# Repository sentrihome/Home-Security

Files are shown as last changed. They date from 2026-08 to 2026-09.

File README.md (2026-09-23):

# Home Security System — Full Architecture

Status: design draft — SoftAP shipping; Pi hub (`pi_hub`) barebones in repo; live/clips/Drive stubs pending full impl
Scope: end-to-end system — ESP32 hardware, provisioning, sensor pairing, security model, protocol specs, Pi/app/cloud product layer (alerts, live, clips), and known open items.
Merges: original ESP32 hardware architecture + `Local-First Architecture Storyboard` (mobile/, Pi, Tailscale, FCM/ntfy, Drive).
Pi software: Python SoftAP gate + one `pi_hub` process (not the retired Node `rasberry_pi_app` / cloud stack) — see **D20** and §13.

---
## Branch Naming Convention
Three types of tasks:
1. Rasberry Pi pie
2. ESP esp
3. Mobile app mob
Name of person working: firstname
Bitesized task: task

So the branch name will be: type-firstname-task

## Quick nav

| Section | Contents |
|---|---|
| [1](#1-system-overview) | System overview & diagram |
| [2](#2-hardware--component-roles) | Every component's role |
| [2.1](#21-esp32-architecture-diagram) | ESP32 hardware diagram — networks, UART, credential flow |
| [3](#3-decision-log) | Locked product choices |
| [4](#4-console-provisioning-flow) | Phone → console WROOM → S3 → home WiFi |
| [5](#5-sensor-pairing-flow) | Phone → sensor → console WROOM |
| [6](#6-default-ap-credentials-setup-time) | Anti-eavesdropping setup credentials |
| [7](#7-credential--key-model) | The three secrets, who holds what |
| [8](#8-failure-handling-provisioning) | WiFi connect failure/retry |
| [9](#9-uart-protocol-wroom--s3) | Frame format, command set |
| [10](#10-setup-ap-encryption) | WPA2 requirement on all setup APs |
| [11](#11-psk-recovery--backup) | Pi as PSK backup, tied to §16 |
| [12](#12-reboot--reconnect-behavior) | Console/S3/sensor reboot handling |
| [13](#13-pi-setup--product-hub) | SoftAP gate → `pi_hub` (live/clips); how it works & deploy |
| [14](#14-intruder-alerts-android-fcm--ios-ntfysh) | FCM (Android), ntfy.sh (iOS) |
| [15](#15-on-demand-livestream-tailscale) | Live only while app is open |
| [16](#16-pi--s3-link-confirmed-endpoints-transport-tbd) | Confirmed Pi↔S3 endpoints; transport still TBD |
| [17](#17-clips-pi-cache--google-drive) | Clip capture, cache, upload, playback |
| [18](#18-google-token-handoff) | OAuth refresh token to Pi |
| [18.1](#181-what-the-pi-needs-phone--pi-contract) | Locked JSON contract for the phone handoff |
| [19](#19-motion-event-pipeline-partially-resolved) | Camera confirmed Pi-only; alert-pipeline scope still open |
| [20](#20-arm--disarm-state-machine) | State ownership, authorization, entry/exit, sensor behavior |
| [21](#21-out-of-scope) | Explicit non-goals |
| [22](#22-open-items) | Full consolidated list |
| [23](#23-physical--manufacturing-notes) | Enclosure & label handling |

---

## 1. System Overview

Three physical subsystems, tied together by two links that are fully specified and one that is not yet:

```mermaid
flowchart TB
  subgraph sensors [Sensor Network]
    Sen1[Sensor WROOM]
    Sen2[Sensor WROOM]
  end

  subgraph console [Central Console]
    CW[Console WROOM<br/>AP + hub]
    S3[ESP32-S3<br/>station, display]
    Sen1 -->|WiFi, sensor_key auth| CW
    Sen2 -->|WiFi, sensor_key auth| CW
    CW <-->|UART, framed| S3
  end

  subgraph home [Home LAN / Cloud Layer]
    Pi[Raspberry Pi<br/>static IP, health, alerts, live, clips]
    FCM[FCM - Android]
    Ntfy[ntfy.sh - iOS]
    Drive[Google Drive]
    TS[Tailscale]
    S3 -.->|§16, endpoints confirmed<br/>transport TBD| Pi
    Pi -->|motion| FCM
    Pi -->|motion| Ntfy
    Pi --> Drive
    Pi <--> TS
  end

  subgraph phone [Mobile App]
    App[React Native app]
    FCM -->|tap| App
    Ntfy -->|tap/open| App
    App <-->|setup, live, clips| Pi
    App -.->|setup| CW
  end
```

**Fully specified today:** sensor ↔ console WROOM (WiFi + `sensor_key`), console WROOM ↔ S3 (UART, framed), phone ↔ Pi (SoftAP setup, health check, Tailscale, OAuth handoff, FCM/ntfy targets, Drive playback).

**Confirmed but not yet fully specified:** S3 ↔ Pi. The endpoints are settled — this is a direct Pi↔S3 link, not routed through the WROOM (§16, §20) — but the transport mechanism (static IP / mDNS / hybrid), framing, and auth are still open. Everything downstream of it (motion-triggered alerts reaching the Pi, PSK backup reaching the Pi, the PIN-set flow) depends on this transport being finalized.

---

## 2. Hardware & Component Roles

| Component | Role | WiFi / Network Mode | Responsibilities |
|---|---|---|---|
| ESP32-S3 | Central console | Station (home WiFi) | Display, keypad (PIN entry for disarm — see §20), stores home WiFi creds, stores sensor keys, **stores the disarm PIN in NVS**, relays credentials/status to console WROOM over UART. Motion/event relay toward Pi confirmed required — see §16, §20. |
| ESP32-WROOM (console-side) | Sensor hub / pairing surface | Access Point (persistent, currently `"espwifi"` — SSID string is not a hard spec requirement, any static value works) | Hosts sensor network, relays sensor data to S3 via UART, validates sensor auth (`sensor_key`), generates pairing credentials and the sensor-network PSK |
| ESP32-WROOM (sensor units) | Sensors | Station → connects to console WROOM's AP | Motion/door/etc. detection, sends events authenticated with `sensor_key`. One of two motion-alert triggers, alongside the Pi's camera detector — see §19. |
| Raspberry Pi | Setup relay, PSK backup, product hub | AP (setup only) → Station (post-setup, static IP `192.168.0.236`) | **Initializes first, before console provisioning — see §4, §13.** SoftAP then **`pi_hub`** on `:4000`. Owns the camera; OpenCV person detection (§19); FCM/ntfy alerts; WebRTC live; Drive clip upload; PSK backup pending §16 |
| Mobile App (React Native, `mobile/`) | Orchestrator / client | N/A | Walks the user through both the Pi setup flow and the console/sensor provisioning flow, holds home WiFi creds in memory only during setup, stores the sensor-network PSK for future pairing, saves the Pi host, registers for push (FCM/ntfy), handles Google OAuth and hands the refresh token to the Pi, plays live (via Tailscale) and clips (via Drive) |

**Confirmed: no camera on any ESP32.** The camera is Pi-attached only. It is no longer monitoring-only: the Pi runs OpenCV person detection on the camera feed as a second, independent motion-alert trigger alongside the ESP32 sensor network. See §19.

**Confirmed: the console has a physical keypad**, used for PIN entry on disarm (§20). **The PIN itself is stored in S3 NVS**, not on the Pi — this creates a flagged tension with the Pi-as-state-authority decision, see §20. **No local audio/siren hardware is planned for initial release** — the console is display + keypad only; Bluetooth speaker support (as a post-launch siren option) is roadmap, not v1.

**Key architectural point:** the console WROOM's AP is *not* home WiFi — it's a separate, persistent local network (currently named `"espwifi"`, but the name itself isn't a spec requirement — see §22 item 6 for the planned move to per-unit SSIDs) that only the S3 (via UART) and paired sensors ever touch. The S3 never joins this network over WiFi. Separately, the Pi runs on the actual home LAN with its own static IP, reachable by the phone directly and, once §16 is resolved, by the S3.

### 2.1 ESP32 Architecture Diagram

```mermaid
flowchart TB
  Phone([Mobile App])
  Router{{Home WiFi Router}}

  subgraph HomeNet [" Home WiFi — station side "]
    S3[ESP32-S3<br/>Central Console<br/>Station + Display + Keypad]
    NVSs[(S3 NVS<br/>home WiFi creds<br/>sensor_keys, disarm PIN)]
  end

  subgraph HSNet [" Console WROOM's Persistent AP — WPA2, SSID not spec-fixed "]
    CW[ESP32-WROOM<br/>Console Hub]
    NVSc[(WROOM NVS<br/>sensor PSK<br/>paired sensor_keys)]
    CW --- NVSc

    Sensor1[Sensor WROOM 1]
    Sensor2[Sensor WROOM 2]
    SensorN[Sensor WROOM ... up to 10]
  end

  Phone -. "1. setup: home WiFi creds<br/>over unique-per-unit setup AP" .-> CW
  CW == "2. UART, framed<br/>home WiFi creds" ==> S3
  S3 -- "2. store" --> NVSs
  S3 -- "3. join as station" --> Router
  S3 == "4. UART: connection result" ==> CW
  CW -. "5. sensor-network PSK<br/>generated, sent to phone" .-> Phone

  Phone -. "6. pairing: PSK + sensor_key<br/>over sensor's own setup AP" .-> Sensor1
  Sensor1 -- "WiFi + sensor_key auth" --> CW
  Sensor2 -- "WiFi + sensor_key auth" --> CW
  SensorN -- "WiFi + sensor_key auth" --> CW

  CW == "ongoing: sensor event relay" ==> S3

  classDef dashed stroke-dasharray: 5 5;
  class Phone dashed;
```

**Reading the diagram:**
- **Dashed arrows** — one-time setup/pairing traffic over a temporary WPA2 setup AP (§4, §5, §6).
- **Double solid arrows (`==`)** — the framed UART link between WROOM and S3 (§9), carrying both provisioning handoff and ongoing sensor-event relay.
- **Single solid arrows** — persistent WiFi connections: sensors to the console WROOM's AP (network-level PSK + application-level `sensor_key`, §7), and the S3 to the home router.
- **Two distinct WiFi networks, never bridged over the air:** home WiFi (S3 only) and the console WROOM's persistent AP network (WROOM + sensors — SSID currently `"espwifi"`, not a fixed spec value). The only link between them is the physical UART trace inside the enclosure (§23).

---

## 3. Decision Log

| ID | Decision | Choice | Notes |
|---|---|---|---|
| D1 | Mobile client | React Native Expo app in `mobile/` | Dev/prod build for push; not Expo Go |
| D2 | Android alerts | `expo-notifications` + FCM | Pi sends FCM on motion |
| D3 | iOS alerts | Public ntfy.sh | Secret topic; no Tailscale required for the buzz |
| D4 | Livestream path | Tailscale to Pi | On-demand, only while app is open |
| D5 | Alert transport | No persistent WebSocket | FCM / ntfy wake the user instead |
| D6 | Clip storage | Pi cache → Google Drive | App reads Drive; no Tailscale needed for clips |
| D7 | Drive auth | Phone Google OAuth → refresh token handed to Pi | Not password-based; `drive.file` scope only |
| D8 | Remote product tunnel | Tailscale (not ngrok/Cloudflare as product) | ngrok OK for ad-hoc dev only |
| D9 | Pi ↔ S3 discovery/transport | Endpoints confirmed (Pi ↔ S3 direct); mechanism **TBD** | mDNS or static IP — see §16 |
| D10 | Cloud S3 / cloud-backend clips | Retired as a product path | Local-first + Drive instead |
| D11 | Sensor-network auth | WiFi PSK (network-level) + `sensor_key` (application-level) | See §7 |
| D12 | Sensor AP fallback on disconnect | None — physical reset only | Prevents jamming-based sensor knockout, see §12 |
| D13 | Setup AP credentials | Unique per unit (batch-derived minimum, MAC-HMAC preferred) | Prevents shared-default eavesdropping, see §6 |
| D14 | Home WiFi credential storage | S3 NVS only | WROOM relays over UART but never persists home WiFi creds — see §7, §2.1 |
| D15 | Camera hardware | Pi-attached only, no ESP32 has a camera | See §2, §19 |
| D16 | UART frame format | `SYNC(2B) \| CMD(1B) \| LEN(2B) \| PAYLOAD \| CRC(1-2B)`, bidirectional | Locked before coding — see §9 |
| D17 | Sensor-network PSK lifecycle | Never regenerated on WROOM reboot — persists across reboots | Regenerating would force re-pairing every paired sensor, see §12 |
| D18 | UART link security | Plaintext, trusted via physical enclosure only | Accepted risk given enclosed PCB, not link-layer encrypted — see §9, §23 |
| D19 | "Encrypted SSID" terminology | Means a high-entropy random **PSK**, not literal SSID encryption | SSIDs broadcast in cleartext regardless — see §7 |
| D20 | Pi product software | **Python SoftAP + one `pi_hub` process** (Flask); do **not** revive Node `rasberry_pi_app` or cloud `:3001` as product | SoftAP is the boot gate; live + clips share one process so they don't fight over `/dev/video0`. Old Node pushed HLS/clips to cloud — local-first serves HLS from Pi and uploads clips to Drive. Code: `rasberry-pi-setup/`. See §13 |

---

## 4. Console Provisioning Flow

Goal: get the S3 onto home WiFi and generate the sensor-network PSK, using the phone as a one-time relay. **Confirmed: this runs after Pi initialization (§13) — Pi setup happens first in the unified onboarding flow.**

1. User enters home WiFi SSID + password once in the app. Held in memory only — never persisted to disk.
2. Phone connects to the console WROOM's setup AP (unique per-unit credentials, WPA2-secured — §6, §10).
3. Phone sends the home WiFi SSID/pass to the WROOM.
4. WROOM relays the credentials to the S3 over UART (framed — §9).
5. S3 attempts to join home WiFi as a station, bounded timeout (~9s), signaled on `IP_EVENT_STA_GOT_IP` (not `WIFI_EVENT_STA_CONNECTED` — association without a leased IP must not report success).
6. S3 reports the connection result (success or specific failure reason) back to WROOM over UART.
7. On success: WROOM generates a random, high-entropy sensor-network PSK (§7), if not already generated on first boot. SSID is a static, fixed string (`"espwifi"`) — not MAC-derived (see §22 item 6 for the planned move to per-unit SSIDs). Brings up its persistent AP under these credentials and sends the PSK back to the phone over the still-open setup link.
8. Phone stores the PSK for future sensor pairing. WROOM's setup AP closes / transitions to sensor-hub-only mode. **Currently commented out in firmware** for debugging — the setup AP is left running past this point so pairing traffic can be inspected/retried without a fresh flash cycle. Must be re-enabled before this leaves dev.
9. WROOM sends the PSK to the S3 over UART; the S3 pushes a copy to the Pi for backup (§16, Pi↔S3 link) — this step depends on §16's transport being finalized; it is not yet a working link.
10. On failure: see §8.

This is a one-time flow, not repeated per sensor.

---

## 5. Sensor Pairing Flow

Done once per sensor, any time after console provisioning, using the PSK the phone already has stored.

1. New sensor boots in AP mode, broadcasting its own unique per-unit setup AP (§6).
2. Phone connects to the sensor's setup AP.
3. Phone sends the console WROOM's sensor-network SSID + PSK to the sensor.
4. Sensor switches to station mode and connects to the console WROOM's persistent AP.
5. Sensor authenticates at the application layer using `sensor_key` (§7) — WiFi-level connection alone does not grant trust.
6. WROOM validates the `sensor_key`, marks the sensor as paired, stores the key in NVS, and begins relaying its events to the S3.

**Constraint — pairing requires the WROOM AP not be at capacity:** the same persistent AP serves both ongoing sensor traffic and new-sensor pairing. Confirmed system limit: sensor count will not exceed 10 (ESP32 SoftAP station cap). App should check station count before initiating pairing and prompt the user if the AP is at or near capacity (exact UX not yet finalized — §22).

---

## 6. Default AP Credentials (Setup-Time)

**Current state: hardcoded shared default.** All units currently ship with the same fixed setup AP credentials, baked into firmware — not per-unit, not batch-derived. This reopens the eavesdropping window the design intends to close: anyone who knows the shared default (e.g. from a leaked unit, teardown, or public firmware) could intercept home WiFi or PSK credentials on any other unit's setup AP during provisioning.

**Planned: unique-per-unit credentials**, not a shared default — this is the fix for the above. Target approach: batch-unique credentials at minimum (shipped per manufacturing batch), with an upgrade path to fully per-device derived credentials:

```
ap_password = HMAC(batch_secret, MAC_address) → encode → print on label/QR
```

No provisioning database required — each unit would derive its own password locally and deterministically at boot from its own MAC address and a batch secret baked into firmware at flash time. Not yet implemented — see §22.

Requirements regardless of tier (apply today, independent of hardcoded-vs-derived):

- Setup AP is WPA2-secured using the current password — never open (§10).
- Setup AP auto-closes after a timeout (2–5 minutes) if no provisioning occurs.
- Re-entering setup/pairing mode after timeout requires a physical button press, not an always-available AP.
- The printed label/QR (once per-unit derivation lands) must not be visible on the outside of retail packaging (§23). Not applicable yet under the current shared-default state — there's nothing unit-specific to print.

---

## 7. Credential & Key Model

Four distinct secrets exist on the ESP32 side. They must not be conflated:

| Secret | Generated by | Purpose | Stored where |
|---|---|---|---|
| Home WiFi SSID/pass | User (typed once) | Lets S3 join home WiFi | S3 NVS only — WROOM does not persist it, only relays via UART |
| Sensor-network PSK | Console WROOM (random, high-entropy, 32-char alphanumeric via `esp_random()`) | WPA2 password for the WROOM's persistent AP | Phone app (primary), Pi (backup — pending §16), WROOM NVS |
| `sensor_key` | Console WROOM, generated uniquely per sensor during pairing | Application-layer authentication of each sensor after WiFi connection | WROOM NVS (per paired sensor), sensor's own NVS |
| Disarm PIN | User, set via the mobile app | Authorizes disarm from the console keypad or the app — see §20 | **S3 NVS.** This is the odd one out: unlike the other three, it's not device-provisioning material, and its storage location creates a flagged tension with the Pi being the arm/disarm state authority — see §20. |

**Why `sensor_key` matters:** the sensor-network PSK is shared across all paired sensors — anyone who obtains it could join the WiFi network. `sensor_key` prevents an arbitrary WiFi-connected device from impersonating a sensor; the WROOM only accepts data from sensors presenting a valid, previously-issued key.

A parallel pattern exists on the product side: the Drive OAuth **refresh token** (§18) is a fifth secret, phone-mediated to the Pi the same way the PSK is phone-mediated to sensors — see §22 for the open question of unifying these into one "phone → device secret handoff" primitive.

Terminology note: nothing here is literal SSID encryption — SSIDs broadcast in cleartext regardless. What's unique/high-entropy is the **PSK** and the **`sensor_key`**, not the SSID (which can simply be MAC-derived and unique).

---

## 8. Failure Handling (Provisioning)

**Confirmed: binary outcome only.** The S3 reports `wifiConnection: true` or `wifiConnection: false` over UART — no reason code is surfaced to the WROOM, the phone, or the app. Wrong password, SSID not found, weak signal, and any other `WIFI_EVENT_STA_DISCONNECTED` cause all collapse to the same `false`. The app's only recourse on failure is to let the user retry.

`wifi_event_sta_disconnected_t->reason` is captured firmware-side (S3) at the point of disconnect but intentionally not forwarded over UART or wired into any command — available for future use if reason-level UX is ever built, but out of scope now.

Rules:

- Setup AP (WROOM or Pi) stays alive across a failed attempt — not torn down until success is confirmed.
- No retry cap on the S3's underlying `esp_wifi_connect()` reconnect loop — it retries indefinitely on disconnect. This is by design: a `false` result has already reached the phone, so the user can re-enter credentials and trigger a fresh attempt at any time; capping retries and requiring a physical button adds friction without a corresponding safety need here (contrast §12's sensor reconnect, where the no-fallback cap is a deliberate anti-jamming measure, not a UX one).

---

## 9. UART Protocol (WROOM ↔ S3)

Bidirectional framing required — both directions carry meaningful payloads.

```
[SYNC: 0xAA 0x55] [CMD: 1B] [LEN: 2B] [PAYLOAD: N bytes] [CRC: 1-2B]
```

Minimum command set to define before coding:

- `WROOM → S3`: home WiFi SSID/pass payload
- `S3 → WROOM`: connection result (success / specific failure reason)
- `WROOM → S3`: sensor event relay (post-pairing, ongoing telemetry)
- `S3 → WROOM`: commands (arm/disarm, etc.) to be relayed onward to sensors
- `S3 → WROOM`: status/heartbeat
- **`WROOM → S3`: motion/event notification tagged for Pi relay** — new command needed once §16's transport lands; distinct from routine telemetry if it needs different urgency/handling given the alert latency budget (§16)

**Flagged ambiguity:** the "commands relayed onward to sensors" line above implies each sensor is told the current arm state directly. But §20 states sensors "relay to the Pi only while armed," and the "sensor event relay" line above describes WROOM→S3 telemetry as unconditional/ongoing — these two aren't obviously the same design. Not yet decided: does arm/disarm state propagate all the way to each sensor (so a disarmed sensor stops transmitting entirely — relevant for battery life, §22 item 10), or do sensors always transmit and the WROOM/S3/Pi layer decides whether to act on it? Added to Open Items (§22).

The disarm PIN does **not** need a UART command — it's confirmed to travel `Pi → S3` directly (§16, §20) and never touches the WROOM.

Without framing, a byte-stream split across two reads on either side will silently corrupt credential or event payloads — this must be a checksummed, framed protocol.

Trust assumption: this UART link is internal to an enclosed PCB inside the house; physical access implies the system is already compromised, so plaintext credentials on this link are an accepted risk given the enclosure.

---

## 10. Setup AP Encryption

All temporary setup APs (Pi, console WROOM, sensor WROOMs) must run WPA2 using their unique per-unit password (§6) — never open. An open setup AP would let anyone in range passively sniff home WiFi credentials and the sensor-network PSK regardless of how unguessable the SSID is. Unique SSID ≠ encryption.

---

## 11. PSK Recovery / Backup

The phone app is not the sole holder of the sensor-network PSK. A backup copy should be pushed to the Raspberry Pi once both are on home WiFi.

**This depends on §16 (Pi↔S3 link), whose endpoints are now confirmed but transport/auth is still undesigned.** Do not build a one-off transport just for this — once §16's transport and auth are chosen, reuse them for the PSK backup push rather than inventing a second channel.

Open items:

- Push vs. pull, and behavior if the Pi is offline or unprovisioned when the PSK is generated — console/sensor setup should not block on Pi availability.
- Whether the Pi is required for day-to-day operation or purely a setup/recovery aid. Current intent: console and sensors keep operating autonomously if the Pi is off or removed — but §16 makes the *alerting* path (not sensor operation) look Pi-dependent. See §16.

---

## 12. Reboot / Reconnect Behavior

- **Console WROOM reboot:** AP credentials restored from NVS immediately on boot — same SSID/PSK, never regenerated (sensors already hold the old ones and would need re-pairing otherwise). Sensor data buffered by WROOM if the S3 link is briefly down, capped queue (e.g., 50 messages), dropping oldest on overflow.
- **S3 reboot:** WROOM's AP and sensor connections unaffected. WROOM buffers sensor events until UART with the S3 resumes.
- **Sensor loses connection to console:** sensor retries using the console's MAC address (not IP) with exponential backoff. **No automatic fallback to AP mode** — deliberate, to prevent a jamming attack from forcing sensors into a re-pairable, disconnected state (e.g., disabling motion detection). Re-entering pairing/setup mode requires a physical action (button hold).

---

## 13. Pi Setup & Product Hub

The Pi runs its own independent SoftAP-based setup flow (implemented under `rasberry-pi-setup/`), separate from the console's provisioning in §4. **Confirmed: this runs first in the unified onboarding flow** — the console's setup (§4) happens after Pi initialization completes, not in parallel and not the other way around.

**D20 (locked):** keep SoftAP in Python; run live + clips + Drive as modules of **one** hub process (`pi_hub`). Do not bring back the old Node `rasberry_pi_app` / cloud-backend split as the product path. SoftAP is the **network gate**; the hub starts only after home Wi‑Fi is up. SoftAP and hub never both bind `:4000`.

### How it works

```
Boot → pi-setup.service → pi-setup-boot.sh
         │
         ├─ no / bad Wi‑Fi  → SoftAP HomeSecurity-Setup + pi-setup-api.py :4000
         │                     (GET /status, /scan, POST /wifi)
         │                     hub stopped; .hub-ready removed
         │
         └─ Wi‑Fi OK at 192.168.0.236
                              → touch ~/homesecurity/.hub-ready
                              → systemctl start pi-hub
                              → one Flask process :4000 (live + clips + Drive)
```

| Piece | Kind | When |
|---|---|---|
| `pi-setup-boot.sh` + SoftAP API | bash + small Flask | Always / unconfigured |
| `pi_hub` (`app.py` + `live` / `clips` / `drive`) | one Python app | Configured + on LAN |
| ffmpeg | subprocess from `live` / `clips` | On demand — not a separate daemon |

**Onboarding steps (product):**

1. Unconfigured Pi boots SoftAP (`HomeSecurity-Setup`).
2. User joins SoftAP; app sends home WiFi credentials (`POST /wifi`).
3. Pi joins home LAN at static IP `192.168.0.236`.
4. App verifies hub (`GET /health` → `mode: "hub"`), saves Pi host.
5. User installs Tailscale on Pi and phone (same tailnet); MagicDNS or `100.x` for live (§15).
6. *(Future)* App pairs a long-lived device token with the Pi for API auth — recommended to also auth §16 PSK backup.

**Hub API (after Wi‑Fi; stubs in repo, full ffmpeg/Drive TBD):**

| Method | Path | Module |
|---|---|---|
| GET | `/health` | hub (`mode: hub`) |
| POST | `/start` `/stop` | `pi_hub.live` — on-demand HLS |
| POST | `/motion` | `pi_hub.clips` → `pi_hub.drive` |
| POST | `/auth/drive` | `pi_hub.drive` — refresh token from app |
| GET | `/hls/<file>` | HLS playlist/segments |

Repo layout: `rasberry-pi-setup/pi_hub/`, units in `rasberry-pi-setup/systemd/`. Detail + troubleshooting: [`rasberry-pi-setup/PI-SOFTAP-README.md`](rasberry-pi-setup/PI-SOFTAP-README.md).

### Deploying changes to the Pi

**CI (every push under `rasberry-pi-setup/`):** GitHub Actions workflow [`.github/workflows/pi-deploy.yml`](.github/workflows/pi-deploy.yml) SSHs to the Pi (via Tailscale when `TS_AUTHKEY` is set), `git fetch` + checkout of that commit, runs `rasberry-pi-setup/scripts/ci-pull-deploy.sh` (install + restart `pi-hub`). Secrets and one-time Pi bootstrap: [`PI-SOFTAP-README.md`](rasberry-pi-setup/PI-SOFTAP-README.md) → **CI deploy**.

**Manual from a LAN machine** (Pi at `192.168.0.236`, user `koushik`):

```bash
cd rasberry-pi-setup
./deploy-to-pi.sh
# optional: PI_IP=192.168.0.236 PI_USER=koushik ./deploy-to-pi.sh
```

What that does:

1. Copies SoftAP scripts, `pi_hub/`, `systemd/*.service`, and `requirements.txt` to `/tmp/rasberry-pi-setup` on the Pi.
2. Runs `sudo ./install-pi-setup.sh` on the Pi — installs deps (Flask, ffmpeg, jq), copies files to `/home/koushik/`, installs systemd units, enables `pi-setup.service`.
3. Hub is **not** auto-enabled for multi-user boot by itself; `pi-setup-boot.sh` starts `pi-hub` only after home Wi‑Fi succeeds.

**After manual deploy:**

```bash
ssh koushik@192.168.0.236 'sudo reboot'   # clean SoftAP → hub handoff
# once on home Wi‑Fi:
curl http://192.168.0.236:4000/health     # expect "mode":"hub"
```

**Iterate without full reinstall** (hub code only, Pi already provisioned):

```bash
scp -r rasberry-pi-setup/pi_hub koushik@192.168.0.236:/home/koushik/
ssh koushik@192.168.0.236 'sudo touch /home/koushik/homesecurity/.hub-ready && sudo systemctl restart pi-hub'
```

**Logs:** SoftAP → `tail -f /var/log/pi-setup.log` · Hub → `journalctl -u pi-hub -f`

### Test protocol

| # | Step | Expected |
|---|---|---|
| 13.1 | Pi in SoftAP or already on LAN | Setup screen usable |
| 13.2 | Complete SoftAP creds; phone on home WiFi | `GET http://192.168.0.236:4000/health` succeeds with `mode: hub` |
| 13.3 | Kill and reopen app | Saved Pi host still present |
| 13.4 | Tailscale connected on Pi and phone | Both show in `tailscale status`; ping works |
| 13.5 | **Fail:** phone on cellular, Tailscale off, hit LAN IP | Health fails; clear "unreachable" UI, not a hang |

**Failure modes:** SoftAP scan fails → not on `HomeSecurity-Setup`. Health 404/timeout → hub not started or still in SoftAP-only mode. Wrong subnet → static IP mismatch. Port conflict → SoftAP API and hub both tried to bind `:4000` (boot script should prevent this).

---

## 14. Intruder Alerts: Android (FCM) & iOS (ntfy.sh)

No persistent WebSocket for alerts (D5) — push services wake the user instead.

### Android — FCM

1. Dev/prod build registers for push (`expo-notifications` + FCM).
2. App sends its FCM device token to the Pi (LAN or Tailscale) once paired.
3. On motion, Pi POSTs to FCM with title/body (and optional deep-link data).
4. OS shows a lock-screen notification.
5. Tap → app opens (Live or Alerts screen).

**Failure modes:** Expo Go used → push unreliable/wrong app id. Token never uploaded → Pi has nothing to target. Pi's outbound network to Google blocked → send fails silently unless logged.

### iOS — ntfy.sh

1. Generate a high-entropy secret topic (treat like a password); store on Pi, show once in app Settings.
2. User subscribes to `https://ntfy.sh/<topic>` (ntfy iOS app for v1).
3. On motion, Pi POSTs to `https://ntfy.sh/<topic>`.
4. User sees the notification; opens the app when ready.
5. Live still requires Tailscale (§15) — ntfy carries no video.

**Failure modes:** topic leaked → strangers can spam or snoop titles. ntfy.sh outage → no iOS buzz (LAN live still works independently). User never subscribed → silent miss.

### Combined test targets

Motion → notification within **≤ 15 seconds** on both platforms. This budget matters directly for §16 — see the latency note there.

---

## 15. On-Demand Livestream (Tailscale)

Live only while the app is open — no background streaming.

1. User opens the app (often from an FCM/ntfy tap).
2. App resolves the Pi's base URL: prefers Tailscale host when off-LAN, else saved LAN IP.
3. Optional `POST /start`, then play HLS from the Pi.
4. User leaves the Live screen → stop requesting segments; no persistent socket.
5. If Tailscale is disconnected → clear error: enable Tailscale or join home WiFi.

**Failure modes:** playing the LAN IP while away → timeout. Firewall/CGNAT rare with Tailscale but DERP relay may add latency. Heavy cellular data usage — warn in UI if needed.

---

## 16. Pi ↔ S3 Link (Confirmed Endpoints, Transport TBD)

**Status: endpoints confirmed, transport/framing/auth still undesigned.** This is the single biggest remaining gap connecting the ESP32 hardware architecture to the product layer.

**Confirmed: this link connects the Pi directly to the S3** — not the WROOM. Consistent with the rest of this document's topology (§1, §2.1), the S3 is the only ESP32 with home-LAN reachability; the WROOM has no home-WiFi connectivity and is not involved in Pi-facing traffic. The WROOM's role remains limited to the isolated sensor-network AP and UART with the S3.

Everything downstream depends on this link:

- §11's PSK backup push (S3 → Pi, sourced from the WROOM via UART, then relayed by S3)
- Motion-triggered alerts (§14) actually firing, confirmed required per §19's resolved motion-alert pipeline
- The PIN-set flow and arm/disarm coordination (§20), confirmed to route `Pi → S3` directly

### Candidates (not yet chosen)

| Option | Idea | Pros | Cons |
|---|---|---|---|
| Static IP | Pi stays at `192.168.0.236`; S3 configured with that IP | Simple; already assumed elsewhere in the Pi setup docs | Breaks if the subnet changes |
| mDNS | Pi advertises e.g. `homesecurity-pi.local` | No hard-coded IP | mDNS can be flaky on some routers / ESP network stacks |
| Hybrid | Static default + mDNS fallback | Resilient | More firmware and app work |

### What needs to be specified once a candidate is chosen

- **Transport & framing** for S3 → Pi messages (motion events, PSK backup), analogous to §9's UART framing.
- **Authentication** — should not be an unauthenticated push; anything on the LAN claiming to be "the Pi" (or "the console") must not be trusted by default. Recommended: reuse the "paired device token" mechanism already planned for phone↔Pi auth (§13, step 6) rather than inventing a third auth scheme.
- **Latency budget** — the alert path's ≤15s target (§14) has to cover sensor → WROOM (radio) → UART (WROOM→S3) → this link (S3→Pi) → Pi → FCM/ntfy → phone OS, end to end. Each hop needs its own bounded latency; there isn't much slack in 15 seconds once every hop is accounted for.
- **Availability behavior** — if this link is down (Pi off, rebooting, off the LAN), does the console have any fallback alerting path, or is a live Pi a hard dependency for every motion alert? This is currently undefined and should be decided explicitly rather than defaulting to "no alert."

---

## 17. Clips: Pi Cache → Google Drive

1. User signs into Google in the phone app (`access_type=offline`, `drive.file` scope).
2. App sends the refresh token (or auth code) + OAuth client id/secret + email to the Pi over LAN or Tailscale (§18).
3. On an event: Pi writes the clip to local cache (`homesecurity/clips/clip-*.mp4`), then uploads to Drive with a refreshed access token into an app-created **SentriHome** folder.
4. App lists/plays clips via Drive (the user's own session) — not via the Tailscale video tunnel.
5. Pi may prune the local cache after successful upload (retention policy TBD, §22 #9).

Pi implementation (`rasberry-pi-setup/pi_hub/drive.py`) is live: motion/detection already call `drive.upload_clip()`. Uploads stay private (`drive.file` only; no "anyone with the link"). They no-op with a loud error until the phone completes §18.

### Test targets

- Clip appears in Pi cache within budget after a triggering event.
- Clip appears in the user's Drive folder (`SentriHome`) after upload.
- Clips remain listable/playable from Drive with Tailscale fully off (cellular only) — this path must not depend on Tailscale.
- Revoked Google access → next upload fails loudly (`invalid_grant` on `GET /auth/drive`), app prompts re-auth (not a silent drop).

**Failure modes:** missing `prompt=consent` → no refresh token issued. Upload quota / Drive API errors. App signed into a different Google account than the one whose token lives on the Pi.

---

## 18. Google Token Handoff

```mermaid
sequenceDiagram
  participant App
  participant Google
  participant Pi
  participant Drive
  App->>Google: OAuth offline consent, drive.file scope
  Google-->>App: refresh_token + email
  App->>Pi: POST /auth/drive (LAN or Tailscale)
  Pi->>Pi: Store refresh_token encrypted at rest
  Pi->>Drive: Upload clip with refreshed access_token
  App->>Drive: List/play clips as the signed-in user
```

Rules:

- Hand off only over home LAN or Tailscale — never over a raw, unauthenticated public URL.
- Store on the Pi **encrypted at rest**; never write tokens to app logs or setup logs.
- Scope limited to `drive.file` — only files the app itself creates/manages, not full Drive access.
- Provide a revoke/re-auth path in Settings if uploads start failing.
- The OAuth **client_id and client_secret travel with the refresh token**. A refresh token cannot be used by a different Google Cloud client than the one that issued it, so the phone and the Pi must share one Web-application OAuth client.

This is the same "phone-mediated secret handoff to a persistent device" pattern as the sensor-network PSK (§7, §11) and, once designed, the §16 auth token — worth eventually converging on one shared primitive instead of three independently-built ones (§22).

Phone implementation guide (Expo template, Cloud Console steps, Settings UX): **[DOCUMENTATION.md — Phone: Google Drive OAuth](DOCUMENTATION.md#phone-google-drive-oauth-and-token-handoff)**.

### 18.1 What the Pi needs (phone → Pi contract)

`POST /auth/drive` on port 4000. JSON, one of:

| Field | Required | Notes |
|---|---|---|
| `refresh_token` | Shape A | Phone already exchanged the auth code |
| `auth_code` (alias `server_auth_code`) | Shape B | Pi exchanges it; send `code_verifier` if PKCE was used |
| `code_verifier` | Shape B + PKCE | Expo AuthSession default |
| `redirect_uri` | Shape B | Must match the Google Cloud authorized URI (default `homesecurity://oauth`) |
| `client_id` | **always** | Same Web client the phone used |
| `client_secret` | **always** | Same Web client the phone used |
| `email` | recommended | Pi fetches from userinfo if omitted |

`GET /auth/drive` returns `{ linked, email, folder_name, folder_id, last_upload, error }` and never the token. `DELETE /auth/drive` forgets it. `/health` includes the same object under `drive`.

---

## 19. Motion Event Pipeline (Resolved)

**Confirmed: no ESP32 (S3 or WROOM) has a camera.** The camera is Pi-attached only, matching the product-layer diagram's `Camera → Pi` line directly.

**Superseded: camera-based detection has shipped, ahead of the roadmap.** This section
previously stated the camera was monitoring/live-view only and that the ESP32 sensor network
was the system's **only** motion-alert trigger. That is no longer accurate. The Pi now runs
person detection on the camera feed (`rasberry-pi-setup/pi_hub/detect.py`: MobileNet-SSD via
OpenCV's DNN module, reading the shared MediaMTX RTSP path).

There are therefore **two independent triggers** into one clip/alert pipeline:

```
A) Sensor (WROOM) → Console WROOM (WiFi, sensor_key auth) → Console S3 (UART) → Pi (§16 link) ┐
                                                                                              ├→ clip + Drive upload → Notification (FCM/ntfy)
B) Camera → MediaMTX (RTSP) → Pi OpenCV detector (person-gated) ───────────────────────────────┘
```

Both converge on `pi_hub.events.handle_motion()`, so a camera detection and a manual/sensor
trigger produce byte-identical downstream behaviour. Trigger A still depends on §16 and its
≤15s latency budget (§14); trigger B is entirely local to the Pi and works even with §16
unresolved — which is why it shipped first.

**Detection is class-gated, not motion-gated.** Only labels in
`config.DETECT_TARGET_LABELS` (default: `person`) raise an event, and a cooldown window
suppresses repeat events. This is a deliberate false-positive strategy: a pet or a moving
curtain produces frames but not alerts, which is the failure mode naive frame-differencing
motion detection suffers from.

**Still open:** whether the camera detector should *corroborate or suppress* sensor-triggered
alerts rather than firing independently (e.g. sensor trip + no person seen → lower-confidence
alert). Today the two triggers do not consult each other. See §22.

---

## 20. Arm / Disarm State Machine

**Previously entirely missing from this document — this is the core logic that makes the system a security system rather than just a sensor/notification pipeline.** State ownership is now resolved; one new topology question has surfaced from that resolution and needs a call before implementation (see below).

### State ownership — resolved, with a flagged topology question

- **The Pi remains the source of truth for armed/disarmed *state*.**
- **Confirmed resolution: the S3 validates the PIN locally.** Round-tripping every disarm attempt through the Pi for validation was rejected as too slow — and the Pi doesn't hold the PIN anyway, so it couldn't validate even if asked to. The S3 checks the PIN against its own NVS and acts on it immediately; the Pi is informed/acknowledged afterward so its own arm/disarm state and alert-suppression logic stay in sync. This is resolution **(a)** from the previous draft of this section.

### Confirmed PIN-set flow

**Resolved: the Pi talks directly to the S3, not the WROOM** — consistent with the rest of this document's topology (§1, §2.1), where the S3 is the only ESP32 with home-LAN reachability.

When a user sets a disarm PIN via the mobile app:

```
Phone App → Pi → Console S3 (via §16 link, stored in S3 NVS)
```

Console S3 acknowledges receipt back through the same path once the PIN is stored, so the app can confirm the set succeeded. The WROOM is not involved in this flow at all — it doesn't hold the PIN and doesn't need to relay it.

This resolves the topology question raised in the previous revision of this document: §16 is confirmed as a **Pi ↔ S3** link, not Pi ↔ WROOM. No dual AP+STA capability is needed on the WROOM.

### Authorization

- **Arm**: mobile app or central console. **No PIN required.**
- **Disarm**: mobile app or central console. **PIN required**, checked against the PIN stored in S3 NVS. The user may set the same PIN for both paths, or different ones, via the mobile app.
- This is an intentionally asymmetric model — arming is low-friction, disarming has a deliberate check.

**Confirmed: the console has a physical keypad**, used to enter the PIN for a console-initiated disarm (also noted in §2).

### Entry/exit delay

- **None.** No grace period on entry or exit.
- **While armed:** a sensor trigger while armed relays the event through the pipeline below.
- **While disarmed:** sensors produce no relay and no alert (and no logging — see below).

### Confirmed motion-alert data flow

On a sensor trigger while armed, the event flows:

```
Sensor (WROOM) → Console WROOM → Console S3 (UART) → Pi (§16 link) → Notification System (FCM/ntfy)
```

This is the same pipeline established in §19, terminating in a **phone push notification via the Pi**.

**Confirmed: no local audible/beep hardware is planned for initial release.** There is no buzzer, speaker, or siren on the console at launch — the phone push notification is the entire alert output for v1. **Planned post-release:** Bluetooth speaker pairing, allowing a user-supplied Bluetooth speaker to act as a local siren. This is a roadmap item, not part of the initial build — see §21 (Out of Scope) for the launch/post-launch boundary.

### Sensor behavior by arm state

- Sensors relay to the Pi (triggering a push notification) only while armed.
- **Confirmed: no logging while disarmed.** Disarmed-state sensor activity is not recorded anywhere. If a general event history/log is ever built (§22, item 13), it will only ever reflect armed-state activity, by design — this is worth keeping in mind if that feature gets built later, since it means the system has no record of activity that happened while disarmed.

### What this section does *not* yet cover

- Partial/zone arming (e.g., "arm perimeter only," "stay" vs. "away" modes common in commercial systems) — not requested, assumed out of scope unless specified otherwise.
- Auto-arm/auto-disarm based on schedule or geofencing — not mentioned, treated as a future feature if ever wanted.
- What happens to an **in-progress notification** if the system is disarmed mid-trigger — not yet specified, and now also depends on resolving the state-ownership tension above.

---

## 21. Out of Scope

| Item | Why |
|---|---|
| Persistent WebSocket / SSE for alerts | Replaced by FCM + ntfy (D5) |
| S3 / cloud-backend as clip or live CDN | Retired — local-first + Drive instead (D10) |
| Cloudflare Tunnel / ngrok as **product** remote access | Tailscale chosen (D8); ngrok OK for brief dev only |
| Sensor AP-mode fallback on disconnect | Explicitly rejected — jamming risk (D12) |
| Replacing the existing Pi SoftAP wizard | Keep SoftAP; extend with `pi_hub` after Wi‑Fi (D20) |
| Reviving Node `rasberry_pi_app` + cloud `:3001` as product | Retired — Python hub serves HLS locally and uploads clips to Drive (D10, D20); mine old Node only for ffmpeg ideas if found elsewhere |
| Relying on Expo Go for FCM | Push unreliable under Expo Go; use dev/prod builds |
| Local buzzer/siren hardware on the console (v1) | Confirmed: no beep/audio hardware planned for initial release — see §20 |
| Bluetooth speaker pairing as a local siren | Confirmed roadmap item, post-launch — not part of this design pass |

---

## 22. Open Items

Consolidated list, roughly in priority order for what blocks further design vs. implementation:

1. **§16 — link design (highest priority):** endpoints confirmed (Pi ↔ S3 directly), transport still needs choosing: static IP / mDNS / hybrid, plus framing and auth. Required for the confirmed alert pipeline (§19), the PIN-set flow (§20), and PSK backup (§11).
2. **§9/§20 — does arm/disarm state reach individual sensors?** Unclear whether sensors are told the arm state directly (stopping transmission entirely while disarmed) or always transmit while the WROOM/S3/Pi layer decides whether to act on it. Affects sensor battery life (item 10 below) and the exact UART command set.
3. **PSK backup auth**: confirm the §13 "paired device token" is meant to also authenticate the §11 PSK backup push (recommended, not yet stated).
4. **Re-provisioning vs. factory reset**: whether changing home WiFi (router replaced, password changed) and "forget all sensors" are the same physical action or distinct ones. **Explicitly deferred (TBD)** — not a near-term blocker.
5. **Sensor message integrity beyond `sensor_key`**: replay protection, if any sensor reading is ever used to drive an action rather than just display/log data.
6. **Multi-console households / MAC-derived SSID (planned, not yet implemented)**: SSID is currently a static string (`"espwifi"`) for every unit — fine for a single console, but indistinguishable between two consoles in one home. Planned fix: move to a MAC-derived SSID per unit (D19 already establishes this doesn't need to be high-entropy/secret, just unique — SSIDs broadcast in cleartext regardless).
7. **OTA update mechanism and signing**, once devices are in the field with unique per-device secrets.
8. **Pairing UX at the 10-sensor cap**: exact behavior when pairing is attempted while the WROOM AP is at or near capacity.
9. **Clip retention policy** on the Pi's local cache after a successful Drive upload.
10. **Unify the phone-mediated secret handoffs** (home WiFi creds → S3, sensor PSK → Pi, disarm PIN → S3, Drive refresh token → Pi) into one documented primitive rather than four separately-designed ones (§7, §18).
11. **System-wide gaps not yet designed at all**: sensor power/battery management, internet-outage alert fallback (what happens to alerting if home internet is down, since the whole pipeline routes through the Pi to FCM/ntfy), tamper detection, multi-user/multi-phone pairing, general event history/log (which, per §20, will only ever cover armed-state activity by design), and full Pi API authentication coverage. None of these have a home in this document yet.
12. **§6 — per-unit setup AP credential derivation (planned, not yet implemented)**: setup AP credentials are currently a hardcoded shared default across all units, not batch- or MAC-derived. Reopens the eavesdropping concern §6 was written to close. HMAC(batch_secret, MAC_address) approach is specified but not built — needs to land before manufacturing/label pipeline (§23) can proceed.

---

## 23. Physical / Manufacturing Notes

- Printed labels/QR codes carrying setup AP credentials must be inside the packaging (or under a peel-back sticker), not visible on the outer box — the label is a bearer secret once printed.
- UART lines between WROOM and S3 are treated as trusted only because the PCB is enclosed inside the house; this assumption breaks if the UART is ever exposed via an accessible debug header.

---

## Revision history

| Date | Change |
|---|---|
| 2026-08-18 | **Pi Drive upload shipped.** `pi_hub/drive.py` stores the phone-handed refresh token encrypted at rest (Fernet), refreshes access tokens, creates a `SentriHome` folder, and uploads event clips. `/auth/drive` is now GET/POST/DELETE; `/health` exposes `drive` status without secrets. Locked the phone→Pi JSON contract in §18.1 (`client_id`/`client_secret` required — refresh tokens are bound to the issuing OAuth client). Phone implementation guide: `DOCUMENTATION.md`. |
| 2026-08-13 | **Camera-based motion detection shipped, superseding the §19 "monitoring-only" decision.** `pi_hub/detect.py` runs MobileNet-SSD via OpenCV DNN against the shared MediaMTX RTSP feed (not `/dev/video0` — the single-publisher rule in §19/`camera.py` still holds) and raises person-gated events through the new `pi_hub/events.py`, the same pipeline `POST /motion` uses. Rewrote §19 around two independent triggers instead of one; updated §2 and the component table, which both still claimed the camera did no detection. Notable: this trigger is entirely local to the Pi, so it works with §16 still unresolved — the reason it shipped ahead of the sensor path. New open item in §19: the two triggers do not corroborate each other. Weights are sha256-verified at fetch time, not vendored. |
| 2026-08-02 | Consolidated ESP32 hardware architecture and Local-First Storyboard into a single full architecture document. Flagged §16 (ESP↔Pi link) and §19 (camera/motion ownership) as the two unresolved cross-cutting gaps. |
| 2026-08-02 | Confirmed: no camera on any ESP32 (S3 or WROOM) — camera is Pi-attached only. Updated §2 and §19 accordingly; narrowed §19 to the remaining open question of whether ESP32 sensor events also feed the alert pipeline. |
| 2026-08-02 | Added §20 (Arm/Disarm State Machine) — previously entirely undocumented. Captured: Pi as state authority, app/console arm with no PIN, app/console disarm requiring PIN, no entry/exit delay, armed-trigger beep. Flagged open questions: console PIN input hardware, beep vs. push semantics, disarmed-state logging. Renumbered §20-22 to §21-23 accordingly. |
| 2026-08-02 | Resolved several §20/§19/§13 open questions: confirmed console keypad (§2, §20); confirmed motion-alert pipeline terminates in a Pi-driven phone push, with the console beep as parallel local feedback (§19, §20); confirmed camera is monitoring-only for now, ESP32 sensor network is the sole motion-alert trigger, camera-based detection is post-launch (§19); confirmed Pi initializes before console provisioning (§4, §13). Updated Open Items (§22) to remove resolved items and add newly surfaced smaller gaps (PIN offline-fallback, console beep hardware). |
| 2026-08-02 | Confirmed: disarm PIN stored in S3 NVS (§7, §20) — creates a flagged tension with the Pi-as-arm/disarm-authority decision, needs explicit resolution before implementation. Confirmed: no local beep/siren hardware at launch; Bluetooth speaker siren support is a post-launch roadmap item (§20, §21). Confirmed: no event logging while disarmed (§20). Updated §2, §7, §21, §22 accordingly. |
| 2026-08-02 | Resolved PIN-validation ownership: S3 validates the PIN locally, Pi is informed afterward (§20). Confirmed PIN-set flow: Phone App → Pi → console WROOM → console S3, with acknowledgment back. Flagged a new topology inconsistency: this flow has the Pi talking to the WROOM directly, which conflicts with the WROOM's documented lack of home-LAN connectivity — needs resolution before §16 can be designed (§16, §20, §22 item 1, now top priority). Added conditional UART command for PIN relay/ack (§9). |
| 2026-08-02 | Resolved the topology question from the previous entry: **confirmed the Pi talks directly to the S3, not the WROOM.** Renamed §16 to "Pi ↔ S3 Link (Confirmed Endpoints, Transport TBD)." Removed the WROOM hop from the PIN-set flow (§20) and the conditional UART command it required (§9) — the disarm PIN never touches the WROOM. Updated D9, quick-nav, and all cross-references accordingly. Removed the now-resolved topology item from Open Items (§22). |
| 2026-08-02 | **Full-document audit for repeated/systemic issues.** Fixed: duplicated "Terminology note" paragraph in §7 (verbatim copy-paste artifact); stale §4 step 9 still saying the WROOM pushes the PSK to the Pi (contradicted the confirmed Pi↔S3-only topology, now corrected to WROOM→S3→Pi); stale §1 diagram/prose still framing the S3-Pi link as fully unspecified and labeled "Act 6" (updated to reflect confirmed endpoints, transport TBD); §2.1 diagram not reflecting the confirmed keypad/PIN-in-NVS hardware (added). Flagged a new open item: whether arm/disarm state propagates to individual sensors or is enforced centrally (§9, §22 item 2) — §9's "commands relayed onward to sensors" line and §20's "sensors relay only while armed" line don't obviously describe the same mechanism. Noted as a general pattern: diagrams in this document have repeatedly lagged behind text-level decisions and need a deliberate check on each revision, not just prose cross-references. |
| 2026-08-03 | **D20 — Pi software stack.** SoftAP stays Python; product features run as one `pi_hub` Flask process after home Wi‑Fi (live HLS + clips + Drive stubs). Explicitly rejected reviving Node `rasberry_pi_app` / cloud `:3001` as product. Expanded §13 with boot handoff, hub API table, and deploy instructions (`deploy-to-pi.sh`). Updated §2 Pi row, §21 out-of-scope, and `rasberry-pi-setup` docs. |
| 2026-08-15 | **§4/§8 — provisioning result firmware fix.** Confirmed the S3 must signal WiFi join result on `IP_EVENT_STA_GOT_IP`, not `WIFI_EVENT_STA_CONNECTED` — association without a leased IP was reporting false success, silently killing the §16 alert path with no error surfaced anywhere. Updated §4 step 5 timeout from ~15–20s to ~9s accordingly. Collapsed §8's reason-code failure table to a confirmed binary `true`/`false` outcome — disconnect reason is captured firmware-side but not forwarded over UART or into app UX. Retry cap dropped from §8's rules: S3's reconnect loop retries indefinitely by design, since the phone already receives `false` and can re-trigger the flow without a physical-button requirement. §9/D16 reviewed and confirmed unchanged — both already specified `SYNC: 0xAA 0x55`; the `'c'`/`'8'` sync bytes seen in review were a firmware bug, not a spec deviation. |
| 2026-08-15 | **§7 — PSK length.** Sensor-network PSK confirmed as 32-char alphanumeric (was ~20-char) — within the 63-char WPA2 PSK limit, higher entropy for the shared network secret. |
| 2026-08-15 | **§4 — SSID confirmed static, not MAC-derived.** WROOM's persistent AP SSID is a fixed string (`"espwifi"`) for now; MAC-derivation moved from §4 step 7 to a planned item under §22 item 6, scoped to solving multi-console SSID collisions later. No security impact per D19 — SSID uniqueness was never load-bearing, only the PSK is. |
| 2026-08-15 | **§4 step 8 — flagged as dev-only state.** Setup-AP-close/transition-to-hub-only is currently commented out in firmware for debugging (setup AP stays up past pairing so traffic can be inspected without reflashing). Documented as a known pre-ship gap, not a spec change — must be re-enabled before release. |
| 2026-08-15 | **§6 — confirmed setup AP credentials are currently a hardcoded shared default**, not batch- or MAC-derived. Per-unit derivation (`HMAC(batch_secret, MAC_address)`) moved to a planned item under §22 item 12 — reopens the eavesdropping window §6 exists to close until implemented; flagged as a manufacturing-pipeline (§23) dependency. |
| 2026-08-15 | **§2 — confirmed the console WROOM's persistent AP SSID name is not a hard spec requirement.** Doc previously named it `"HomeSecurity"` as if fixed; updated §2, §2.1 diagram, and diagram-reading notes to describe it generically (currently `"espwifi"`, any static value is acceptable). Does not affect §22 item 6 (per-unit/MAC-derived SSID), which remains the tracked planned change; this only removes the specific fixed-name requirement, not the uniqueness question. Pi's `"HomeSecurity-Setup"` SoftAP name (§13) is unaffected — separate device, separate flow. |

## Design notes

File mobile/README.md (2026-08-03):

# Home Security — React Native (Expo)

Mobile client framework for the Home Security stack. Mirrors the main flows from `ESP32PairingApp` against `cloud-backend` (port 3001) and the Pi backend (port 4000).

## Stack

- Expo SDK 57 + Expo Router (file-based navigation)
- TypeScript
- Secure session storage (`expo-secure-store` / AsyncStorage on web)

## App map

| Area | Route | Notes |
|---|---|---|
| Live stream | `(tabs)/index` | Pi start/stop/motion + cloud status stubs |
| Clips | `(tabs)/clips` | `GET /api/events` + thumbnail URLs |
| Setup | `(tabs)/setup` | Pi SoftAP provisioning + device linking |
| Settings | `(tabs)/settings` | Cloud URL + account |
| Sign in | `/login` | Token paste until OAuth deep links are wired |

## Framework layout

```
mobile/
  app/                 # Expo Router screens
  components/ui/       # Shared UI primitives
  context/             # AuthProvider
  lib/api.ts           # cloudApi + piApi clients
  lib/config.ts        # Default backend URLs
  lib/storage.ts       # Session + URL persistence
  types/               # Shared TypeScript types
```

## Run

```bash
cd mobile
npm start
# then press i / a / w, or:
npm run ios
npm run android
```

Optional env overrides (create `mobile/.env`):

```
EXPO_PUBLIC_CLOUD_URL=https://your-ngrok.ngrok-free.app
EXPO_PUBLIC_PI_URL=http://192.168.x.x:4000
```

### Device URL tips

- **Android emulator → host:** `http://10.0.2.2:3001`
- **iOS simulator → host:** `http://localhost:3001`
- **Physical device:** LAN IP or ngrok (same URL as Google OAuth redirect / `credentials.json`)

## Features

### Pi SoftAP Provisioning ✓

First-time WiFi setup for Raspberry Pi:

1. User joins Pi hotspot (`HomeSecurity-Setup` / `setup1234`)
2. App scans available WiFi networks via `http://10.42.0.1:4000/scan`
3. User selects home network and enters password
4. App sends credentials via `POST http://10.42.0.1:4000/wifi`
5. Pi switches to home WiFi automatically
6. User reconnects phone to home WiFi and links device

See `../PI-SOFTAP-README.md` for Pi setup instructions.

## Next wiring targets

1. ✓ Pi SoftAP provisioning (setup screen)
2. Complete Google OAuth via `homesecurity://` deep link after `/auth/google/callback`
3. HLS player for `cloudApi.playlistUrl(deviceId, token)`
4. Clip video playback using `cloudApi.clipUrl(eventId, token)`

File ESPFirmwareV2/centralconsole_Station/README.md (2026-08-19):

# Central Console (ESP32-S3) — Home Security System

An ESP32-S3 firmware serving as the central control console for a home security system. It manages a TFT display with touch input, communicates with external sensor devices over UART, connects to WiFi (station mode), and exposes a lightweight HTTP API.

## Overview

| Component | Details |
|---|---|
| **MCU** | ESP32-S3 |
| **Framework** | ESP-IDF + Arduino-ESP32 v3.3.6 |
| **Display** | 480×320 TFT LCD (SPI) with touch controller, using `TFT_eSPI` |
| **UART** | UART1 at 230,120 baud — receives data from external sensor devices |
| **WiFi** | Station mode (connects to SSID `espwifi`) |
| **HTTP API** | `/health` (GET) and `/pass` (POST) endpoints |

## Wiring

### TFT Display (SPI)

| TFT Pin | Function | GPIO  |
|---|---|---|
| SCK | SPI Clock | GPIO12|
| SDI | SPI Data In (MOSI)  | GPIO11|
| SDO | SPI Data Out (MISO) | GPIO13|
| CS | Chip Select | GPIO10|
| DC | Data/Command | GPIO9 |
| RST | Reset | GPIO14|
| BL | Backlight | GPIO15|

### Touch Controller (SPI)

| Touch Pin | Function | GPIO  |
|---|---|---|
| TCK | SPI Clock | GPIO12|
| TDI | SPI Data In (MOSI)  | GPIO11|
| TDO | SPI Data Out (MISO) | GPIO13|
| TCS | Touch Chip Select | GPIO8 |
| PEN | Touch Interrupt (IRQ)| GPIO7|

### UART1 (Sensor Communication)

| Function | GPIO  |
|---|---|
| TX | GPIO17|
| RX | GPIO18|
| RTS | GPIO4 |
| CTS | GPIO5 |

**Notes:**
- TFT display and touch controller share the same SPI bus; each has its own CS line (GPIO10 / GPIO8).
- DC (GPIO9) selects between command and data mode for the TFT.
- RST (GPIO14) resets the TFT display.
- BL (GPIO15) controls the display backlight (can often be tied to 3.3V or PWM-controlled for brightness).
- PEN (GPIO7) is the touch controller's interrupt/pen-down signal, used to detect touch events without polling.

### 4x4 Keypad

| Keypad Pin | Function | GPIO  |
|---|---|---|
| R1 | Row 1 | GPIO42|
| R2 | Row 2 | GPIO41|
| R3 | Row 3 | GPIO40|
| R4 | Row 4 | GPIO39|
| C1 | Column 1 | GPIO38|
| C2 | Column 2 | GPIO37|
| C3 | Column 3 | GPIO36|
| C4 | Column 4 | GPIO35|

### Pin Summary (by GPIO)

| GPIO | Connected To |
|---|---|
| GPIO4  | UART RTS |
| GPIO5  | UART CTS |
| GPIO7  | Touch PEN (IRQ) |
| GPIO8  | Touch TCS (CS) |
| GPIO9  | TFT DC |
| GPIO10 | TFT CS |
| GPIO11 | Shared SDI/TDI (MOSI) |
| GPIO12 | Shared SCK/TCK (Clock)  |
| GPIO13 | Shared SDO/TDO (MISO)  |
| GPIO14 | TFT RST |
| GPIO15 | TFT BL |
| GPIO17 | UART TX |
| GPIO18 | UART RX |
| GPIO35 | Keypad C4 (Column 4) |
| GPIO36 | Keypad C3 (Column 3) |
| GPIO37 | Keypad C2 (Column 2) |
| GPIO38 | Keypad C1 (Column 1) |
| GPIO39 | Keypad R4 (Row 4) |
| GPIO40 | Keypad R3 (Row 3) |
| GPIO41 | Keypad R2 (Row 2) |
| GPIO42 | Keypad R1 (Row 1) |

## Firmware Structure

```
main/
├── main.cpp              ← entry point (app_main), init & main loop
├── core.h / .cpp         ← shared log() helper
├── display.h / .cpp      ← TFT initialization, armed/unarmed UI rendering, touch processing
├── connectivity.h / .cpp ← WiFi station setup & auto-reconnect handler
├── app_uart.h / .cpp     ← UART1 driver config & receive polling
├── httpendpoints.h / .cpp← HTTP server with /health and /pass endpoints
└── uielements.h / .c     ← UI sprite assets (idle, armed, unarmed bitmaps)
```

## Runtime Flow

```
app_main()
  ├── initArduino()         — Arduino ESP32 compatibility layer
  ├── Serial.begin(115200)
  ├── wifi_init()           — connect to SSID espwifi via ESP-IDF WiFi driver
  ├── uart_init()           — install UART1 driver at 230,120 baud
  └── while(true):
      ├── display.init()    — one-shot: boot splash → idle screen
      ├── display.process() — read touch → toggle armed/unarmed state
      └── uart_receive()    — poll UART1 for incoming sensor data
```

## Build & Flash

```bash
# Set target and build
idf.py set-target esp32s3
idf.py build

# Flash (adjust COM port)
idf.py -p /dev/ttyUSB0 flash
```

### Build Configuration

This project requires specific sdkconfig and partition settings that differ from defaults:

| Setting | Value | Why |
|---|---|---|
| **Flash size** | 8MB (`CONFIG_ESPTOOLPY_FLASHSIZE_8MB`) | Board has 8MB flash (detected via `esptool.py flash_id`) |
| **TFT pins** | MOSI=11, SCLK=12, MISO=13, CS=10, DC=9, RST=14, BL=15 | Match physical wiring to the TFT_eSPI driver |
| **Touch** | TOUCH_CS=8, `CONFIG_ENABLE_TOUCH=y` | SPI touch controller on GPIO8 |
| **Partition table** | Custom `partitions.csv` (factory = `0x1F0000`) | Overrides arduino-esp32's default 1MB partition scheme |

The TFT_eSPI library reads pin configuration from sdkconfig (Kconfig), not from `User_Setup.h`. If you reset menuconfig, you must re-apply these settings.

---

## Development Timeline

| Date | Milestone | Details |
|---|---|---|
| 2026-03-23 | **Project reinitialization** | Cleaned up repo, started screen component work and prototyping |
| 2026-03-24 | Screen component | Got display driver compiling, added screen component |
| 2026-03-27 | Display okay | Display was functional |
| 2026-03-29 | UI rehaul | Major UI overhaul |
| 2026-06-04 | 3D object files | Added 3D model files (project casing) |
| 2026-06-09 | **ESP32 firmware reboot** | Fresh start on the ESP32 firmware codebase |
| 2026-06-11 | Display configuration | Configured TFT display with correct SPI wiring |
| 2026-06-16 | UI framework | Restructured display module, added armed ↔ disarmed state transition, fixed full-screen redraw bug when returning from armed to disarmed, mapped touch coordinates to actions |
| 2026-06-16 | Touch command integration | Implemented `Touch` class — reads raw touch coords via SPI, maps a gesture area for ARM/DISARM toggle |
| 2026-06-18 | ESP-IDF migration | Transitioned codebase to ESP-IDF |
| 2026-06-29 | WiFi driver revision | Rewrote WiFi init using `esp_wifi`/`esp_event` APIs, solved auto-reconnection on disconnect |
| 2026-06-30 | AP mode prototype | Added Access Point mode alongside station mode |
| 2026-07-08 | Startup display polish | Added status updates on display during boot (display init → wifi station), fixed startup comments appearing on UI, resolved AP discovery & channel issues |
| 2026-07-08 | HTTP API | Configured HTTP server with routes (`/health`, `/pass`), POST password validation flow |
| 2026-07-09 | UART parsing fix | Fixed data receive corruption in UART parsing |
| 2026-07-10 | Second ESP (AP mode) | Initialized second ESP as access point with HTTP endpoints |
| 2026-07-11 | AP disabled | Removed AP mode from central console, added wiring documentation |
| 2026-07-11 | UART driver | Configured UART driver for sensor communication (GPIO17 TX / GPIO18 RX) |
| 2026-07-28 | **Module separation (current)** | Separated device modules into distinct files (`connectivity`, `app_uart`, `httpendpoints`), moved endpoints out of `main.cpp`, wired all modules into `app_main()` entry point |

---

## Known Issues & Notes

### WiFi credential buffer in `wifi_start()`

`connectivity_esp.cpp` copies SSID/password into the `wifi_config_t` struct using `memcpy` with `size() + 1` (including null terminator):

| Buffer | Size | Overflow triggers at |
|---|---|---|
| `sta.ssid` | 32 bytes | SSID ≥ 32 bytes (33 bytes copied) |
| `sta.password` | 64 bytes | Password ≥ 64 bytes (65 bytes copied) |

**Why this is not a practical bug:**
- IEEE 802.11 caps SSIDs at 32 bytes; WPA2 caps passphrases at 64 bytes. No valid credential can exceed these limits.
- Even with a 32-byte SSID, the overflow null byte overwrites `password[0]`, which is immediately overwritten by the next `memcpy` for the password. The struct ends up correct.
- The WiFi driver (`esp_wifi_set_config`) would reject credentials longer than the spec anyway.

**Safe input limits:** SSID ≤ 31 bytes, password ≤ 63 bytes. These are also within the WPA2 passphrase range (8–63 bytes).

### UART

- TX/RX pins are swapped (`uart_set_pin(UART_NUM_1, 18, 17, ...)`) because the physical connector is wired straight-through (pin 1 to pin 1). This is intentional for the current hardware.
- Parity is set to `UART_PARITY_ODD` — both ends of the UART link use odd parity.

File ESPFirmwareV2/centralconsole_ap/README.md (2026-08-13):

# ESP32 Central Console — esp2 (HTTP → UART Passthrough AP)

This variant of the home security central console firmware runs an ESP32 as a **WiFi Access Point** that exposes HTTP endpoints for receiving configuration parameters from a client device, then relays them via UART1 to external sensor/actuator hardware.

## Quick Start

```bash
# Set target and build
idf.py set-target esp32
idf.py build

# Flash and monitor (adjust COM port as needed)
idf.py -p /dev/tty.usbserial-110 flash
idf.py -p /dev/tty.usbserial-110 monitor
```

Connect to WiFi network `espwifi` (password: `23012003`) from your client device, then hit the ESP's IP on port 80.

## Endpoints

| Method | Path | Body | Purpose |
|---|---|---|---|
| `GET` | `/health` | — | Liveness check, returns `{ "health": "ok" }` |
| `POST` | `/pair` | JSON | Receive pairing config (SSID, passwords, schedule, Pi IP) |

### `/pair` Request/Response

**Request body (JSON):**
```json
{
  "homessid": "mywifi",
  "homepass": "password123",
  "permpass": "0309",
  "encryptedpass": "abc...",
  "schedulestart": "08:00",
  "schedulestop": "22:00",
  "raspberrypiip": "192.168.0.236"
}
```

**Success response:** `{ "pairing payload received": "ok" }`
**Failure response:** `{ "pairing payload received": "corrupted" }` or HTTP 408 on timeout

The ESP forwards the raw JSON to the sensor over UART, waits up to 5 seconds for a response, then relays the result back.

## UART Frame Format

Bidirectional framing between ESP32 and sensor hardware:

```
SYNC(2B) | CMD(1B) | LEN(2B BE) | PAYLOAD(N) | CRC(2B BE)
```

| Field | Size | Description |
|---|---|---|
| SYNC | 2 bytes | `0x63 0x38` ("c8") |
| CMD | 1 byte | Command type (currently 0x00 = MOBILE_PAIRING) |
| LEN | 2 bytes | Payload length, big-endian |
| PAYLOAD | N bytes | The actual data |
| CRC | 2 bytes | `cmd_int + 2 * payload_len`, big-endian |

### Pinout

| Peripheral | ESP32 Pin(s) | Notes |
|---|---|---|
| UART1 TX | GPIO17 | Baud 230120, odd parity, 8N1 |
| UART1 RX | GPIO18 | |
| UART1 RTS | GPIO4 | Hardware flow control (disabled) |
| UART1 CTS | GPIO5 | Hardware flow control (disabled) |

## Architecture

```
Client Device ──HTTP POST /pair──> ESP32 (AP: espwifi)
                                       │
                                       ▼
                                  UART1 (230120 baud)
                                       │
                                       ▼
                              External Sensor Hardware
                                       │
                       ◄───────────────┘
                  (response via same frame format)
```

- **Single-threaded main loop** — `while(true)` polls `uart.receive()` every 100ms. HTTP handlers and UART share the same thread.
- **Queue-based response handling** — Sensor responses are sent via a 1-slot FreeRTOS queue (`waitfors3`). The `/pair` handler waits up to 5s for a response.
- **No persistent storage** — Credentials are passed through to UART and forgotten. Nothing stored in NVS.

## Assumptions & Design Constraints

- **Payloads are always small (< 200 bytes)** — The UART frame parser reads into a 200-byte buffer and trusts the `LEN` field from the frame header. This works because all payloads (config JSON, sensor data) are well under 200 bytes. No explicit bounds check on `payload_len` against the remaining frame data — the code assumes one frame per UART read from a trusted sensor.

- **Plaintext credential logging accepted** — All POST handlers log submitted values via `printf` to the UART debug console. This is intentional for development and accepted because the device will be deployed in a physically inaccessible location where serial console access is not a realistic threat.

- **Queue-based response handling** — `waitfors3` is a 1-slot queue of `std::string*` (created in `httpendpoints.cpp:80`). Writer (`app_uart.cpp:142-143`) allocates with `new`, sends non-blocking (`ticks=0`). Reader (`httpendpoints.cpp:54`) waits up to 5s, then `delete`s. The only leak path: sensor sends two responses before handler reads the first, causing `xQueueSend` to fail silently on the second. This is practically unreachable because the sensor sends exactly one response per command and the handler is blocked waiting — so the queue never overflows. If it ever does, the fix is to check `xQueueSend` return value and `delete` on failure.

## Known Issues

- **No authentication on `/pair`** — Any device on the AP WiFi can submit credentials. Acceptable for prototyping; add token-based auth before production.
- **Blocking main loop** — HTTP handlers and UART polling compete on the same thread. Use FreeRTOS tasks for production.
- **Weak checksum** — The CRC is an additive hash (`cmd + 2*len`) that doesn't include payload bytes. Sufficient for short, low-noise UART links but not for noisy environments.
- **Hardcoded WiFi credentials** — AP SSID/password in plaintext source code. Acceptable for prototyping; use NVS or first-boot provisioning for production.
- **Outdated documentation** — The old query-string endpoints (`/pass`, `/ssid`, `/otp`, etc.) have been replaced by the single `/pair` JSON endpoint. The git history still references them.

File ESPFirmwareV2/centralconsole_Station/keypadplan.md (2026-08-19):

# 4x4 Keypad Implementation Plan

## 1. Overview

Add a physical 4x4 matrix keypad to the ESP32-S3 central console for PIN entry and settings navigation. The keypad replaces the current stub `keypad_s` (empty `init()`/`process()`) with a fully debounced, event-driven key scanner that feeds into the existing display state machine.

**Goal**: Users can enter a 4–8 digit PIN on the physical keypad to arm/disarm the system, and navigate the existing SETTINGS/SETUP_INSTRUCTIONS pages without touching the screen.

---

## 2. Hardware Design

### 2.1 Wiring — 4 Rows × 4 Columns = 16 Keys

Actual wiring (confirmed):

| Pin | ESP32-S3 GPIO | Role | Pull Resistor |
|-----|---|---|---|
| R1  | GPIO42 | Row | Internal pull-up |
| R2  | GPIO41 | Row | Internal pull-up |
| R3  | GPIO40 | Row | Internal pull-up |
| R4  | GPIO39 | Row | Internal pull-up |
| C1  | GPIO38 | Column | Internal pull-up |
| C2  | GPIO37 | Column | Internal pull-up |
| C3  | GPIO36 | Column | Internal pull-up |
| C4  | GPIO35 | Column | Internal pull-up |

All pins are in the GPIO35–42 range — no conflicts with UART1 (GPIO17/18), SPI bus (GPIO11–13), TFT control pins (GPIO9/10/14/15), or touch IRQ (GPIO7). All support internal pull-up (`GPIO_MODE_DEFAULT` with `GPIO_PULLUP_ENABLE`).

### 2.2 Schematic Notes

- No external resistors needed — ESP32-S3 GPIOs have configurable internal pull-ups (~25–50 kΩ).
- Optional: 100 Ω series resistor on each column line to dampen ringing.
- Optional: 0.1 µF decoupling capacitor across VCC/GND near keypad connector.

---

## 3. Software Architecture

### 3.1 Key Abstraction

```
Key event types (enum):
  KEY_NONE       — no change
  KEY_PRESS      — first debounced press detected
  KEY_REPEAT     — subsequent polls while held (after HOLD_THRESHOLD ms)
  KEY_RELEASE    — key lifted
```

### 3.2 Scanning Algorithm

Use the existing `while(true)` polling loop pattern (matching `display.process()` / `uart.receive()`). No FreeRTOS tasks or interrupts needed — the existing codebase uses synchronous poll-only for all input.

**Row-scan method** (standard matrix scanning):
1. Set all rows to INPUT with pull-up enabled.
2. Set all columns to OUTPUT, drive all high.
3. For each column (C1→C4):
   a. Drive that column LOW.
   b. Read all 4 rows — if a row reads LOW, that key is pressed.
   c. Drive that column back HIGH.
   d. Continue to next column.

**Debounce strategy**: Software debounce with a 50 ms threshold.
- Track `last_press_time[row][col]` — only register a press if 50 ms has elapsed since the last state change for that key.
- Track `key_state[row][col]` — one of `KEY_RELEASED` / `KEY_PRESSED`.

### 3.3 Data Structures

```cpp
enum class KeyState : uint8_t {
    KEY_RELEASED,
    KEY_PRESSED,
    KEY_REPEAT
};

enum class KeyEvent : uint8_t {
    KEY_NONE,
    KEY_PRESS,
    KEY_REPEAT,
    KEY_RELEASE
};

struct KeyInfo {
    uint8_t row;
    uint8_t col;
    char key;        // '0'-'9', 'A'-'D', '*', '#'
    KeyEvent event;
};

struct keypad_s {
public:
    void init();
    KeyEvent process();           // returns the latest key event
    char getBuffer();             // returns last entered char (for PIN display)
    void clearBuffer();           // clears entered PIN buffer
    size_t getBufferLength();     // returns current buffer length

private:
    static constexpr uint8_t ROWS = 4;
    static constexpr uint8_t COLS = 4;
    static constexpr uint8_t DEBOUNCE_MS = 50;
    static constexpr uint8_t HOLD_REPEAT_MS = 300;
    static constexpr size_t MAX_BUFFER = 16;

    // Pin assignments
    static constexpr uint8_t row_pins[ROWS] = {42, 41, 40, 39};
    static constexpr uint8_t col_pins[COLS] = {38, 37, 36, 35};

    // Key map: key[row][col]
    static constexpr char key_map[ROWS][COLS] = {
        {'1', '2', '3', 'A'},
        {'4', '5', '6', 'B'},
        {'7', '8', '9', 'C'},
        {'*', '0', '#', 'D'}
    };

    // State
    KeyState raw_state[ROWS][COLS];       // raw debounced state per key
    uint32_t press_time[ROWS][COLS];      // when key was pressed (for repeat)
    char pin_buffer[MAX_BUFFER + 1];      // entered PIN digits
    size_t buffer_len;

    // Private helpers
    void scan();
    KeyEvent translateEvent(uint8_t r, uint8_t c);
};
```

### 3.4 Integration Points

#### 3.4.1 Main Loop (`main.cpp`)

Current loop:
```cpp
while (true) {
    display.init();
    display.process();
    uart.receive();
}
```

New loop (add keypad processing):
```cpp
while (true) {
    display.init();
    display.process();
    KeyEvent ke = keypad.process();
    if (ke != KEY_NONE) {
        handleKeypadEvent(ke);  // new function in main.cpp or keypad.cpp
    }
    uart.receive();
}
```

#### 3.4.2 Display Integration

Two modes of keypad interaction:

**Mode A — PIN Entry Overlay** (primary use case):
- When the user is on the ARMED or UNARMED screen, pressing a digit key opens a PIN entry overlay on the TFT.
- Each keypress echoes `'*'` characters (or shows dots) on-screen.
- `#` confirms the PIN → validate against stored PIN in NVS.
- `*` clears the buffer / cancels.
- On successful PIN match: toggle armed/unarmed state (same as current touch gesture).
- On failure: brief "ACCESS DENIED" flash, clear buffer.

**Mode B — SETTINGS Navigation**:
- In SETTINGS page, use directional keys (A=up, C=down, B=select, #=back) to navigate options.
- This is lower priority; the current SETTINGS page is a static image with no interactive elements.

#### 3.4.3 Storage Integration

- Store the user-set PIN in NVS under key `"pin"` (4–16 digits, stored as a null-terminated string).
- Default PIN: `"1234"` (set on first boot if NVS key doesn't exist).
- `storage.store("pin", pin_value)` and `storage.read("pin")` follow existing patterns.

---

## 4. Implementation Phases

### Phase 1: Core Scanner (Foundation)

**Files changed**: `keypad.h`, `keypad.cpp`

- Define pin constants, key map, data structures in `keypad.h`.
- Implement `keypad_s::init()`:
  - Configure 4 row pins as INPUT with pull-up.
  - Configure 4 column pins as OUTPUT, set all HIGH.
- Implement `keypad_s::process()`:
  - Row-scan all columns.
  - Apply 50 ms software debounce.
  - Return `KeyEvent` (PRESS/REPEAT/RELEASE/NONE).
- Add `log()` calls for each key press (debug output).
- Wire `keypad.process()` into `main.cpp` main loop (no behavior yet, just log).

**Verification**: Flash → monitor serial → press each key → verify correct key char and event type printed at ~50 ms debounce interval.

### Phase 2: PIN Buffer & Display Overlay

**Files changed**: `keypad.cpp`, `display.h`, `display.cpp`

- Add `pin_buffer[]`, `getBuffer()`, `clearBuffer()`, `getBufferLength()` to `keypad_s`.
- On `KEY_PRESS` for digit keys (`0`–`9`, `*`, `#`): append to buffer (if not full).
- On `KEY_PRESS` for `#`: trigger PIN validation.
- On `KEY_PRESS` for `*`: clear buffer.
- Add a `pin_entry` page to `Display::Page` enum.
- Implement `Display::pinEntry()`:
  - Draw a darkened background overlay.
  - Draw a "Enter PIN" prompt.
  - Draw `'*'` characters for each buffered digit.
  - Draw "CANCEL" and "ENTER" button outlines (for touch fallback).
- Transition: when a digit is pressed from any page, switch to `PIN_ENTRY` state and redraw.
- On `#` (confirm): validate, then transition back to previous state.

**Verification**: Flash → power on → press digits → see `'*'` characters appear on TFT → press `#` → see "ACCESS DENIED" (since no PIN is stored yet) → press `*` → buffer clears.

### Phase 3: PIN Validation & Arm/Disarm

**Files changed**: `keypad.cpp`, `storage.h`, `storage.cpp`, `display.cpp`

- On first boot, if NVS key `"pin"` doesn't exist, store `"1234"` as default.
- On `#` key press:
  1. Read stored PIN from NVS via `storage.read("pin")`.
  2. Compare entered buffer against stored PIN (`strcmp`).
  3. If match:
     - Toggle armed/unarmed state (call existing `Display::armed()` or `Display::unarmed()`).
     - Clear buffer, return to main page.
     - Log "PIN ACCEPTED — armed/disarmed".
  4. If mismatch:
     - Show "ACCESS DENIED" for 2 seconds on the overlay.
     - Clear buffer, return to previous page.
     - Log "PIN REJECTED".

**Verification**: Flash → power on → enter "1234" → press `#` → system arms/disarms → try wrong PIN → see "ACCESS DENIED".

### Phase 4: PIN Change Flow (Settings)

**Files changed**: `display.h`, `display.cpp`, `keypad.cpp`, `storage.cpp`

- Extend SETTINGS page to support PIN change via keypad.
- New sub-state machine in `Display::settings()`:
  1. Show "Current PIN:" prompt.
  2. User enters current PIN → validate.
  3. Show "New PIN:" prompt.
  4. User enters new PIN (4–16 digits, `#` to confirm).
  5. Show "Confirm New PIN:" prompt.
  6. User re-enters new PIN → compare.
  7. If match: `storage.store("pin", new_pin)`, show "PIN UPDATED".
  8. If mismatch: show "MISMATCH — try again".

**Verification**: Navigate to SETTINGS → change PIN → arm with old PIN (should fail) → arm with new PIN (should succeed).

### Phase 5: Polish & Edge Cases

- **Key repeat**: Hold a key → after 300 ms, `KEY_REPEAT` fires → append to buffer (allows fast PIN entry).
- **Auto-clear**: If no keypress for 30 seconds during PIN entry, clear buffer and return to previous page.
- **Overflow protection**: Buffer capped at 16 chars; extra digits are ignored (or beep).
- **Anti-tamper**: If 5 consecutive wrong PINs, lock out for 30 seconds (log attempt count in NVS).
- **Keypad visual feedback**: Briefly highlight the pressed key's position on-screen (optional, cosmetic).

---

## 5. File Change Summary

| File | Change | Phase |
|---|---|---|
| `keypad.h` | Add full class definition with pin constants, key map, state structs, public API | 1 |
| `keypad.cpp` | Implement scanner, debounce, buffer management, event translation | 1–3 |
| `main.cpp` | Add `keypad.process()` call, `handleKeypadEvent()` dispatcher | 1, 3 |
| `display.h` | Add `PIN_ENTRY` to `Display::Page` enum | 2 |
| `display.cpp` | Add `Display::pinEntry()`, overlay drawing, state transitions | 2–3 |
| `storage.h` | (No changes needed — already supports `store`/`read`) | — |
| `CMakeLists.txt` | (No changes — `keypad.cpp` already listed) | — |

---

## 6. Risks & Mitigations

| Risk | Impact | Mitigation |
|---|---|---|
| GPIO35–42 are high-side pins (no analog functions) | No impact — all clean GPIO | No mitigation needed |
| Pin bouncing causes double-entries | PIN entry corrupt | 50 ms software debounce + state machine per key |
| Blocking `delay()` in display overlay | UART polling stalls | Avoid `delay()` in `pinEntry()`; use non-blocking timers (`millis()` comparison) |
| Stack overflow from deep nesting | Hard fault | Keep overlay drawing simple; avoid recursion |
| NVS wear from frequent PIN changes | Flash wear over time | PIN stored only on change, not on every arm/disarm |

---

## 7. Out of Scope (Future)

- **Touch + keypad coexistence**: Currently, SETTINGS page uses touch. Keypad navigation for SETTINGS (Phase 4) is a separate input path — both should work but aren't merged into a unified input abstraction.
- **Multi-language keypad labels**: Keypad key labels on-screen are assumed to match standard `123A456B789C*0#D` layout.
- **Bluetooth OTA PIN update**: No BLE or WiFi-based remote PIN change.
- **Keypad macro support**: No programmable key sequences.
- **Hardware debouncing**: No external RC circuits; software-only debounce.

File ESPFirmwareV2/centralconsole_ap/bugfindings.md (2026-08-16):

# Bug Findings — Central Console AP Firmware

**Target:** `centralconsole_ap` (ESP32 WROOM, AP mode)
**Files analyzed:** `main/main.cpp`, `main/httpendpoints.cpp`, `main/httpendpoints.h`, `main/app_uart.cpp`, `main/app_uart.h`, `main/connectivity_esp.cpp`, `main/connectivity.h`, `main/jsonhandler.cpp`, `main/jsonhandler.h`, `main/CMakeLists.txt`

---

## CRITICAL

### 1. [VERIFIED] Memory leak on full queue

**File:** `app_uart.cpp:150-154`

**Description:** A `new std::string` is allocated before sending to the queue, but the return value of `xQueueSend` is not checked. When the 1-slot queue is full, the pointer is lost and the allocation leaks.

```cpp
std::string *p = new std::string(payload);
if (xQueueSend(waitfors3, &p, 0) != pdPASS) {
    delete p;  // ← FIX: queue full — sender never gets the pointer
}
```

**Leak scenarios:**
- **Two responses before drain:** HTTP handler calls `uart.send()`, then blocks on `xQueueReceive` (6s timeout). Sensor sends response #1 (queued successfully), then response #2 (queue full → leak).
- **Unsolicited sensor message:** Sensor sends a response when no `/pair` handler is waiting. First message sits in the queue forever (abandoned heap). Second message leaks.

**Fix applied.** The queue depth could also be increased (e.g., 4–8) for burst tolerance.

---

### 2. [VERIFIED] Out-of-bounds read on truncated/malformed UART frames

**File:** `app_uart.cpp:112-127`

**Description:** The `pair_receive` buffer is 200 bytes. After parsing the LEN field, the code reads `payload_len` payload bytes followed by 2 CRC bytes — with no bounds check against the number of bytes actually received (`length`). If the frame declares a `payload_len` larger than the received data, the loop reads past the end of `pair_receive`.

**Concrete scenario:** Sensor sends 10 bytes with `payload_len = 10`. The loop reads 10 bytes starting at offset 5, accessing indices 5–14. But `length = 10`, so indices 10–14 are 5 bytes out of bounds into uninitialized stack memory.

**Impact:** Stack buffer over-read. On ESP32 (no MMU), this silently corrupts adjacent stack data, leading to wrong payload/CRC values or leaked stack data (e.g., local pointers) across the UART.

**Fix applied.** Bounds check added after LEN parsing:

```cpp
if (message_pos + payload_len + 2 > length) {
    printf("  Frame too small for declared payload: need %d, have %d\n",
           message_pos + payload_len + 2, length);
    return "";
}
```

---

### 3. [DISMISSED] UART parity mismatch

**File:** `app_uart.cpp:24`

```cpp
uartconf.parity = UART_PARITY_ODD;
```

**Description:** The ESP32 UART RX hardware is configured with odd parity (10-bit frames: START + D0–D7 + PARITY + STOP). If the S3 companion firmware used `UART_PARITY_DISABLE`, the bit boundaries would misalign and every byte would be corrupted.

**Verdict:** Dismissed. The S3 firmware (`centralconsole_Station`) has been verified to also use odd parity. Both sides agree — configuration is correct.

---

## HIGH

### 4. [VERIFIED] CRC validation is NOT a bug

**File:** `app_uart.cpp:110-137`

**Re-evaluation:** The earlier assessment that line 102 (`message_pos += 1`) skips the first payload byte was incorrect. A byte-by-byte trace with a concrete 4-byte payload (`"test"`, cmd=0) shows the frame layout:

| offset | 0 | 1 | 2 | 3 | 4 | 5 | 6 | 7 | 8 | 9 | 10 |
|---|---|---|---|---|---|---|---|---|---|---|---|
| byte | AA | 55 | 00 | 00 | 04 | 74 | 65 | 73 | 74 | 00 | 08 |
| role | S | Y | CMD | L1 | L2 | P[0] | P[1] | P[2] | P[3] | CRC1 | CRC2 |

The receiver's `message_pos` starts at 1 (second sync byte), then:
- CMD: reads from `message_pos + 1 = 2` → `message_pos = 2`
- LEN: reads from `message_pos + 1 = 3, 4` → `message_pos = 4`
- Line 102: `message_pos = 5` → first payload byte ✓
- CRC: reads from `message_pos = 9, 10` ✓
- Validation: `0 + 2*4 = 8 == 0x0008` ✓

**Verdict:** The CRC validation works correctly. The formula (`cmd + 2 * payload_len`) is a weak checksum but is consistent between sender and receiver.

---

### 5. [INTENTIONAL] New AP password generated but never applied

**File:** `httpendpoints.cpp:71-83`

**Description:** A random 32-character password is generated, sent back to the HTTP client, but the `uart.send()` call and `ap_start()` call are commented out. The AP continues running on hardcoded credentials.

**Verdict:** Acknowledged as intentional debug scaffolding. Will be fixed later.

---

### 6. [VERIFIED] HTTP stack size is sufficient for known payload

**File:** `httpendpoints.cpp:119`

**Re-evaluation:** The original claim that 8 KB is too small was based on a worst-case analysis. With the actual fixed payload (~170 bytes minified), the peak stack usage is:

| Component | Bytes |
|---|---|
| esp_http_server internals | ~700 |
| `buf[1000]` | 1,000 |
| 7 × `std::string` objects | 168 |
| `resp_buf[256]` | 256 |
| Other locals + prologue | ~36 |
| `jsonparser` peak | ~64 |
| Context overhead | ~200 |
| **Total peak** | **~2,424** |
| **Available** | **8,192** |
| **Headroom** | **~5,768 (70%)** |

**Verdict:** Not a bug. The 8 KB stack provides 70% headroom for this payload size.

**Note:** The 1000-byte `buf[]` is wasteful (only ~17% utilized) but not dangerous. It could be reduced to 256 bytes as a minor optimization.

---

### 7. [VERIFIED] cJSON_Parse return value — error masking

**File:** `jsonhandler.cpp:4-21`

**Description:** `jsonparser()` returns `""` for both "invalid JSON" (parse failure) and "key not found" (missing field). The caller in `httpendpoints.cpp` treats both identically — the parsed value is only used for `printf` logging, not for validation logic.

```cpp
std::string jsonparser(const char *json_str, const char *key) {
    cJSON *root = cJSON_Parse(json_str);
    if (root == NULL) return "";          // Path A: parse error
    cJSON *item = cJSON_GetObjectItem(root, key);
    if (cJSON_IsString(item)) {
        std::string result = item->valuestring;
        cJSON_Delete(root);
        return result;                    // Path B: found
    }
    cJSON_Delete(root);
    return "";                            // Path C: key missing
}
```

**Impact:** Invalid JSON and missing keys produce identical output (`Key: `). However, since the parsed values are only logged and the raw JSON is forwarded to the sensor (which decides whether to accept it), the practical impact is limited to **noisy but not dangerous** logs.

**Risk:** If any future code path uses parsed values for decision-making, this masking would cause silent failures.

---

## MEDIUM

### 8. printf of raw payload bytes floods serial console

**File:** `app_uart.cpp:52-57, 115`

Every received byte is printed individually with `%02x`, plus per-byte payload logging. This will flood the serial console and cause significant performance degradation during normal operation, especially at 230120 baud.

---

### 9. No authentication on any endpoint

All POST endpoints (`/pass`, `/ssid`, `/permanentpass`, `/encryptedpass`, `/otp`, `/schedule` x2, `/pair`) accept credentials with zero access control. Any device on the AP WiFi can submit or retrieve secrets.

---

### 10. Credential values logged to serial console

Every credential handler dumps submitted secrets to the UART debug console via `printf`.

---

### 11. No retry or error handling on WiFi config

**File:** `connectivity_esp.cpp:45-47`

`esp_wifi_set_config()` and `esp_wifi_start()` return `esp_err_t` but the return values are ignored. If these calls fail, the AP silently won't start with no error indication.

---

## Summary

| Severity | Count | Status | Issues |
|---|---|---|---|
| CRITICAL | 2 | Fixed | Queue memory leak, OOB read on truncated frames |
| HIGH | 4 | Dismissed | Parity mismatch, CRC validation, AP password debug stub, stack size |
| HIGH | 1 | Minor | cJSON error masking |
| MEDIUM | 4 | Design | Serial logging flood, no auth, credential logging, WiFi error handling |

**Fixes applied:** Memory leak (`app_uart.cpp:150-154`) and OOB read (`app_uart.cpp:108-113`).

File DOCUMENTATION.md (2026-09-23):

# Home Security — implementation guides

System design (D1–D19, §1–§23) lives in **[README.md](README.md)**. This file is for
people picking up a slice of work.

| Guide | Who | Status |
|---|---|---|
| [Phone: Google Drive OAuth](#phone-google-drive-oauth-and-token-handoff) | mobile app | **ready to implement** — Pi side is live |
| [Legacy cloud-backend testing](#legacy-cloud-backend-testing-guide) | retired path (D10) | do not extend |

---

## Phone: Google Drive OAuth and token handoff

**Owner:** whoever is on the mobile app (`mobile/`).
**Pi owner does not need to wait** — `pi_hub/drive.py` already records clips and
uploads them once this handoff succeeds.

Architecture: [README.md §17](README.md#17-clips-pi-cache--google-drive) (pipeline)
and [§18](README.md#18-google-token-handoff) (security rules). This section is the
copy-paste contract + Expo template.

### What the Pi needs from the phone

The Pi never talks to Google as "the user" until the phone finishes OAuth and
hands credentials over. One `POST` on the home LAN or Tailscale — never a public
URL.

`POST http://<pi-host>:4000/auth/drive`

The refresh token is **bound to the OAuth client that issued it**. The Pi
therefore needs that client's id and secret so it can mint access tokens later,
when a clip is ready and the phone is not around.

Send **exactly one** of the two shapes below. `client_id` + `client_secret` are
required in both.

#### Shape A — phone already has a refresh token (preferred)

```json
{
  "refresh_token": "1//0e…",
  "email": "user@gmail.com",
  "client_id": "xxxx.apps.googleusercontent.com",
  "client_secret": "GOCSPX-…"
}
```

`email` can be omitted: the Pi will call Google userinfo after refreshing. Send
it anyway so the Settings UI can show "Drive linked as …" without a round trip.

#### Shape B — phone has an auth code (Expo AuthSession default)

Expo `AuthSession` returns an **authorization code** plus a PKCE
`code_verifier`. Forward both; the Pi exchanges them for the refresh token.

```json
{
  "auth_code": "4/0Aan…",
  "code_verifier": "the PKCE verifier from AuthRequest",
  "redirect_uri": "homesecurity://oauth",
  "client_id": "xxxx.apps.googleusercontent.com",
  "client_secret": "GOCSPX-…",
  "email": "user@gmail.com"
}
```

`server_auth_code` is accepted as an alias of `auth_code` (Google Sign-In
Android/iOS). If that library used PKCE, still send `code_verifier`.

#### Success / failure

```json
{ "ok": true, "email": "user@gmail.com", "folder_name": "SentriHome", "linked": true }
```

```json
{ "ok": false, "error": "…", "hint": "Need access_type=offline and prompt=consent …" }
```

If `hint` mentions `prompt=consent`, Google did not issue a refresh token.
That is almost always a missing `access_type=offline` or a silent re-auth that
skipped the consent screen.

### Other Pi endpoints the phone uses

| Method | Path | Why |
|---|---|---|
| `GET` | `/auth/drive` | `{ linked, email, folder_name, last_upload, error }` — no secrets |
| `DELETE` | `/auth/drive` | User tapped Disconnect. Pi forgets the token. |
| `GET` | `/health` | `drive.linked` / `drive.error` (and legacy `drive_token`: bool) |
| `POST` | `/motion` | Optional: force a clip so you can verify upload during Settings QA |

Helpers already exist in `mobile/lib/api.ts`: `piApi.authDrive`, `piApi.driveStatus`.
Pi host comes from the setup wizard / Settings (`getPiBaseUrl()`, port 4000).

Do **not** list clips via `GET /clips/cache` in the product UI. That is a Pi-local
debug listing. Playback is the user's own Drive session (cellular, Tailscale off)
— that is a follow-up on the Clips tab, not this handoff.

### Google Cloud Console (once, shared by phone + Pi)

1. Create (or reuse) a Google Cloud project.
2. Enable **Google Drive API**.
3. OAuth consent screen: External, test users = the Gmail accounts you use.
4. Scopes:
   - `https://www.googleapis.com/auth/drive.file` (files this app creates only)
   - `https://www.googleapis.com/auth/userinfo.email`
5. Create an OAuth client, type **Web application** (not iOS/Android — native
   clients do not give the Pi a refreshable token).
6. Authorized redirect URIs, all of these:
   - `homesecurity://oauth`  (dev client, `app.json` scheme)
   - the URI `AuthSession.makeRedirectUri({ scheme: 'homesecurity', path: 'oauth' })` prints on device
7. Copy **Client ID** and **Client secret** into the app env (below). The same
   pair is what `POST /auth/drive` sends to the Pi.

Desktop-app clients also work; Web is the one Expo documents. Do not create a
separate Pi-only client — a refresh token from client A cannot be refreshed by
client B.

### App env (`mobile/.env`)

```
EXPO_PUBLIC_GOOGLE_CLIENT_ID=xxxx.apps.googleusercontent.com
EXPO_PUBLIC_GOOGLE_CLIENT_SECRET=GOCSPX-…
```

These are "installed app" secrets: they ship in the binary. That is expected.
The **refresh token** is the real secret — store it in SecureStore if the phone
keeps a copy, and never log it. The Pi encrypts its copy at rest.

### Packages to add

```bash
cd mobile
npx expo install expo-auth-session expo-crypto
```

`expo-web-browser` is already a dependency.

### Template — drop into `mobile/lib/driveAuth.ts`

This is a starting file, not production-polished UX. Wire a Settings button to
`connectGoogleDrive()`, show `driveStatus().email`, and a Disconnect that calls
`DELETE /auth/drive` plus `signOut` of the Google session.

```ts
import * as AuthSession from 'expo-auth-session';
import * as WebBrowser from 'expo-web-browser';

import { piApi } from '@/lib/api';

WebBrowser.maybeCompleteAuthSession();

const CLIENT_ID = process.env.EXPO_PUBLIC_GOOGLE_CLIENT_ID ?? '';
const CLIENT_SECRET = process.env.EXPO_PUBLIC_GOOGLE_CLIENT_SECRET ?? '';

const SCOPES = [
  'https://www.googleapis.com/auth/drive.file',
  'https://www.googleapis.com/auth/userinfo.email',
];

const discovery: AuthSession.DiscoveryDocument = {
  authorizationEndpoint: 'https://accounts.google.com/o/oauth2/v2/auth',
  tokenEndpoint: 'https://oauth2.googleapis.com/token',
};

export function googleRedirectUri(): string {
  return AuthSession.makeRedirectUri({ scheme: 'homesecurity', path: 'oauth' });
}

/** Run from a Settings "Connect Google Drive" button. Must reach the Pi. */
export async function connectGoogleDrive(): Promise<{ email: string }> {
  if (!CLIENT_ID || !CLIENT_SECRET) {
    throw new Error('Set EXPO_PUBLIC_GOOGLE_CLIENT_ID and _CLIENT_SECRET in mobile/.env');
  }

  const redirectUri = googleRedirectUri();
  const request = new AuthSession.AuthRequest({
    clientId: CLIENT_ID,
    scopes: SCOPES,
    redirectUri,
    responseType: AuthSession.ResponseType.Code,
    usePKCE: true,
    extraParams: {
      access_type: 'offline',
      prompt: 'consent', // required or Google omits refresh_token on the second login
    },
  });

  const result = await request.promptAsync(discovery);
  if (result.type !== 'success' || !result.params.code) {
    throw new Error(result.type === 'cancel' ? 'Sign-in cancelled' : 'Google sign-in failed');
  }

  const handed = await piApi.authDrive({
    auth_code: result.params.code,
    code_verifier: request.codeVerifier,
    redirect_uri: redirectUri,
    client_id: CLIENT_ID,
    client_secret: CLIENT_SECRET,
  });

  if (!handed.ok) {
    throw new Error(handed.error || 'Pi rejected Drive credentials');
  }
  return { email: handed.email || '' };
}

export async function driveLinkStatus() {
  return piApi.driveStatus();
}
```

Settings UX (minimum):

1. Button **Connect Google Drive** → `connectGoogleDrive()`.
2. After success, show `Drive linked as {email}`. Confirm with `piApi.driveStatus()`.
3. Button **Disconnect Drive** → `piApi.unlinkDrive()`.
4. If `driveStatus().error` contains `invalid_grant`, show **Reconnect Google Drive**
   (token revoked in Google Account settings). Do not fail silently.

Keep the existing cloud-backend "paste a Bearer token" login (`/login`) alone —
that is the retired S3 clips path (D10). Drive linking is a **separate** control
on Settings, talking to the Pi, not to port 3001.

### Local smoke test (phone person, no firmware)

On a laptop on the same LAN / Tailscale as the Pi, after you have a real
`refresh_token` from Google's OAuth Playground (scope `drive.file`, offline):

```bash
curl -s -X POST http://192.168.0.236:4000/auth/drive \
  -H 'Content-Type: application/json' \
  -d '{"refresh_token":"1//…","email":"you@gmail.com","client_id":"….apps.googleusercontent.com","client_secret":"GOCSPX-…"}'

curl -s http://192.168.0.236:4000/auth/drive   # linked: true, no token in body
curl -s -X POST http://192.168.0.236:4000/motion
# Drive: a SentriHome folder appears; clip-YYYYMMDD-HHMMSS.mp4 inside it
```

Replace the LAN IP with the Tailscale IP (`100.66.51.106`) when testing off-LAN.

### Phone-side checklist (Phase 8, handoff only)

- [ ] Google Cloud Web client + Drive API + test users
- [ ] `expo-auth-session` + env client id/secret
- [ ] `access_type=offline` **and** `prompt=consent` on every connect
- [ ] Scope limited to `drive.file` + email — not `drive` / `drive.readonly`
- [ ] `POST /auth/drive` only while on LAN or Tailscale
- [ ] SecureStore if the app keeps `refresh_token`; never `console.log` it
- [ ] Settings: linked email, disconnect, reconnect-on-revoked
- [ ] Confirm `GET /health` → `drive.linked: true` after connect
- [ ] Confirm a `POST /motion` clip lands in Drive **SentriHome**
- [ ] Later (not this ticket): Clips tab lists/plays from Drive with Tailscale off

### Out of scope for the phone person (already on the Pi)

Clip record from MediaMTX, encrypted token file, folder create, multipart
upload, `invalid_grant` surfaced on `GET /auth/drive`. Local cache retention
after a successful upload is still TBD (README §22 #9).

---

## Legacy: cloud-backend testing guide

Run automated tests and manual checks before pushing. Covers **retired**
cloud-backend auth and API, and the old frontend (Android app) flows. Product
clips are Pi → Drive (above), not S3.

---

## 1. Backend: automated tests (no server needed)

From repo root:

```bash
cd cloud-backend
npm test
```

- Runs unit tests for the **auth** module (token create/lookup/invalidate, `requireAuth`, `requireAuthOrQueryToken`, `optionalAuth`).
- Expect: **all tests pass** (16 tests).

---

## 2. Backend: smoke test (server + MongoDB running)

1. Start the cloud backend (and ensure MongoDB is reachable):

   ```bash
   cd cloud-backend
   npm start
   ```

2. In another terminal, run the smoke script:

   ```bash
   cd cloud-backend
   chmod +x scripts/smoke-test.sh
   ./scripts/smoke-test.sh http://localhost:3001
   ```

   Or with ngrok base URL:

   ```bash
   ./scripts/smoke-test.sh https://YOUR-NGROK-URL
   ```

- Checks: **GET /status** returns 200; **GET /api/events** and **GET /api/auth/me** return **401** when no token.

---

## 3. Frontend (Android app): how to test

Use a device or emulator with the app installed. Cloud backend must be running and reachable (localhost for emulator, or ngrok URL for a real device).

### 3.1 Setup

- **Emulator:** Set `cloud.base.url` in `ESP32PairingApp/local.properties` to your backend (e.g. `http://10.0.2.2:3001` for Android emulator → host machine).
- **Real device:** Use your ngrok URL (e.g. `https://xxxx.ngrok-free.app`) and the same in **Google Cloud Console** redirect URIs and in **cloud-backend/credentials.json** `redirect_uris`.
- In the app, open **Edit Cloud** and confirm the base URL matches (or leave default from `local.properties`).

### 3.2 Login (Google OAuth)

1. Open the app → go to **Stream & Clips** (or the screen with “Connect Google Drive”).
2. Tap **Connect Google Drive**.
3. Browser should open; sign in with Google and allow access.
4. You should be redirected back to the app and see a toast like “Google Drive connected as your@gmail.com”.
5. **Check:** The same screen should show “Drive: logged in as your@gmail.com”.

**If redirect fails:** Confirm redirect URI in Google Cloud Console and in `credentials.json` exactly matches the URL the browser is sent to (e.g. `https://your-ngrok/auth/google/callback`).

### 3.3 Auth-only requests (after login)

1. Stay on **Stream & Clips** (logged in).
2. **Check:** “Drive: logged in as …” is visible.
3. Tap **Log out**.
4. **Check:** The Drive line disappears and you can log in again.

### 3.4 Load clips (private data)

1. Log in with **Connect Google Drive** (see 3.2).
2. Go to **Watch saved clips** (or the section with “Load Clips from Drive”).
3. **Check:** You see “Load Clips from Drive” enabled (not “Sign in with Google Drive to view your clips”).
4. Tap **Load Clips from Drive**.
5. **Check:** Either a list of your clips appears or “Loaded 0 events” (no errors). No 401/403 in the message.
6. If you have clips: **Check** thumbnails load and **Play** opens the video (URL includes token for backend).

### 3.5 Not logged in

1. Log out (or clear app data / reinstall so there is no stored token).
2. Open **Watch saved clips**.
3. **Check:** Message “Sign in with Google Drive to view your clips.” and **Load Clips from Drive** is disabled.
4. **Check:** Tapping Load does nothing (button disabled).

### 3.6 Device linking (optional)

If you use Pi uploads and device linking:

1. Log in in the app.
2. Call **POST /api/devices/link** with your backend auth token and body `{ "deviceId": "your-pi-device-id" }` (e.g. with curl or Postman).
3. Upload a clip from the Pi with that `deviceId`.
4. **Check:** In the app, after “Load Clips from Drive”, the new clip appears under your account.

---

## 4. Quick checklist before push

- [ ] `cd cloud-backend && npm test` — all tests pass.
- [ ] Backend starts: `npm start` (MongoDB up).
- [ ] Smoke test: `./scripts/smoke-test.sh http://localhost:3001` passes.
- [ ] Frontend: Login with Google → see “logged in as …”.
- [ ] Frontend: Logout → Drive line disappears.
- [ ] Frontend: When logged in, “Load Clips from Drive” works (list or 0 events, no 401).
- [ ] Frontend: When not logged in, clips section shows sign-in message and Load is disabled.

---

## 5. Troubleshooting

| Issue | What to check |
|---|---|
| 401 on /api/events or /api/auth/me | App must send `Authorization: Bearer <token>`. Token is stored after OAuth redirect; if you never completed “Connect Google Drive” or cleared data, token is missing. |
| redirect_uri_mismatch | Redirect URI in Google Console and in `credentials.json` must match the URL used for the callback (scheme, host, path `/auth/google/callback`). |
| No clips / empty list | Events are per-user; only events with `ownerEmail` matching your logged-in email are returned. New uploads from Pi need device linking so `ownerEmail` is set. |
| Thumbnails or Play don’t load | Clip/thumbnail URLs must include `?token=...` (app adds this when logged in). If you open the same URL in a browser without the token, backend returns 401. |

# Integration summary: main + feature/frontend-auth

This doc describes what was merged from `main` into `feature/frontend-auth`, how it was integrated, and what is still missing or recommended.

---

## What came from main

- **HLS livestream**: Pi pushes segments to cloud; backend stores them in S3 and serves playlists.
  - `POST /api/stream/segment` — Pi uploads `.ts` segments.
  - `GET /api/stream/playlist/:deviceId` — returns HLS m3u8 with presigned S3 URLs.
  - `GET /api/stream/status/:deviceId` — stream liveness check.
- **S3 for event clips**: Event uploads (video + thumbnail) go to S3, not Google Drive.
  - `Event` model: `s3Key`, `thumbnailS3Key` (and existing fields).
  - `POST /api/events/upload` — uploads file to S3, creates/updates Event in MongoDB.
  - Clips/thumbnails served via presigned S3 URLs (redirect).
- **New/updated files**: `cloud-backend/hlsCache.js`, `cloud-backend/s3Client.js`, `cloud-backend/lifecycle.json`; `ESP32PairingApp/.../clips/HlsPlayerView.kt`; OTP/pairing changes in app.

---

## How it was integrated with auth

- **Auth and multi-user** (from feature/frontend-auth) are kept:
  - **Backend**: `auth.js` (Bearer token store), `requireAuth` / `requireAuthOrQueryToken`, per-user Google tokens in `googleAuth.js`, `Device` model and `POST /api/devices/link`, `Event.ownerEmail`.
  - **App**: Token and email stored after OAuth; `Authorization: Bearer` (or `?token=`) on cloud requests; clips/events only when logged in.
- **Event upload** (`POST /api/events/upload`):
  - Still uses **S3** (main’s flow): upload to S3, create/update Event with `s3Key` / `thumbnailS3Key`.
  - **Added**: Device lookup to set `ownerEmail` on the created/updated Event (from `Device` collection).
- **GET /api/events**:
  - **Auth**: `requireAuth`.
  - **Filter**: `Event.find({ ownerEmail: req.user.email })`.
  - **Response**: Same shape as main (`_id`, `id`, `deviceId`, `filename`, `createdAt`, `timestamp`, `status`, `hasVideo`, `hasThumbnail`).
- **GET /api/clips/:eventId** and **GET /api/clips/:eventId/thumbnail**:
  - **Auth**: `requireAuthOrQueryToken` (header or `?token=`).
  - **Access**: Only if `event.ownerEmail` is missing or equals `req.user.email`.
  - **Behavior**: Unchanged from main — redirect to presigned S3 URL.
- **Google Drive**: No longer used for **event clip storage**. OAuth is still used for **login only** (email + backend-issued Bearer token). Per-user Google tokens remain in `googleAuth.js` for possible future use (e.g. Drive export).

---

## What’s missing or optional

1. **Device linking in the app**  
   Backend has `POST /api/devices/link` (auth required, body `{ deviceId }`). The Android app does not yet call it. So Pi uploads have no linked user and `ownerEmail` is only set if you link the device via another client (e.g. curl/Postman). **Todo**: In the app, add a way to “link this device” (e.g. on Stream/Setup) that calls `/api/devices/link` with the Pi’s device ID and the current auth token.

2. **Events without owner**  
   Events created before linking (or without a linked device) have no `ownerEmail`. They are excluded from `GET /api/events` (filter is `ownerEmail: req.user.email`). So old or unlinked events won’t show in the app until you either backfill `ownerEmail` or add a separate “unassigned” flow. **Optional**: Backfill script or admin endpoint to set `ownerEmail` for existing events by deviceId.

3. **HLS stream auth**  
   `GET /api/stream/playlist/:deviceId` and `GET /api/stream/status/:deviceId` are **not** protected. Anyone with the deviceId can get the playlist. If you want stream access to be per-user, add `requireAuth` or `requireAuthOrQueryToken` and optionally restrict by linked device.

4. **S3 and env**  
   Main’s backend expects S3 (and possibly env vars for AWS). Ensure `s3Client.js` is configured (e.g. bucket, region, credentials) and that the app’s cloud URL points at this backend. See main’s docs or `.env.example` if present.

5. **driveUploader and Google Drive**  
   `driveUploader.js` and Drive-based clip serving were removed from the **merged** server (clips are S3-only). The file `driveUploader.js` still exists and is unchanged from our branch; it’s simply not imported in `server.js`. If you want to support **both** S3 and Drive (e.g. some events from S3, some from Drive), you’d need to extend the Event model and the clip/thumbnail routes to handle both (e.g. `s3Key` vs `driveFileId`).

6. **TESTING.md and new files**  
   `TESTING.md`, `cloud-backend/auth.js`, `cloud-backend/models/Device.js`, `cloud-backend/scripts/`, `cloud-backend/tests/` are currently untracked. Add and commit them if you want them in the repo.

---

## Quick checklist before push

- [ ] Run `cd cloud-backend && npm test` (auth tests pass).
- [ ] Backend starts with MongoDB and S3 (or mocks) configured.
- [ ] In the app: log in with Google → see “logged in as …”; load clips (only your events); log out.
- [ ] Optional: Link a device via `POST /api/devices/link`, then upload from Pi and confirm the new event appears for that user in the app.
- [ ] Optional: Test HLS stream in the app (playlist + status endpoints).

---

## File-level summary

| Area | From main | From feature/frontend-auth | Resolved / notes |
|---|---|---|---|
| **server.js** | S3 upload, HLS routes, S3 clip redirect | Auth middleware, Device, ownerEmail, OAuth callback with token | Merged: S3 + HLS kept; auth and ownerEmail added to events and clip/thumbnail routes. |
| **Event model** | s3Key, thumbnailS3Key | ownerEmail | Already merged (ownerEmail + S3 fields). |
| **MainActivity.kt** | HLS, aspectRatio, stream state | rememberScrollState, driveAccountEmail | Both kept. |
| **ApiConfig.kt** | STREAM_PLAYLIST, STREAM_STATUS, getStreamPlaylistUrl, getStreamStatusUrl | (none conflicting) | Auto-merged. |
| **rasberry_pi_app/backend/package-lock.json** | (main version) | (stash version) | Conflict resolved using main’s version. |

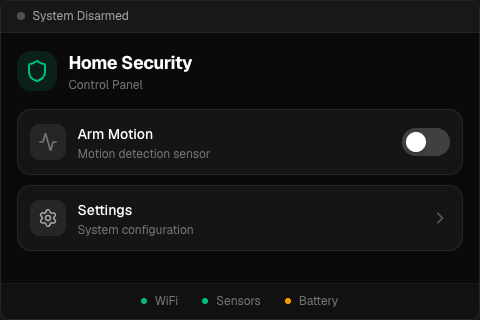
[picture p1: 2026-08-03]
ESPFirmwareV2/centralconsole_Station/UI Mockups/ui-Idle.png

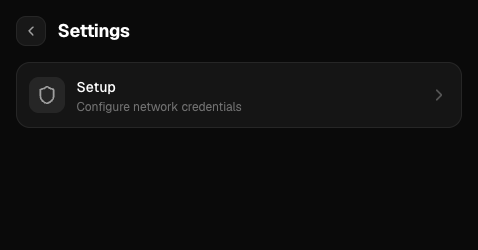
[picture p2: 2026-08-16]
ESPFirmwareV2/centralconsole_Station/UI Mockups/ui-settingspage.png

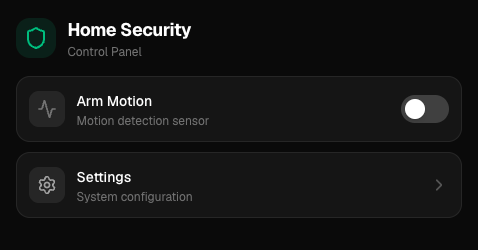
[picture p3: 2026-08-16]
ESPFirmwareV2/centralconsole_Station/UI Mockups/ui-homepageUNarmed.png

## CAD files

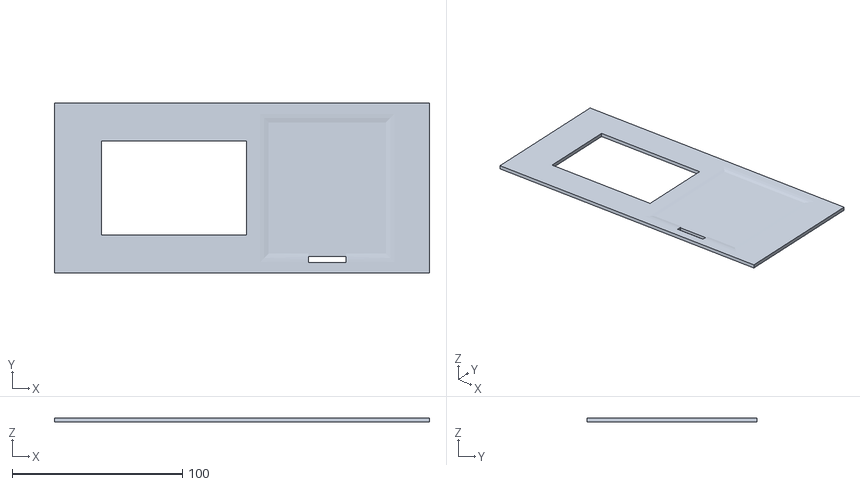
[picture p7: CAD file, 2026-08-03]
3D Models/LCDHousing.stl
220.0 x 100.0 x 2.50

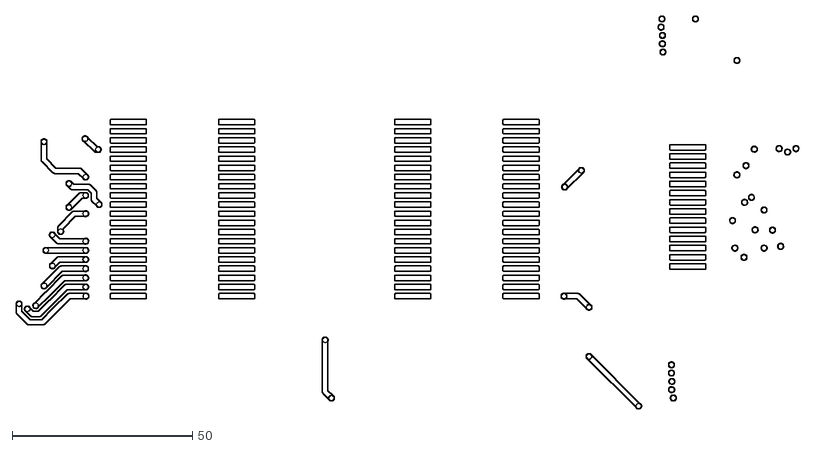
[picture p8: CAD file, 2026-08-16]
ESPFirmwareV2/Circuit/Circuit Drawings/HomeSecurity-Circuits-In1_Cu.dxf
216.9 x 108.9

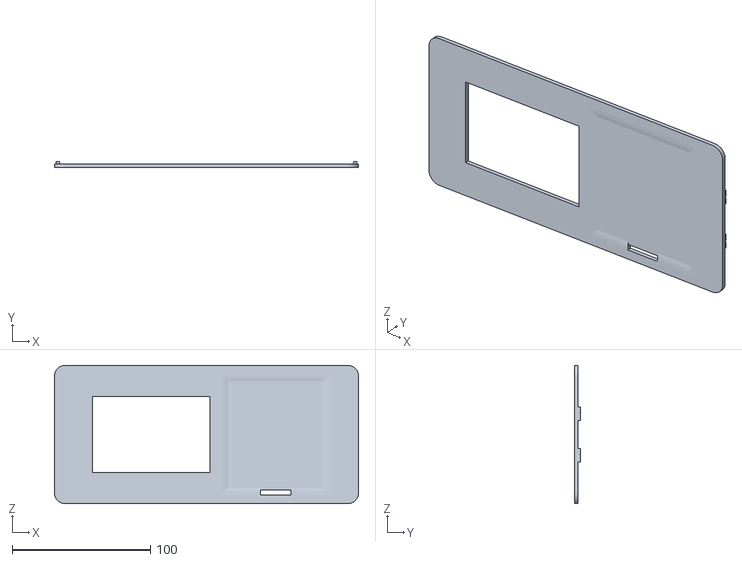
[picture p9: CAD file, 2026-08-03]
3D Models/Front Plate.obj
220.0 x 4.50 x 100.0

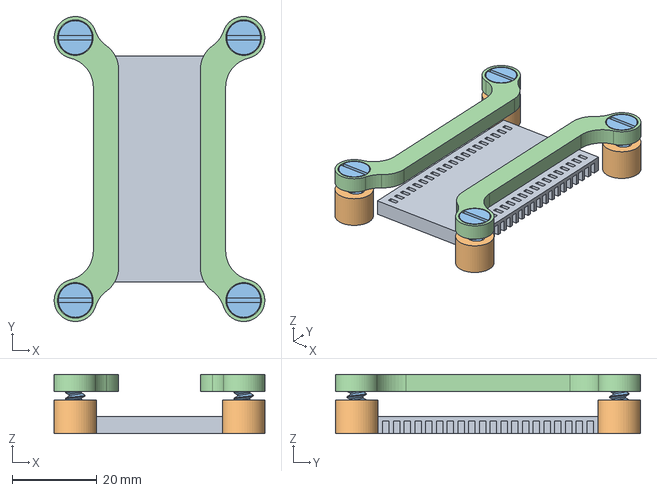
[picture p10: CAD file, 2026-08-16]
ESPFirmwareV2/3d-models/ESPsocketMount.step
49.8 x 72.1 x 14.0 mm
ESPsocket v2
ESPClampScrew v2 x 4

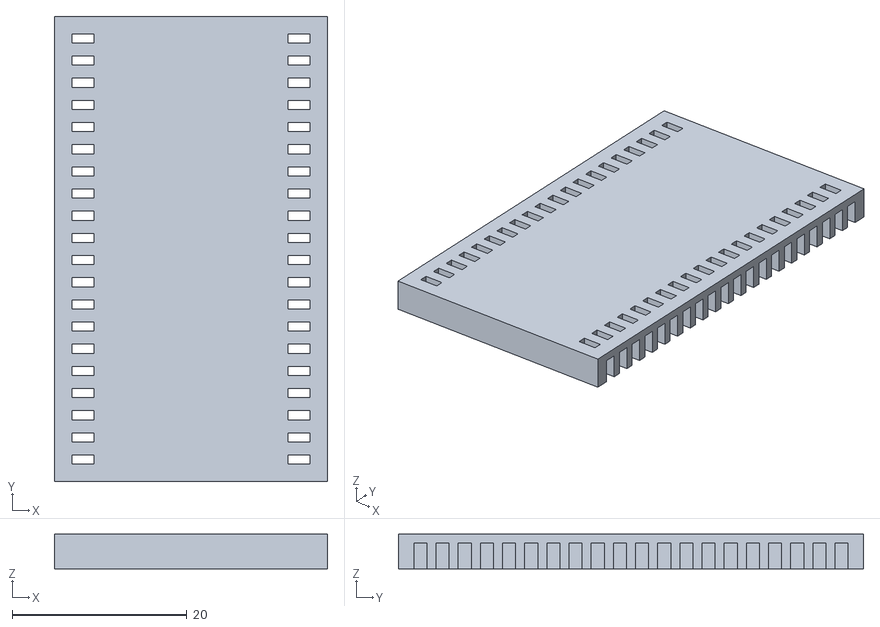
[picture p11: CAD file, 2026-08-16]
ESPFirmwareV2/3d-Print/UART + Display layout_UART + Display layout v8_ESPsocketMount v8_2_ESPsocket v2_1_Body4.stl
31.3 x 53.3 x 4.00

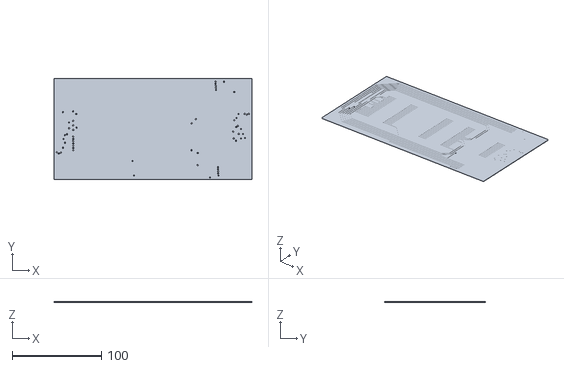
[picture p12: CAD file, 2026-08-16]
ESPFirmwareV2/Circuit/Circuit Drawings/(Unsaved)_(Unsaved)_Body2.stl
222.0 x 113.3 x 1.10

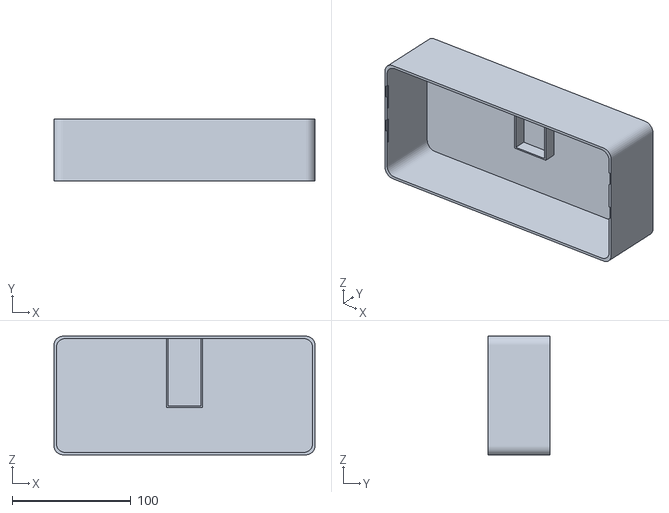
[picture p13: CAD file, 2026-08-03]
3D Models/Enclosure.obj
220.0 x 52.0 x 100.0

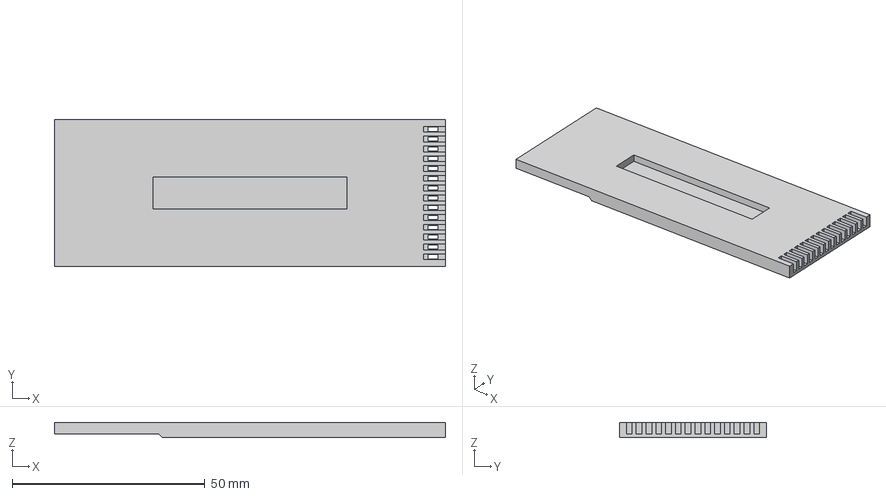
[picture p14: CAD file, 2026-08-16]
ESPFirmwareV2/3d-models/LCDSocket.step
101.3 x 38.1 x 4.00 mm

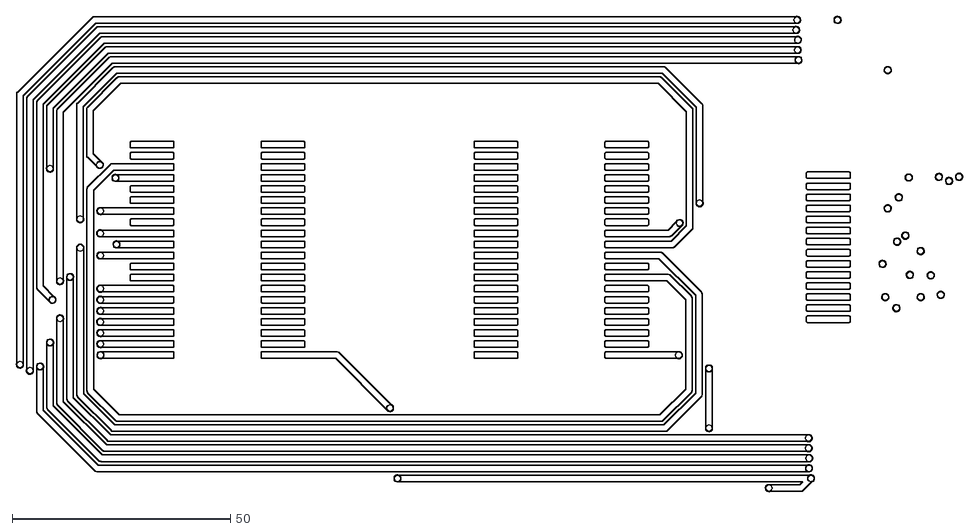
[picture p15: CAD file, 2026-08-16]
ESPFirmwareV2/Circuit/Circuit Drawings/HomeSecurity-Circuits-F_Cu.dxf
216.9 x 108.9

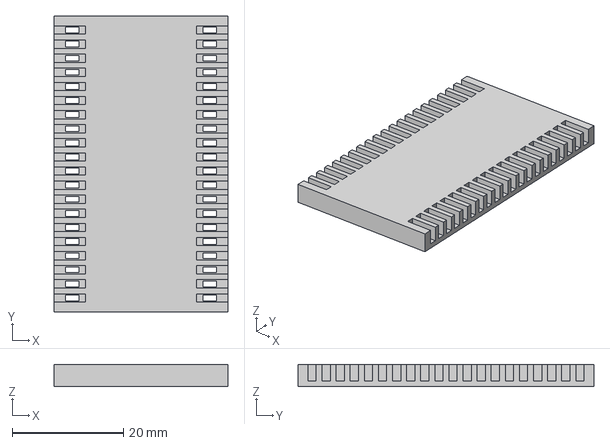
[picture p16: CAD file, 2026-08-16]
ESPFirmwareV2/3d-models/ESPsocket.step
31.3 x 53.3 x 4.00 mm

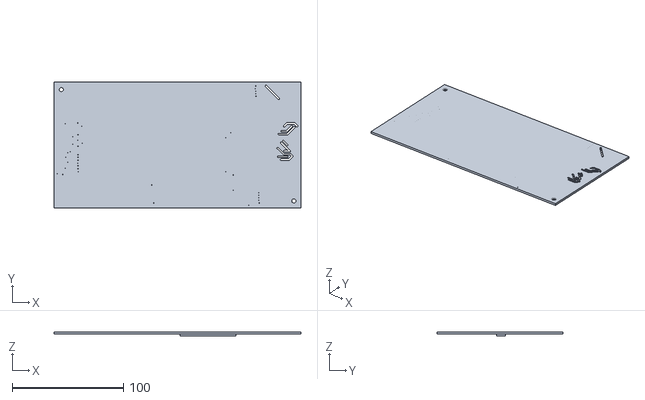
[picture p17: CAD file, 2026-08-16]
ESPFirmwareV2/3d-Print/UART + Display layout_UART + Display layout v8_Body14.stl
222.0 x 113.3 x 4.00

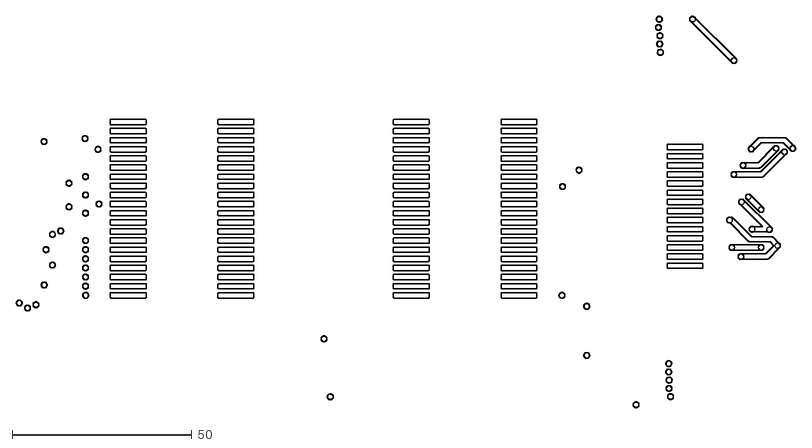
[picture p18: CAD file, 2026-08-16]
ESPFirmwareV2/Circuit/Circuit Drawings/HomeSecurity-Circuits-In2_Cu.dxf
216.9 x 108.9

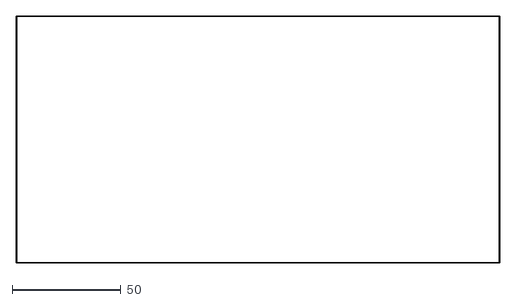
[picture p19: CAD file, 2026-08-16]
ESPFirmwareV2/Circuit/Circuit Drawings/HomeSecurity-Circuits-Edge_Cuts.dxf
222.1 x 113.4

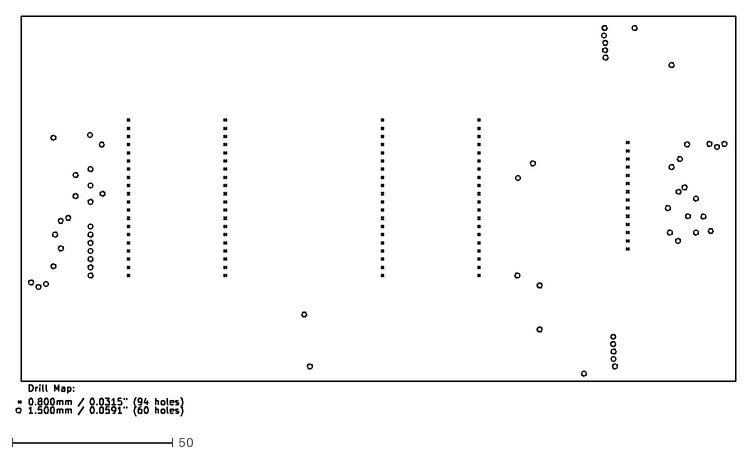
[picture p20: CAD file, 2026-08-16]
ESPFirmwareV2/Circuit/Circuit Drawings/HomeSecurity-Circuits-PTH-drl_map.dxf
223.5 x 124.1

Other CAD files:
ESPFirmwareV2/3d-Print/UART + Display layout_UART + Display layout v8_ESPsocketMount v8_1_ESPsocket v2_1_Body4.stl
ESPFirmwareV2/3d-Print/UART + Display layout_UART + Display layout v8_ESPsocketMount v8_2_Clamp2.stl
ESPFirmwareV2/Circuit/Circuit Drawings/HomeSecurity-Circuits-NPTH-drl_map.dxf
ESPFirmwareV2/Circuit/Circuit Drawings/(Unsaved)_(Unsaved)_Body1.stl
ESPFirmwareV2/3d-Print/UART + Display layout_UART + Display layout v8_Body12.stl
ESPFirmwareV2/3d-Print/UART + Display layout_UART + Display layout v8_ESPsocketMount v8_1_Clamp1.stl
ESPFirmwareV2/3d-Print/UART + Display layout_UART + Display layout v8_ESPsocketMount v8_1_Clamp2.stl
ESPFirmwareV2/3d-Print/UART + Display layout_UART + Display layout v8_ESPsocketMount v8_1_ESPClampScrew v2 (1)_1_ScrewHead.stl
ESPFirmwareV2/3d-Print/UART + Display layout_UART + Display layout v8_ESPsocketMount v8_1_ESPClampScrew v2 (2)_1_ScrewHead.stl
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

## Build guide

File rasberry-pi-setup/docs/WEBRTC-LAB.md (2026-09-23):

# WebRTC + shared camera feed (MediaMTX)

One process owns `/dev/video0` and publishes to MediaMTX. Live (WebRTC) and clips (RTSP record) both read that path — they no longer fight over the camera.

```
/dev/video0 → ffmpeg publisher (pi_hub.camera)
                    ↓
              MediaMTX path cam
               ├─ WebRTC :8889  → live
               └─ RTSP :8554    → clips.record_clip()
```

## Install MediaMTX (once, arm64 Pi)

```bash
cd /tmp
curl -fsSL -o mediamtx.tar.gz \
  https://github.com/bluenviron/mediamtx/releases/download/v1.19.3/mediamtx_v1.19.3_linux_arm64.tar.gz
tar -xzf mediamtx.tar.gz
sudo install -m 755 mediamtx /usr/local/bin/mediamtx
sudo mkdir -p /etc/mediamtx
sudo cp rasberry-pi-setup/mediamtx/mediamtx.yml /etc/mediamtx/
sudo cp rasberry-pi-setup/systemd/mediamtx.service /etc/systemd/system/
sudo systemctl daemon-reload
sudo systemctl enable --now mediamtx
```

`install-pi-setup.sh` copies the unit/config and starts MediaMTX if the binary exists.

## Hub behavior

| Call | Effect |
|---|---|
| Hub start | `camera.ensure_publisher()` — ffmpeg → `rtsp://127.0.0.1:8554/cam` |
| `POST /start` | Live session on; returns `webrtc_url` / `webrtc` URLs |
| `POST /stop` | Live session off; **publisher stays** for clips |
| `POST /motion` | `ffmpeg -i rtsp://.../cam -t 10` → `homesecurity/clips/` |
| Hub start | `detect.start()` — OpenCV DNN reads the same RTSP path, person → `/motion` pipeline |

The detector is a third consumer of the shared `cam` path, alongside WebRTC (live) and
ffmpeg (clips). It opens RTSP, never `/dev/video0`, so the single-publisher rule holds.

Play live: http://192.168.0.236:8889/cam · Tailscale: http://100.66.51.106:8889/cam

## Manual lab (without hub)

```bash
./scripts/webrtc-lab-mediamtx.sh --bg   # or systemctl start mediamtx
./scripts/webrtc-lab-publish.sh         # only if hub publisher is not running
```

Do **not** run the lab publish script while `pi_hub` publisher is active — both would try to open `/dev/video0`.

## Concurrent test

```bash
curl -s http://192.168.0.236:4000/health
# open browser on :8889/cam
curl -s -X POST http://192.168.0.236:4000/motion
# curl -s http://192.168.0.236:4000/clips/cache
curl -s http://192.168.0.236:4000/detect/status   # running, frames_sampled, last_detection
curl -s http://192.168.0.236:4000/auth/drive      # linked? last_upload? (after phone OAuth)
# sudo fuser -v /dev/video0  → should show only the publisher ffmpeg
# walk in front of the camera → events_raised increments, a clip lands in clips/
# if Drive is linked, the same clip appears in Drive folder SentriHome
```

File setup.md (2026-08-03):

# Home Security Backend

## Run the Node App

### 1. Navigate to the backend directory
```bash
cd backend
2. Install dependencies (first time only)
bash
Copy code
npm install
3. Verify FFmpeg is installed
bash
Copy code
ffmpeg -version
4. Start the server
bash
Copy code
npm start
or

bash
Copy code
node index.js
5. Expected output
text
Copy code
📹 Security Cam Backend Running
➡️ Press ENTER to simulate proximity sensor
6. Stop the server
bash
Copy code
Ctrl + C

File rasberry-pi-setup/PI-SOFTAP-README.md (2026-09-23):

# Pi SoftAP Provisioning System

Automatic WiFi setup for Raspberry Pi using SoftAP (Access Point) mode.

## How It Works

1. **Unconfigured Pi boots** → starts SoftAP "HomeSecurity-Setup" + HTTP API on `10.42.0.1:4000`
2. **Phone joins hotspot** → app discovers Pi at `10.42.0.1`
3. **App sends credentials** → `POST /wifi` with home WiFi SSID/password
4. **Pi switches to home WiFi** → saves credentials, connects as normal client
5. **Future boots (prod)** → Pi joins home WiFi (no SoftAP)
6. **DEV boots (`pie-dev-testing`)** → git pull, wipe wifi + Drive token + clip cache, SoftAP. After Google token **and** home WiFi creds, join LAN and start the hub.

## Architecture

```
┌─────────────────────────────────────────────────────────┐
│                    Pi Boot Sequence                      │
├─────────────────────────────────────────────────────────┤
│  1. systemd starts pi-setup.service                      │
│  2. pi-setup-boot.sh checks /home/koushik/wifi-creds.json│
│                                                           │
│  IF configured → connect to home WiFi ────────────────┐  │
│  IF NOT → start SoftAP + API                          │  │
│                                                        │  │
│  ┌──────────────────────────────────┐                │  │
│  │  SoftAP Mode (First Boot)        │                │  │
│  ├──────────────────────────────────┤                │  │
│  │  • SSID: HomeSecurity-Setup      │                │  │
│  │  • Password: setup1234           │                │  │
│  │  • Pi IP: 10.42.0.1              │                │  │
│  │  • DHCP: 10.42.0.10–.254         │                │  │
│  │  • API: :4000                    │                │  │
│  └──────────────────────────────────┘                │  │
│                                                        │  │
│  ┌──────────────────────────────────┐                │  │
│  │  Normal Mode (After Setup)       │◄───────────────┘  │
│  ├──────────────────────────────────┤                   │
│  │  • Connects to home WiFi         │                   │
│  │  • Static IP: 192.168.0.236      │                   │
│  │  • Starts pi_hub on :4000        │                   │
│  │    (live HLS + clips + Drive)    │                   │
│  └──────────────────────────────────┘                   │
└─────────────────────────────────────────────────────────┘
```

## Hub (after home Wi‑Fi)

SoftAP and hub never share `:4000` at the same time. Boot script:

1. SoftAP / unconfigured → `pi-setup-api.py` only  
2. Home Wi‑Fi OK → touch `.hub-ready` → `systemctl start pi-hub`

Shared camera: **one** ffmpeg publisher → MediaMTX; live uses WebRTC, clips record from the same RTSP path (see [docs/WEBRTC-LAB.md](docs/WEBRTC-LAB.md)).

| Method | Path | Module |
|---|---|---|
| GET | `/health` | hub (`mode: hub`, `publishing`, `webrtc`, `detection`, `drive`) |
| GET | `/` | redirect to `/dev` |
| GET | `/dev` | Drive sign-in portal (Google OAuth on the Pi) |
| POST | `/start` `/stop` | `pi_hub.live` (WebRTC session; publisher stays) |
| POST | `/motion` | `pi_hub.events` → `pi_hub.clips` (RTSP record) → `pi_hub.drive` |
| POST / GET / DELETE | `/auth/drive` | phone OAuth handoff; status; disconnect |
| GET | `/clips/cache` | local clip list (debug — app lists Drive, not this) |
| POST | `/detect/start` `/detect/stop` | `pi_hub.detect` (OpenCV DNN on the shared RTSP feed) |
| GET | `/detect/status` | detector state, counters, last detection |

Package: `pi_hub/` · units: `systemd/pi-hub.service`, `systemd/mediamtx.service`

### Object detection

`pi_hub.detect` reads the same MediaMTX RTSP path as clips (never `/dev/video0` —
`pi_hub.camera` owns that) and runs MobileNet-SSD through OpenCV's DNN module on a
background thread. A `person` above the confidence floor raises a motion event via
`pi_hub.events`, the identical path `POST /motion` uses, so detection and manual
triggers produce the same clip + Drive upload.

Weights are not in git. Fetch them (sha256-verified) once per Pi:

```bash
sudo ./scripts/fetch-detection-model.sh   # → homesecurity/models/
sudo systemctl restart pi-hub
curl -s http://localhost:4000/detect/status | jq
```

Tuning lives in `pi_hub/config.py`: `DETECT_TARGET_LABELS` (default `person` only —
a cat should not wake anyone), `DETECT_MIN_CONFIDENCE`, `DETECT_INTERVAL_SEC`
(inference sample rate, not frame rate) and `DETECT_COOLDOWN_SEC` (event
suppression window). Without weights or without OpenCV installed the hub still
boots and serves every other endpoint; `/detect/status` reports why detection is off.

Decision logic is unit tested without hardware:

```bash
cd rasberry-pi-setup && python3 -m unittest discover -s tests -v
```

### Google Drive uploads

Clips upload to the user's Drive once the phone completes OAuth and
`POST /auth/drive` (LAN or Tailscale only). Token is Fernet-encrypted at
`homesecurity/drive_token.json.enc`. Files land in an app-created **SentriHome**
folder (`drive.file` scope — not shared publicly).

Phone contract + Expo template: repo root `DOCUMENTATION.md`.

Until the app ships OAuth, open the Pi’s **dev portal** and sign in there:

```
http://192.168.0.236:4000/dev
http://100.66.51.106:4000/dev
```

Save a Google Cloud **Web application** client, add the callback URI shown on
the page, then **Connect Google Drive**. Clips then upload to a `SentriHome`
folder.

```bash
# after the phone (or curl) has posted credentials:
curl -s http://192.168.0.236:4000/auth/drive   # { linked, email, last_upload, error }
curl -s -X POST http://192.168.0.236:4000/motion
# Drive → SentriHome / clip-*.mp4
```

Re-deploy needs `pip3 install -r requirements.txt` (now includes `cryptography`).

## API Endpoints

### `GET /status`
Health check
```json
{
  "status": "ready",
  "mode": "setup",
  "device": "raspberry-pi-home-security"
}
```

### `GET /scan`
List available WiFi networks
```json
{
  "networks": [
    {"ssid": "HomeNetwork", "signal": 75, "security": "WPA2"},
    {"ssid": "Guest", "signal": 45, "security": "WPA2"}
  ]
}
```

### `POST /wifi`
Set WiFi credentials
```json
{
  "ssid": "HomeNetwork",
  "password": "mypassword"
}
```

Response:
```json
{
  "success": true,
  "message": "WiFi credentials saved, switching to home network..."
}
```

## Installation

On the Pi:

```bash
cd /path/to/Home-Security
chmod +x install-pi-setup.sh
sudo ./install-pi-setup.sh
sudo reboot
```

## Files

- `pi-setup-api.py` → Flask HTTP server for credential submission
- `pi-setup-boot.sh` → Boot script (checks config, starts SoftAP or connects)
- `pi-setup.service` → systemd service
- `install-pi-setup.sh` → One-command installer
- `/home/koushik/wifi-credentials.json` → Saved WiFi config (created on setup)

## Troubleshooting

### Check status
```bash
systemctl status pi-setup.service
tail -f /var/log/pi-setup.log
```

### Reset to SoftAP mode
```bash
sudo rm /home/koushik/wifi-credentials.json
sudo systemctl restart pi-setup.service
```

### Manual hotspot control
```bash
# Start SoftAP (also done automatically by pi-setup.service when unconfigured)
sudo nmcli connection up HomeSecurity-Setup

# Stop SoftAP, return to home WiFi
sudo nmcli connection down HomeSecurity-Setup
sudo nmcli connection up "<your-home-ssid>"
```

SoftAP should **start on its own** at boot when `/home/koushik/wifi-credentials.json` is missing.
You should not need to click **HomeSecurity-Setup** in the WiFi menu — that entry is only the NetworkManager profile.

### DHCP conflict (dnsmasq)
Fixed automatically by install script. Verify:
```bash
systemctl is-active dnsmasq  # should be: inactive
sudo ss -ulnp | grep :67     # should be empty when NOT in hotspot
```

## Mobile App Integration

See `mobile/app/(tabs)/setup.tsx` for React Native implementation.

Expected flow:
1. App guides user to join "HomeSecurity-Setup"
2. Once connected, app detects `10.42.0.1:4000`
3. App shows WiFi picker (from `GET /scan`)
4. User selects network + enters password
5. App sends `POST /wifi`
6. App instructs user to reconnect phone to home WiFi
7. App discovers Pi at `192.168.0.236` (mDNS or static IP)

## Network Summary

| Mode | Interface | IP | SSID | Purpose |
|---|---|---|---|---|
| **Setup** | wlan0 AP | 10.42.0.1 | HomeSecurity-Setup | First-time config |
| **Normal** | wlan0 STA | 192.168.0.236 | (home WiFi) | Day-to-day operation |

Home mode always uses NetworkManager **manual** IPv4 `192.168.0.236/24` (gateway `192.168.0.1`), applied on SoftAP provisioning and reasserted on every boot.

## Security Notes

- SoftAP password is hardcoded (`setup1234`) → change in `pi-setup-boot.sh` nmcli command
- API runs HTTP only (no TLS) → acceptable on isolated SoftAP; add TLS if needed
- Credentials stored plaintext in `/home/koushik/wifi-credentials.json` → restrict perms
- API requires root for `nmcli` → runs as root (systemd User=root)

## Next Steps

1. ✓ Pi SoftAP + HTTP API
2. ⏭ Mobile app setup screen (connect + credential submission)
3. ⏭ Boot automation (systemd service on Pi)
4. ⏭ mDNS discovery (optional alternative to static `.236`)

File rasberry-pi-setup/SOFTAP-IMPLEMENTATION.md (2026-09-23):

# Pi SoftAP Setup — Implementation Complete

## What We Built

A complete **WiFi provisioning system** for Raspberry Pi using SoftAP (Access Point mode), allowing first-time setup via mobile app without keyboard/monitor.

## Components

### 1. Pi Backend (`/`)

- **`pi-setup-api.py`** — Flask HTTP server
  - `GET /status` — health check
  - `GET /scan` — list available WiFi networks
  - `POST /wifi` — receive credentials, configure NetworkManager, switch to home WiFi

- **`pi-setup-boot.sh`** — Boot script
  - Checks if WiFi configured (`/home/koushik/wifi-credentials.json`)
  - If configured → connect to home WiFi
  - If not → start SoftAP + HTTP API

- **`pi-setup.service`** — systemd service
  - Runs boot script on startup
  - Logs to `/var/log/pi-setup.log`

- **`install-pi-setup.sh`** — One-command installer
  - Installs dependencies (Flask, jq)
  - Copies files and enables service

### 2. Mobile App (`/mobile`)

- **`app/(tabs)/setup.tsx`** — Provisioning screen
  - Instructions to join `HomeSecurity-Setup`
  - Network scan from Pi API
  - WiFi credential input
  - Submission to Pi
  - Device linking to cloud account

### 3. Documentation

- **`PI-SOFTAP-README.md`** — Architecture, API docs, troubleshooting
- **`mobile/README.md`** — Updated with SoftAP feature docs

## Network Flow

```
┌─────────────────────────────────────────┐
│         Unconfigured Pi Boots            │
├─────────────────────────────────────────┤
│  systemd → pi-setup.service             │
│  → pi-setup-boot.sh checks config       │
│  → no config → start SoftAP + API       │
└─────────────────────────────────────────┘
                  │
                  ▼
┌─────────────────────────────────────────┐
│         SoftAP Mode Active               │
├─────────────────────────────────────────┤
│  SSID: HomeSecurity-Setup                │
│  Password: setup1234                     │
│  Pi IP: 10.42.0.1                        │
│  API: http://10.42.0.1:4000              │
│  DHCP: 10.42.0.10–.254                   │
└─────────────────────────────────────────┘
                  │
                  ▼
┌─────────────────────────────────────────┐
│      Phone Joins Hotspot                 │
├─────────────────────────────────────────┤
│  1. User opens mobile app                │
│  2. App: GET /scan                       │
│  3. User selects network + password      │
│  4. App: POST /wifi {ssid, password}     │
└─────────────────────────────────────────┘
                  │
                  ▼
┌─────────────────────────────────────────┐
│      Pi Switches to Home WiFi            │
├─────────────────────────────────────────┤
│  • Saves credentials.json                │
│  • nmcli connection down Hotspot         │
│  • nmcli connection up HomeNetwork       │
│  • Now at 192.168.0.236 (static)         │
└─────────────────────────────────────────┘
                  │
                  ▼
┌─────────────────────────────────────────┐
│      Future Boots: Normal Mode           │
├─────────────────────────────────────────┤
│  boot → checks config → has credentials  │
│  → connects to home WiFi directly        │
│  → starts pi_hub (live + clips + Drive)  │
│     on :4000 — not the SoftAP setup API  │
└─────────────────────────────────────────┘
```

## Installation

### On the Pi:

```bash
cd /path/to/Home-Security
chmod +x install-pi-setup.sh
sudo ./install-pi-setup.sh
sudo reboot
```

After reboot, Pi will be in SoftAP mode (`HomeSecurity-Setup`).

### On the Mobile App:

```bash
cd mobile
npm install
npm start
```

Open Setup tab, follow on-screen instructions.

## Testing

1. **Fresh Pi (no config):**
   ```bash
   sudo rm /home/koushik/wifi-credentials.json
   sudo reboot
   ```
   Pi should broadcast `HomeSecurity-Setup`

2. **Join from phone:**
   - iOS/Android WiFi settings → join `HomeSecurity-Setup` / `setup1234`
   - Open mobile app → Setup tab → Scan Networks

3. **Submit credentials:**
   - Select home network
   - Enter password
   - Tap "Configure Pi"

4. **Verify switch:**
   - Pi should disappear from SoftAP
   - Reconnect phone to home WiFi
   - Pi should be at `192.168.0.236`
   - `ssh koushik@192.168.0.236` should work

5. **Check persistence:**
   ```bash
   sudo reboot
   ```
   Pi should auto-connect to home WiFi (no SoftAP)

## Issues Fixed

1. **DHCP port conflict** — `dnsmasq.service` was blocking NetworkManager's DHCP
   - Fixed: installer disables standalone dnsmasq
   
2. **Dual WiFi interfaces** — `ap0` + `wlan0` caused IP jumping
   - Fixed: disabled `99-wireless-ap.rules` udev rule
   
3. **Static IP for ESP compatibility** — ESP hardcodes Pi IP
   - Fixed: Pi uses static `192.168.0.236` on home WiFi

4. **5GHz visibility** — Phone couldn't see 2.4GHz channel 6
   - Fixed: switched to 5GHz band `a`, channel 36

## Security Notes

- SoftAP password is hardcoded (`setup1234`) — change in boot script if needed
- API is HTTP-only (no TLS) — acceptable on isolated SoftAP
- Credentials stored plaintext in `/home/koushik/wifi-credentials.json`
- API runs as root (required for `nmcli`) — runs via systemd

## What's Next

- [x] Pi SoftAP + HTTP API
- [x] Mobile app provisioning UI
- [x] Boot automation (systemd)
- [x] SoftAP → hub handoff + `pi_hub` barebones (`/health` `/start` `/stop` `/motion` `/auth/drive`)
- [x] OpenCV object detection on the shared RTSP feed (`pi_hub.detect`, MobileNet-SSD, person-gated)
- [x] Real clip record (`pi_hub.clips`) + Drive upload (`pi_hub.drive`)
- [x] Encrypt Drive token at rest
- [ ] Real ffmpeg HLS in `pi_hub.live` (live is WebRTC; HLS is leftover)
- [ ] mDNS discovery (`homesecurity.local`) instead of hardcoded IP

## Layout

```
rasberry-pi-setup/
├── pi-setup-api.py           # SoftAP-only Flask (:4000 in setup mode)
├── pi-setup-boot.sh          # Gate: SoftAP vs start pi-hub
├── pi_hub/                   # Product hub after home Wi‑Fi
│   ├── app.py                # One Flask process :4000
│   ├── camera.py             # sole owner of /dev/video0 → MediaMTX
│   ├── live.py               # WebRTC session (HLS legacy)
│   ├── clips.py              # local clip cache
│   ├── detect.py             # OpenCV DNN person detection on RTSP
│   ├── events.py             # shared motion pipeline (clip → Drive)
│   └── drive.py              # encrypted token store + Drive upload
├── scripts/
│   └── fetch-detection-model.sh   # sha256-verified MobileNet-SSD weights
├── tests/
│   ├── test_detect.py        # detection gating / cooldown / backoff
│   └── test_drive.py         # token store + mocked Drive upload
├── systemd/
│   ├── pi-setup.service
│   └── pi-hub.service
├── install-pi-setup.sh
├── deploy-to-pi.sh
└── requirements.txt
```

## Quick Reference

| What | Where | Command |
|---|---|---|
| Start SoftAP | Pi | `sudo nmcli connection up Hotspot` |
| Stop SoftAP | Pi | `sudo nmcli connection down Hotspot` |
| View logs | Pi | `tail -f /var/log/pi-setup.log` |
| Reset config | Pi | `sudo rm /home/koushik/wifi-credentials.json && sudo reboot` |
| Check service | Pi | `systemctl status pi-setup.service` |
| Pi SoftAP IP | Mobile | `http://10.42.0.1:4000` |
| Pi home IP | Mobile | `http://192.168.0.236:4000` |

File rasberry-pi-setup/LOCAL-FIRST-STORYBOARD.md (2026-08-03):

# Local-First Architecture Storyboard

> **Status:** `Draft` · **Stack:** React Native (`mobile/`) · **Docs only** (no feature code in this revision)  
> **Last updated:** 2026-08-03  
> Edit this file on GitHub: open → pencil → change one Act or one Decision Log row → commit.

---

## Quick nav

| Jump | Section |
|---|---|
| [Decisions](#decision-log) | Locked product choices |
| [Big picture](#architecture) | System diagram |
| [Act 1](#act-1--setup-baseline) | SoftAP, Pi IP, Tailscale, pairing |
| [Act 2](#act-2--intruder-alert--android-fcm) | Android FCM alerts |
| [Act 3](#act-3--intruder-alert--ios-ntfysh) | iOS ntfy.sh alerts |
| [Act 4](#act-4--on-demand-livestream-tailscale) | Live only while app is open |
| [Act 5](#act-5--clips-pi-cache--drive--app) | Cache → Drive → app |
| [Act 6](#act-6--tbd-esp-discovers-pi) | ESP ↔ Pi discovery (unfinished) |
| [Out of scope](#out-of-scope) | Explicit non-goals |
| [Later](#implementation-notes-later) | Pointers for future PRs |

---

## Decision log

> Add a new row when a choice changes. Keep **Choice** short so the table stays scannable in the GitHub editor.

| ID | Decision | Choice | Date | Notes |
|----|---|---|---|---|
| D1 | Mobile client | React Native Expo app in `mobile/` | 2026-08-02 | Dev/prod build for push; not Expo Go |
| D2 | Android alerts | `expo-notifications` + **FCM** | 2026-08-02 | Pi sends FCM on motion |
| D3 | iOS alerts | Public **ntfy.sh** | 2026-08-02 | Secret topic; no Tailscale required for the buzz |
| D4 | Livestream path | **Tailscale** to Pi | 2026-08-02 | On-demand when app is open only |
| D5 | Alert transport | **No** persistent WebSocket | 2026-08-02 | FCM / ntfy wake the user |
| D6 | Clip storage | Pi **cache** → **Google Drive** | 2026-08-02 | App reads Drive; no Tailscale for clips |
| D7 | Drive auth | Phone Google OAuth → **refresh token** to Pi | 2026-08-02 | Not password; `drive.file` scope |
| D8 | Remote product tunnel | Tailscale (not ngrok/Cloudflare as product) | 2026-08-02 | ngrok OK for ad-hoc dev only |
| D9 | ESP ↔ Pi discovery | **TBD** | 2026-08-02 | mDNS or static IP — see Act 6 |
| D10 | Cloud S3 / cloud-backend clips | Retire as product path | 2026-08-02 | Local-first + Drive instead |
| D20 | Pi product software | Python SoftAP + one `pi_hub` (not Node `rasberry_pi_app`) | 2026-08-03 | Canonical: root README D20 / §13; deploy via `rasberry-pi-setup/deploy-to-pi.sh` |

---

## Architecture

```mermaid
flowchart TB
  subgraph detect [Detection]
    Cam[Camera]
    Pi[Raspberry Pi]
    Cam --> Pi
  end

  subgraph alert [Alerts no websocket]
    FCM[FCM Android]
    Ntfy[ntfy.sh iOS]
    Pi -->|motion| FCM
    Pi -->|motion| Ntfy
  end

  subgraph phone [Phone app]
    App[React Native app]
    FCM -->|tap notification| App
    Ntfy -->|tap or open app| App
  end

  subgraph live [Live on demand]
    TS[Tailscale]
    App -->|while foreground| TS
    TS --> Pi
    Pi -->|HLS| App
  end

  subgraph clips [Clips no Tailscale]
    Cache[Pi local cache]
    Drive[Google Drive]
    Pi --> Cache
    Cache -->|upload with refresh token| Drive
    App -->|list and play as user| Drive
  end
```

### Google token handoff

```mermaid
sequenceDiagram
  participant App
  participant Google
  participant Pi
  participant Drive
  App->>Google: OAuth offline consent drive.file
  Google-->>App: refresh_token plus email
  App->>Pi: POST token over LAN or Tailscale
  Pi->>Pi: Store refresh_token encrypted at rest
  Pi->>Drive: Upload clip with refreshed access_token
  App->>Drive: List or play clips as signed-in user
```

<details>
<summary><strong>Security notes (token handoff)</strong></summary>

- Hand off only over **home LAN** or **Tailscale** — never over a raw public URL without auth.
- Store on Pi **encrypted at rest**; never write tokens to app logs or `pi-setup.log`.
- Scope: `https://www.googleapis.com/auth/drive.file` only (create/manage files the app opens).
- Provide a **revoke / re-auth** path in Settings if Drive uploads start failing.
- Future code may adapt helpers from `cloud-backend/googleAuth.js` and `cloud-backend/driveUploader.js` onto the Pi.

</details>

---

## Act 1 — Setup baseline

| | |
|--|--|
| **Goal** | Pi on home Wi‑Fi with known address; phone can reach Pi on LAN; Tailscale ready for away-live; app holds Pi host |
| **Actors** | Phone app · Pi SoftAP · Home Wi‑Fi · Tailscale · User |

### Flow

1. Unconfigured Pi boots SoftAP (`HomeSecurity-Setup` / setup path in `PI-SOFTAP-README.md`).
2. User joins SoftAP; app wizard sends home Wi‑Fi credentials (`mobile` Setup · Act already started).
3. Pi joins home LAN at static IP **`192.168.0.236`** (already enforced on device).
4. App verifies Pi (`GET /health`), **saves Pi host**.
5. User installs **Tailscale** on Pi and phone (same tailnet); note MagicDNS / `100.x` host for Act 4.
6. *(Future)* App pairs a long-lived **device token** with the Pi for API auth.

### Build checklist

- [x] SoftAP → home Wi‑Fi → hub handoff (`pi_hub` on `:4000`) — see `PI-SOFTAP-README.md`
- [ ] Persist Pi host in app storage / Settings
- [ ] Document Tailscale install steps for Pi + phone
- [ ] Define app↔Pi paired token API (future PR)
- [ ] Real ffmpeg live + Drive upload (stubs in `pi_hub/`)

### Test protocol — Act 1

| # | Step | Expected | Pass |
|---|---|---|---|
| 1.1 | Preconditions: Pi in SoftAP or “Skip — already on LAN” | Setup screen usable | [ ] |
| 1.2 | Complete SoftAP creds or skip; phone on home Wi‑Fi | `GET http://192.168.0.236:4000/health` succeeds | [ ] |
| 1.3 | Kill and reopen app | Saved Pi host still present in Settings / Live meta | [ ] |
| 1.4 | Tailscale connected on Pi and phone | `tailscale status` shows both; ping Pi MagicDNS or `100.x` works | [ ] |
| 1.5 | **Fail:** phone on cellular, Tailscale **off**, hit LAN IP | Health fails; UI shows clear “unreachable” (not hang) | [ ] |

**Failure modes:** SoftAP scan fails → not on `HomeSecurity-Setup`. Health 404/timeout → backend not listening on `:4000`. Wrong subnet → static IP mismatch.

---

## Act 2 — Intruder alert — Android (FCM)

| | |
|--|--|
| **Goal** | Locked / killed Android app still gets a motion notification; tap opens the app |
| **Actors** | Pi · Firebase FCM · Expo notifications · Android phone |

### Flow

1. Dev/prod build registers for push (`expo-notifications` + FCM).
2. App sends **FCM device token** to Pi (LAN or Tailscale) once paired.
3. On motion, Pi POSTs to FCM with title/body (and optional deep link data).
4. OS shows lock-screen notification.
5. User taps → app opens (Live or Alerts screen). **No** background WebSocket.

### Build checklist

- [ ] Firebase project + `google-services.json` for the app
- [ ] `expo-notifications` in a **development/production** build (not Expo Go)
- [ ] Pi endpoint: register token; Pi sender using FCM HTTP v1
- [ ] Notification tap → navigate to Live / event

### Test protocol — Act 2

| # | Step | Expected | Pass |
|---|---|---|---|
| 2.1 | Preconditions: paired token on Pi; notifications allowed | Token stored on Pi | [ ] |
| 2.2 | Force-stop app; lock screen | App not in recents / not foreground | [ ] |
| 2.3 | Trigger motion on Pi (or `POST` test alert) | Notification within **≤ 15 s** | [ ] |
| 2.4 | Tap notification | App opens to agreed screen | [ ] |
| 2.5 | **Fail:** revoke FCM token / wrong project | Pi logs send error; no silent success | [ ] |
| 2.6 | **Fail:** notifications disabled in OS | First launch prompts or Settings CTA | [ ] |

**Failure modes:** Expo Go used → push unreliable/wrong app id. Token never uploaded → Pi has nothing to target. Clock/network on Pi blocked to Google → send fails.

---

## Act 3 — Intruder alert — iOS (ntfy.sh)

| | |
|--|--|
| **Goal** | iPhone gets motion buzz via public ntfy without Tailscale for the alert itself |
| **Actors** | Pi · ntfy.sh · iOS ntfy app (or in-app subscribe later) · User |

### Flow

1. Generate a **high-entropy secret topic** (treat like a password); store on Pi and show once in app Settings.
2. User subscribes to `https://ntfy.sh/<topic>` (ntfy iOS app for v1).
3. On motion, Pi `POST`s to `https://ntfy.sh/<topic>` with message body.
4. User sees notification; opens Home Security app when ready.
5. Livestream still uses Act 4 (Tailscale) after open — ntfy does not carry video.

### Build checklist

- [ ] Pi config: `NTFY_TOPIC` (secret)
- [ ] Pi motion hook: HTTP POST to ntfy.sh
- [ ] App Settings: show topic + deep link / copy for ntfy app
- [ ] Optional later: in-app ntfy subscribe without separate app

### Test protocol — Act 3

| # | Step | Expected | Pass |
|---|---|---|---|
| 3.1 | Preconditions: topic set; ntfy app subscribed; Pi online | Subscription active | [ ] |
| 3.2 | Lock iPhone; Home Security app not required to be open | — | [ ] |
| 3.3 | Trigger motion / test POST from Pi | ntfy notification within **≤ 15 s** | [ ] |
| 3.4 | Open Home Security app after tap or manually | App can proceed to Live (Act 4) if Tailscale up | [ ] |
| 3.5 | **Fail:** wrong topic | No notification on phone; Pi POST still 200 to unused topic — verify topic match in Settings | [ ] |
| 3.6 | **Fail:** guessable topic | Document rejection; rotate topic in test | [ ] |

**Failure modes:** Topic leaked → strangers can spam or snoop titles. ntfy.sh outage → no iOS buzz (LAN Live still works). User never subscribed → silent miss.

<details>
<summary><strong>Example Pi test POST</strong></summary>

```bash
curl -d "Intruder detected" \
  -H "Title: Home Security" \
  -H "Priority: high" \
  https://ntfy.sh/YOUR_SECRET_TOPIC
```

</details>

---

## Act 4 — On-demand livestream (Tailscale)

| | |
|--|--|
| **Goal** | User watches live **only while the app is open**, reaching the Pi through Tailscale when away |
| **Actors** | App · Tailscale · Pi HLS/backend |

### Flow

1. User opens app (often from FCM/ntfy tap).
2. App resolves Pi base URL: prefer **Tailscale host** when off LAN; else saved LAN IP.
3. Optional: `POST /start` (or equivalent) then play **HLS** from Pi.
4. User leaves app → stop requesting segments; **no** persistent alert socket.
5. If Tailscale disconnected → clear error: enable Tailscale or join home Wi‑Fi.

### Build checklist

- [ ] Configurable Pi base URL: LAN + Tailscale hostname
- [ ] Live player against Pi HLS
- [ ] Start/stop stream when entering/leaving Live screen
- [ ] Reachability check before play

### Test protocol — Act 4

| # | Step | Expected | Pass |
|---|---|---|---|
| 4.1 | Preconditions: Pi streaming stack up; Tailscale on phone + Pi | Both online in `tailscale status` | [ ] |
| 4.2 | Phone on cellular; open Live | HLS plays via Tailscale host within **≤ 10 s** to first frame (or documented budget) | [ ] |
| 4.3 | Leave Live / background app | Pi stop called or segment fetches cease (no forever download) | [ ] |
| 4.4 | Disable Tailscale on phone; stay on cellular; open Live | Clear unreachable error; no infinite spinner | [ ] |
| 4.5 | Re-enable Tailscale; retry | Stream recovers | [ ] |
| 4.6 | On home Wi‑Fi without Tailscale | LAN IP path still plays | [ ] |

**Failure modes:** Playing LAN IP while away → timeout. Firewall/CGNAT rare with Tailscale but DERP relay may add latency. Heavy cellular data — warn in UI if needed.

---

## Act 5 — Clips: Pi cache → Drive → app

| | |
|--|--|
| **Goal** | Event clips land on Pi disk first, upload to the **user’s** Google Drive; app browses Drive **without** Tailscale |
| **Actors** | App · Google OAuth · Pi · Drive API |

### Flow

1. User signs into Google **in the phone app** (`access_type=offline`, `drive.file`).
2. App sends **refresh token + email** to Pi over LAN or Tailscale (Act 1 path).
3. On event: Pi writes clip to **local cache**, then uploads to Drive with refreshed access token.
4. App lists/plays clips via **Drive** (user session), not via Tailscale video tunnel.
5. Pi may delete or prune local cache after successful upload (policy TBD in implementation).

### Build checklist

- [ ] App Google OAuth (Expo Auth Session / similar)
- [ ] `POST` handoff endpoint on Pi; encrypted token store
- [ ] Pi: cache file → Drive upload job + retry
- [ ] App Clips tab: Drive-backed list/playback
- [ ] Re-auth UX when refresh token revoked

### Test protocol — Act 5

| # | Step | Expected | Pass |
|---|---|---|---|
| 5.1 | Preconditions: OAuth done; handoff succeeded; Pi has token | Pi status shows Drive linked | [ ] |
| 5.2 | Trigger event that produces a clip | File appears under Pi cache path within budget | [ ] |
| 5.3 | Wait for upload | File appears in user’s Drive (agreed folder) | [ ] |
| 5.4 | Phone on cellular; **Tailscale off**; open Clips in app | Clip listed and playable from Drive | [ ] |
| 5.5 | **Fail:** revoke Google access in account settings | Next upload fails loudly; app prompts re-auth | [ ] |
| 5.6 | **Fail:** handoff over public unauthenticated URL | Must be rejected or unreachable in design — verify only LAN/TS | [ ] |

**Failure modes:** Missing `prompt=consent` → no refresh token. Upload quota / Drive API errors. App using wrong Google account vs token on Pi.

---

## Act 6 — TBD: ESP discovers Pi

| | |
|--|--|
| **Goal** | ESP32 finds the Pi on the home network after provisioning (**not designed yet**) |
| **Actors** | ESP32 · Pi · Home LAN |
| **Status** | `TBD` — do not implement in the push/Drive/Tailscale PRs |

### Candidates (pick later)

| Option | Idea | Pros | Cons |
|---|---|---|---|
| Static IP | Pi stays `192.168.0.236`; ESP configured with that IP (wizard / `setmasterip`) | Simple; already assumed in SoftAP docs | Breaks if subnet changes |
| mDNS | Pi advertises e.g. `homesecurity-pi.local` | No hard-coded IP | mDNS flaky on some APs / ESP stacks |
| Hybrid | Static default + mDNS fallback | Resilient | More firmware/app work |

### Build checklist (placeholder)

- [ ] Decide static vs mDNS vs hybrid
- [ ] ESP firmware API to set/resolve Pi base URL
- [ ] Wizard step: pass Pi host from phone → ESP (after Act 1)
- [ ] Test protocol once decision lands

### Test protocol — Act 6

> Fill in after D9 is resolved. Until then: **skip**.

| # | Step | Expected | Pass |
|---|---|---|---|
| 6.x | _TBD_ | _TBD_ | [ ] |

---

## Out of scope

| Item | Why |
|---|-----|
| Persistent WebSocket / SSE for alerts | Replaced by FCM + ntfy |
| S3 / cloud-backend as clip or live CDN | Local-first + Drive |
| Cloudflare Tunnel / ngrok as **product** remote access | Tailscale chosen; ngrok OK for brief dev |
| Replacing SoftAP Pi Wi‑Fi wizard | Keep SoftAP; extend with `pi_hub` after Wi‑Fi (D20) |
| Reviving Node `rasberry_pi_app` + cloud `:3001` as product | Retired — Python hub (README D20) |
| Implementing ESP discovery in this doc’s “done” criteria | Act 6 is explicitly TBD |
| Relying on Expo Go for FCM | Use dev/prod builds |

---

## Implementation notes (later)

| Area | Starting points in repo |
|---|---|
| SoftAP / Pi IP | `mobile/app/(tabs)/setup.tsx`, `PI-SOFTAP-README.md`, `pi-setup-api.py` |
| Pi host persistence | `mobile/context/SetupWizardContext.tsx`, `mobile/lib/storage.ts` |
| Drive OAuth patterns | `cloud-backend/googleAuth.js`, `cloud-backend/driveUploader.js` (port to Pi later) |
| Legacy cloud alerts | `cloud-backend` SSE / `MotionAlert` — retire for product path |
| Android pairing reference | `ESP32PairingApp` local notifications (not FCM) |

---

## How to edit this storyboard on GitHub

1. Open this file in the repo on github.com.
2. Click the pencil (**Edit**).
3. Prefer editing:
   - one **Decision log** row, or
   - one **Act** block (flow / checklist / test table).
4. Keep Act headings as `## Act N — …` so Quick nav anchors stay stable.
5. Mermaid: keep node IDs without spaces; quote labels that contain punctuation.
6. Check boxes in test tables with `[x]` when a protocol pass is recorded in a PR description or commit.

---

## Revision history

| Date | Change |
|---|---|
| 2026-08-02 | Initial draft: FCM Android, ntfy.sh iOS, Tailscale live-on-demand, Drive clips + OAuth handoff, ESP TBD |
| 2026-08-03 | D20: Python SoftAP + `pi_hub`; reject Node cloud hub as product; Act 1 checklist points at deploy docs |

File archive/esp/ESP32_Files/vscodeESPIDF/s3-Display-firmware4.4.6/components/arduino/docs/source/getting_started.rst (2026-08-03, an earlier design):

###############
Getting Started
###############

About Arduino ESP32
-------------------

Welcome to the Arduino ESP32 support documentation! Here you will find important information on how to use the project.

First Things First
------------------

.. note::
    Before continuing, we must be clear that this project is supported by `Espressif Systems`_ and the community.
    Everyone is more than welcome to contribute back to this project.

ESP32 is a single 2.4 GHz Wi-Fi-and-Bluetooth SoC (System On a Chip) designed by `Espressif Systems`_.

ESP32 is designed for mobile, wearable electronics, and Internet-of-Things (IoT) applications. It features all the state-of-the-art characteristics 
of low-power chips, including fine-grained clock gating, multiple power modes,and dynamic power scaling. For instance, in a low-power IoT sensor 
hub application scenario, ESP32 is woken-up periodically and only when a specified condition is detected. Low-duty cycle is used to minimize the 
amount of energy that the chip expends. 

The output of the power amplifier is also adjustable, thus contributing to an optimal trade-off between communication range, data rate and 
power consumption.

The ESP32 series is available as a chip or module.

.. _supported_socs:

Supported SoC's
---------------

Here are the ESP32 series supported by the Arduino-ESP32 project:

======== ====== =========== ===================================
SoC      Stable Development Datasheet
======== ====== =========== ===================================
ESP32    Yes    Yes         `ESP32`_
ESP32-S2 Yes    Yes         `ESP32-S2`_
ESP32-C3 Yes    Yes         `ESP32-C3`_
ESP32-S3 Yes    Yes         `ESP32-S3`_
======== ====== =========== ===================================

See `Boards <boards/boards.html>`_ for more details about ESP32 development boards.

Arduino Core Reference
----------------------

This documentation is built on the ESP32 and we are not going to cover the common Arduino API. To see the Arduino reference documentation, 
please consider reading the official documentation.

Arduino Official Documentation: `Arduino Reference`_.

Supported Operating Systems
---------------------------

+-------------------+-------------------+-------------------+
|     |       |       |
+-------------------+-------------------+-------------------+
| Windows           | Linux             | macOS             |
+-------------------+-------------------+-------------------+





Supported IDEs
---------------------------

Here is the list of supported IDE for Arduino ESP32 support integration.

+-------------------+-------------------+
|     |         |
+-------------------+-------------------+
| Arduino IDE       | PlatformIO        |
+-------------------+-------------------+




See `Installing Guides <installing.html>`_ for more details on how to install the Arduino ESP32 support.

Support
-------

This is an open project and it's supported by the community. Fell free to ask for help in one of the community channels.

Community
---------

The Arduino community is huge! You can find a lot of useful content on the Internet.
Here are some community channels where you may find information and ask for some help, if needed.

- `ESP32 Forum`_: Official Espressif Forum.
- `ESP32 Forum - Arduino`_: Official Espressif Forum for Arduino related discussions.
- `ESP32 Forum - Hardware`_: Official Espressif Forum for Hardware related discussions.
- `Gitter`_
- `Espressif MCUs (Discord)`_
- `ESP32 on Reddit`_

Issues Reporting
----------------

Before opening a new issue, please read this: 

Be sure to search for a similar reported issue. This avoids duplicating or creating noise in the GitHub Issues reporting.
We also have the troubleshooting guide to save your time on the most common issues reported by users.

For more details about creating new Issue, see the `Issue Template <https://github.com/espressif/arduino-esp32/blob/master/.github/ISSUE_TEMPLATE/Issue-report.yml>`_.

If you have any new idea, see the `Feature request Template <https://github.com/espressif/arduino-esp32/blob/master/.github/ISSUE_TEMPLATE/Feature-request.yml>`_.

First Steps
-----------

Here are the first steps to get the Arduino ESP32 support running.

To install Arduino-ESP32, please see the dedicated section on the Installation guide. We recommend you install it using the boards manager.

.. toctree::
    :maxdepth: 2
    
    How to Install <installing>
    Development Boards <boards/boards>

Examples
--------

After installing the toolchain into your environment, you will be able to see all the dedicated examples for the ESP32. These examples are located
in the examples menu or inside each library folder.

    https://github.com/espressif/arduino-esp32/tree/master/libraries

There is also a `list of examples <https://techtutorialsx.com/category/esp32/>`_ managed outside of Espressif, so check them out.

.. include:: common/datasheet.inc

Resources
---------

.. _Espressif Systems: https://www.espressif.com 
.. _Espressif Product Selector: https://products.espressif.com/
.. _Arduino.cc: https://www.arduino.cc/en/Main/Software
.. _Arduino Reference: https://www.arduino.cc/reference/en/
.. _ESP32 Forum: https://esp32.com
.. _ESP32 Forum - Arduino: https://esp32.com/viewforum.php?f=19
.. _ESP32 Forum - Hardware: https://esp32.com/viewforum.php?f=12
.. _Gitter: https://gitter.im/espressif/arduino-esp32
.. _Adafruit (Discord): https://discord.gg/adafruit
.. _Espressif MCUs (Discord): https://discord.gg/nKxMTnkD
.. _ESP32 on Reddit: https://www.reddit.com/r/esp32

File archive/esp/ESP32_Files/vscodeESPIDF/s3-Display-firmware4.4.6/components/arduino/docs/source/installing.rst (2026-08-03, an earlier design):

##########
Installing
##########

This guide will show how to install the Arduino-ESP32 support.

Before Installing
-----------------

We recommend you install the support using your favorite IDE, but other options are available depending on your operating system. 
To install Arduino-ESP32 support, you can use one of the following options.

Installing using Arduino IDE
----------------------------



This is the way to install Arduino-ESP32 directly from the Arduino IDE.

.. note::
   For overview of SoC's support, take a look on `Supported Soc's table <https://docs.espressif.com/projects/arduino-esp32/en/latest/getting_started.html#supported-soc-s>`_ where you can find if the particular chip is under stable or development release.

- Stable release link::

   https://espressif.github.io/arduino-esp32/package_esp32_index.json

- Development release link::

   https://espressif.github.io/arduino-esp32/package_esp32_dev_index.json

.. note::
   Starting with the Arduino IDE version 1.6.4, Arduino allows installation of third-party platform 
   packages using Boards Manager. We have packages available for Windows, macOS, and Linux.

To start the installation process using the Boards Managaer, follow these steps:

-  Install the current upstream Arduino IDE at the 1.8 level or later. The current version is at the `arduino.cc`_ website.

-  Start Arduino and open the Preferences window.



-  Enter one of the release links above into *Additional Board Manager URLs* field. You can add multiple URLs, separating them with commas.



-  Open Boards Manager from Tools > Board menu and install *esp32* platform (and do not forget to select your ESP32 board from Tools > Board menu after installation).



- Restart Arduino IDE.

Installing using PlatformIO
---------------------------



PlatformIO is a professional collaborative platform for embedded development. It has out-of-the-box support for ESP32 SoCs and allows working with Arduino ESP32 as well as ESP-IDF from Espressif without changing your development environment. PlatformIO includes lots of instruments for the most common development tasks such as debugging, unit testing, and static code analysis.

.. warning:: PlatformIO is not officially supported by Espressif. Please report any issues with PlatformIO directly to its developers on the official `PlatformIO repositories <https://github.com/platformio>`_.

A detailed overview of the PlatformIO ecosystem and its philosophy can be found in `the official documentation <https://docs.platformio.org/en/latest/core/index.html>`_.

PlatformIO can be used in two flavors:

- `PlatformIO IDE <https://platformio.org/platformio-ide>`_ is a toolset for embedded C/C++ development available on Windows, macOS and Linux platforms

- `PlatformIO Core (CLI) <https://docs.platformio.org/en/latest/core/index.html>`_ is a command-line tool that consists of a multi-platform build system, platform and library managers and other integration components. It can be used with a variety of code development environments and allows integration with cloud platforms and web services

To install PlatformIO, you can follow this Getting Started, provided at `docs.platformio.org`_.

Using the stable code
*********************

.. note::
   A detailed overview of supported development boards, examples and frameworks can be found on `the official Espressif32 dev-platform page <https://registry.platformio.org/platforms/platformio/espressif32>`_ in the PlatformIO Registry.

The most reliable and easiest way to get started is to use the latest stable version of the ESP32 development platform that passed all tests/verifications and can be used in production.

Create a new project and select one of the available boards. You can change after by changing the `platformio.ini <https://docs.platformio.org/en/latest/projectconf/index.html>`_ file.

- For ESP32

.. code-block:: bash

   [env:esp32dev]
   platform = espressif32
   board = esp32dev
   framework = arduino

- For ESP32-S2 (ESP32-S2-Saola-1 board)

.. code-block:: bash

   [env:esp32-s2-saola-1]
   platform = espressif32
   board = esp32-s2-saola-1
   framework = arduino

- For ESP32-C3 (ESP32-C3-DevKitM-1 board)

.. code-block:: bash

   [env:esp32-c3-devkitm-1]
   platform = espressif32
   board = esp32-c3-devkitm-1
   framework = arduino

How to update to the latest code
********************************

To test the latest Arduino ESP32, you need to change your project *platformio.ini* accordingly.
The following configuration uses the upstream version of the Espressif development platform and the latest Arduino core directly from the Espressif GitHub repository:

.. code-block:: bash

   [env:esp32-c3-devkitm-1]
   platform = https://github.com/platformio/platform-espressif32.git
   board = esp32-c3-devkitm-1
   framework = arduino
   platform_packages =
       framework-arduinoespressif32 @ https://github.com/espressif/arduino-esp32#master

To get more information about PlatformIO, see the following links:

- `PlatformIO Core (CLI) <https://docs.platformio.org/en/latest/core/index.html>`_

- `PlatformIO Home <https://docs.platformio.org/en/latest/home/index.html>`_

- `Tutorials and Examples <https://docs.platformio.org/en/latest/tutorials/index.html>`_

- `Library Management <https://docs.platformio.org/en/latest/librarymanager/index.html>`_

Windows (manual installation)
-----------------------------

.. warning:: Arduino ESP32 core v2.x.x cannot be used on Windows 8.x x86 (32 bits), Windows 7 or earlier. The Windows 32 bits OS is no longer supported by this toolchain.

   The Arduino ESP32 v1.0.6 still works on WIN32. You might want to install python 3.8.x because it is the latest release supported by Windows 7.

Steps to install Arduino ESP32 support on Windows:

**Step 1**

1. Download and install the latest Arduino IDE ``Windows Installer`` from [arduino.cc](https://www.arduino.cc/en/Main/Software)
2. Download and install Git from [git-scm.com](https://git-scm.com/download/win)
3. Start ``Git GUI`` and do the following steps:

- Select ``Clone Existing Repository``



- Select source and destination
   - Sketchbook Directory: Usually ``C:/Users/[YOUR_USER_NAME]/Documents/Arduino`` and is listed underneath the "Sketchbook location" in Arduino preferences.
   - Source Location: ``https://github.com/espressif/arduino-esp32.git``
   - Target Directory: ``[ARDUINO_SKETCHBOOK_DIR]/hardware/espressif/esp32``
   - Click ``Clone`` to start cloning the repository

**Step 2**



**Step 3**



- open a `Git Bash` session pointing to ``[ARDUINO_SKETCHBOOK_DIR]/hardware/espressif/esp32`` and execute ```git submodule update --init --recursive``` 
- Open ``[ARDUINO_SKETCHBOOK_DIR]/hardware/espressif/esp32/tools`` and double-click ``get.exe``

**Step 4**



- When ```get.exe``` finishes, you should see the following files in the directory

**Step 5**



1. Plug your ESP32 board and wait for the drivers to install (or install manually any that might be required)
2. Start Arduino IDE
3. Select your board in ``Tools > Board`` menu
4. Select the COM port that the board is attached to
5. Compile and upload (You might need to hold the boot button while uploading)



How to update to the latest code
********************************

1. Start ``Git GUI`` and you should see the repository under ``Open Recent Repository``. Click on it!



1. From menu ``Remote`` select ``Fetch from`` > ``origin``



1. Wait for git to pull any changes and close ``Git GUI``
2. Open ``[ARDUINO_SKETCHBOOK_DIR]/hardware/espressif/esp32/tools`` and double-click ``get.exe``



Linux
-----



Debian/Ubuntu
*************

- Install latest Arduino IDE from `arduino.cc`_.

- Open Terminal and execute the following command (copy -> paste and hit enter):

.. code-block:: bash

   sudo usermod -a -G dialout $USER && \
   sudo apt-get install git && \
   wget https://bootstrap.pypa.io/get-pip.py && \
   sudo python3 get-pip.py && \
   sudo pip3 install pyserial && \
   mkdir -p ~/Arduino/hardware/espressif && \
   cd ~/Arduino/hardware/espressif && \
   git clone https://github.com/espressif/arduino-esp32.git esp32 && \
   cd esp32/tools && \
   python3 get.py

- Restart Arduino IDE.

- If you have Arduino installed to ~/, modify the installation as follows, beginning at `mkdir -p ~/Arduino/hardware`:

.. code-block:: bash

   cd ~/Arduino/hardware
   mkdir -p espressif && \
   cd espressif && \
   git clone https://github.com/espressif/arduino-esp32.git esp32 && \
   cd esp32/tools && \
   python3 get.py

Fedora
******

- Install the latest Arduino IDE from `arduino.cc`_.

.. note::
   Command ``$ sudo dnf -y install arduino`` will most likely install an older release.

- Open Terminal and execute the following command (copy -> paste and hit enter):

.. code-block:: bash

   sudo usermod -a -G dialout $USER && \
   sudo dnf install git python3-pip python3-pyserial && \
   mkdir -p ~/Arduino/hardware/espressif && \
   cd ~/Arduino/hardware/espressif && \
   git clone https://github.com/espressif/arduino-esp32.git esp32 && \
   cd esp32/tools && \
   python get.py

- Restart Arduino IDE.

openSUSE
********

- Install the latest Arduino IDE from `arduino.cc`_.

- Open Terminal and execute the following command (copy -> paste and hit enter):

.. code-block:: bash

   sudo usermod -a -G dialout $USER && \
   if [ `python --version 2>&1 | grep '2.7' | wc -l` = "1" ]; then \
   sudo zypper install git python-pip python-pyserial; \
   else \
   sudo zypper install git python3-pip python3-pyserial; \
   fi && \
   mkdir -p ~/Arduino/hardware/espressif && \
   cd ~/Arduino/hardware/espressif && \
   git clone https://github.com/espressif/arduino-esp32.git esp32 && \
   cd esp32/tools && \
   python get.py

- Restart Arduino IDE.

macOS
-----

- Install the latest Arduino IDE from `arduino.cc`_.

- Open Terminal and execute the following command (copy -> paste and hit enter):

.. code-block:: bash

   mkdir -p ~/Documents/Arduino/hardware/espressif && \
   cd ~/Documents/Arduino/hardware/espressif && \
   git clone https://github.com/espressif/arduino-esp32.git esp32 && \
   cd esp32/tools && \
   python get.py 

Where ``~/Documents/Arduino`` represents your sketch book location as per "Arduino" > "Preferences" > "Sketchbook location" (in the IDE once started). Adjust the command above accordingly.

- If you get the error below, install through the command line dev tools with `xcode-select --install` and try the command above again:

.. code-block:: bash

   xcrun: error: invalid active developer path (/Library/Developer/CommandLineTools), missing xcrun at: /Library/Developer/CommandLineTools/usr/bin/xcrun

- Run the command:

.. code-block:: bash

   xcode-select --install

- Try ``python3`` instead of ``python`` if you get the error: ``IOError: [Errno socket error] [SSL: TLSV1_ALERT_PROTOCOL_VERSION] tlsv1 alert protocol version (_ssl.c:590)`` when running ``python get.py``

- If you get the following error when running ``python get.py`` urllib.error.URLError: <urlopen error SSL: CERTIFICATE_VERIFY_FAILED, go to Macintosh HD > Applications > Python3.6 folder (or any other python version), and run the following scripts: Install Certificates.command and Update Shell Profile.command

- Restart Arduino IDE.

.. _Arduino.cc: https://www.arduino.cc/en/Main/Software
.. _docs.platformio.org: https://docs.platformio.org/en/latest/integration/ide/pioide.html

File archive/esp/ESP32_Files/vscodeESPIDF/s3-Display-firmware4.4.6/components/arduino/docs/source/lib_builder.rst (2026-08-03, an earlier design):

###############
Library Builder
###############

About
-----

Espressif provides a `tool <https://github.com/espressif/esp32-arduino-lib-builder>`_ to simplify building your own compiled libraries for use in Arduino IDE (or your favorite IDE).

This tool can be used to change the project or a specific configuration according to your needs.

Installing
----------

To install the Library Builder into your environment, please, follow the instructions below.

- Clone the ESP32 Arduino lib builder:

.. code-block:: bash

    git clone https://github.com/espressif/esp32-arduino-lib-builder

- Go to the ``esp32-arduino-lib-builder`` folder:

.. code-block:: bash

    cd esp32-arduino-lib-builder

- Build:

.. code-block:: bash

    ./build.sh

If everything works, you may see the following message: ``Successfully created esp32 image.``

Dependencies
************

To build the library you will need to install some dependencies. Maybe you already have installed it, but it is a good idea to check before building.

- Install all dependencies (**Ubuntu**):

.. code-block:: bash

    sudo apt-get install git wget curl libssl-dev libncurses-dev flex bison gperf cmake ninja-build ccache jq

- Install Python and upgrade pip:

.. code-block:: bash

    sudo apt-get install python3
    sudo pip install --upgrade pip

- Install all required packages:

.. code-block:: bash

    pip install --user setuptools pyserial click cryptography future pyparsing pyelftools

Building
--------

If you have all the dependencies met, it is time to build the libraries.

To build using the default configuration:

.. code-block:: bash

    ./build.sh

Custom Build
************

There are some options to help you create custom libraries. You can use the following options:

Usage
^^^^^

.. code-block:: bash

    build.sh [-s] [-A arduino_branch] [-I idf_branch] [-i idf_commit] [-c path] [-t <target>] [-b <build|menuconfig|idf_libs|copy_bootloader|mem_variant>] [config ...]

Skip Install/Update
^^^^^^^^^^^^^^^^^^^

Skip installing/updating of ESP-IDF and all components

.. code-block:: bash

    ./build.sh -s

This option can be used if you already have the ESP-IDF and all components already in your environment.

Set Arduino-ESP32 Branch
^^^^^^^^^^^^^^^^^^^^^^^^

Set which branch of arduino-esp32 to be used for compilation

.. code-block:: bash

    ./build.sh -A <arduino_branch>

Set ESP-IDF Branch
^^^^^^^^^^^^^^^^^^

Set which branch of ESP-IDF is to be used for compilation

.. code-block:: bash

    ./build.sh -I <idf_branch>

Set the ESP-IDF Commit
^^^^^^^^^^^^^^^^^^^^^^

Set which commit of ESP-IDF to be used for compilation

.. code-block:: bash

    ./build.sh -i <idf_commit>

Deploy
^^^^^^

Deploy the build to github arduino-esp32

.. code-block:: bash

    ./build.sh -d

Set the Arduino-ESP32 Destination Folder
^^^^^^^^^^^^^^^^^^^^^^^^^^^^^^^^^^^^^^^^

Set the arduino-esp32 folder to copy the result to. ex. '$HOME/Arduino/hardware/espressif/esp32'

.. code-block:: bash

    ./build.sh -c <path>

This function is used to copy the compiled libraries to the Arduino folder.

Set the Target
^^^^^^^^^^^^^^

Set the build target(chip). ex. 'esp32s3'

.. code-block:: bash

    ./build.sh -t <target>

This build command will build for the ESP32-S3 target. You can specify other targets.

* esp32
* esp32s2
* esp32c3
* esp32s3

Set Build Type
^^^^^^^^^^^^^^

Set the build type. ex. 'build' to build the project and prepare for uploading to a board.

.. note:: This command depends on the ``-t`` argument.

.. code-block:: bash

    ./build.sh -t esp32 -b <build|menuconfig|idf_libs|copy_bootloader|mem_variant>

Additional Configuration
^^^^^^^^^^^^^^^^^^^^^^^^

Specify additional configs to be applied. ex. 'qio 80m' to compile for QIO Flash@80MHz. Requires -b

.. note:: This command requires the ``-b`` to work properly.

.. code-block:: bash

    ./build.sh -t esp32 -b idf_libs qio 80m

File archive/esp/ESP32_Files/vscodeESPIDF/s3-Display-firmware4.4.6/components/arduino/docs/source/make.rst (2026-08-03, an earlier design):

==============
makeEspArduino
==============

The `makeEspArduino <https://github.com/plerup/makeEspArduino>`_ is a generic makefile for any ESP8266/ESP32 Arduino project. 
Using it instead of the Arduino IDE makes it easier to do automated and production builds.

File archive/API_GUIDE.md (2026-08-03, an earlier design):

# Home Security API Guide

## 🚨 **IMPORTANT: Use Correct Backend Ports**

### **Cloud Backend (Port 3001)**
- ✅ `GET /status` - Health check
- ✅ `GET /api/events` - List events with thumbnails
- ✅ `GET /api/clips/:eventId` - Stream video clip from Google Drive
- ✅ `GET /api/clips/:eventId/thumbnail` - Stream thumbnail from Google Drive
- ✅ `POST /api/events/upload` - Upload files (Pi only)
- ✅ `DELETE /api/clear-all` - Clear database
- ❌ `POST /start` - Not available (use Pi backend)
- ❌ `POST /stop` - Not available (use Pi backend)
- ❌ `POST /motion` - Not available (use Pi backend)

### **Pi Backend (Port 4000)**
- ✅ `GET /health` - System status
- ✅ `POST /start` - Start stream
- ✅ `POST /stop` - Stop stream
- ✅ `POST /motion` - Trigger motion
- ✅ `DELETE /clear-all` - Clear local data

## 🎯 **Correct Usage Examples**

### **Stream Control (Pi Backend)**
```bash
# Start stream
curl -X POST http://localhost:4000/start \
  -H "Content-Type: application/json" \
  -d '{"type":"webcam","value":""}'

# Stop stream
curl -X POST http://localhost:4000/stop

# Trigger motion
curl -X POST http://localhost:4000/motion
```

### **Cloud Data (Cloud Backend)**
```bash
# Get events
curl http://localhost:3001/api/events

# Stream video clip (replace EVENT_ID with event._id from /api/events)
curl -O -J "http://localhost:3001/api/clips/EVENT_ID"

# Stream thumbnail (replace EVENT_ID with event._id)
curl -O -J "http://localhost:3001/api/clips/EVENT_ID/thumbnail"

# Clear database
curl -X DELETE http://localhost:3001/api/clear-all

# Health check
curl http://localhost:3001/status
```

## 📹 **Clip Serving (Cloud Backend)**

Clips are streamed from Google Drive through the cloud backend:

| Endpoint | Description |
|---|---|
| `GET /api/clips/:eventId` | Streams the video file (video/mp4). Use in `<video src="...">` or download. |
| `GET /api/clips/:eventId/thumbnail` | Streams the thumbnail image (image/jpeg). Use in `<img src="...">`. |

**Example frontend usage:**
```html
<video src="http://localhost:3001/api/clips/675abc123def456789" controls></video>
<img src="http://localhost:3001/api/clips/675abc123def456789/thumbnail" />
```

Replace `675abc123def456789` with the event's `_id` from `GET /api/events`.

## 🖥️ **Frontend Integration**

The frontend automatically routes requests correctly:
- `/api/*` → Pi backend (port 4000)
- `/cloud/*` → Cloud backend (port 3001)

## 🚨 **Common Mistakes to Avoid**

1. **❌ Wrong:** `curl -X POST http://localhost:3001/stop`
   **✅ Right:** `curl -X POST http://localhost:4000/stop`

2. **❌ Wrong:** `curl http://localhost:4000/api/events`
   **✅ Right:** `curl http://localhost:3001/api/events`

3. **❌ Wrong:** `curl -X DELETE http://localhost:4000/api/clear-all`
   **✅ Right:** `curl -X DELETE http://localhost:3001/api/clear-all`

## 🎯 **Quick Test Commands**

```bash
# Test Pi backend
curl http://localhost:4000/health

# Test cloud backend  
curl http://localhost:3001/status

# Trigger motion (full pipeline test)
curl -X POST http://localhost:4000/motion
sleep 5
curl http://localhost:3001/api/events

# Download a clip (get event ID from /api/events first)
curl -o clip.mp4 "http://localhost:3001/api/clips/YOUR_EVENT_ID"
```

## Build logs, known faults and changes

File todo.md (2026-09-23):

# Home Security System — Implementation TODO

Companion to `architecture.md`. This is an *ordering* document — it tells you what to do first, second, third, and why, based on what blocks what. Section references (§N) point to `architecture.md`.

**Rule of thumb used throughout: resolve a design decision before writing code against it.** Several phases below start with "decide X" specifically because building against an undecided spec is the fastest way to end up rewriting firmware.

---

## Phase 0 — Close the remaining blocking decisions

Nothing in Phase 1+ should start until these are answered — they change API shapes, hardware BOM, and firmware structure, so getting them late is expensive.

- [ ] **§16 — Pi↔S3 transport.** Pick static IP / mDNS / hybrid. This is the single highest-priority open item in the doc (§22 #1) and blocks: PSK backup, the PIN-set flow, and the entire motion-alert pipeline.

- [ ] **§9/§20 — does arm/disarm state reach individual sensors, or is gating centralized?** Answer before finalizing the UART command set (§9) or sensor firmware's power model. (§22 #2)

- [ ] **§13 — PSK backup auth.** Confirm whether the planned "paired device token" also authenticates the PSK backup push, or if that needs its own scheme. (§22 #3)

- [ ] **Re-provisioning vs. factory reset UX** — explicitly deferred (TBD) in the doc; fine to punt, but note it so nobody assumes it's designed. (§22 #4)

**Exit criteria for Phase 0:** §16's transport is chosen and written up, and the sensor arm-state question has an answer. Everything else in Phase 0 can trail into Phase 1 without blocking hardware work.

---

## Phase 1 — ESP32 firmware: provisioning core

Build the part of the system that has zero external dependencies (no Pi, no app, no cloud) — just the two console-side ESP32s talking to each other and to a phone.

1. [x] Implement the UART frame format (§9): `SYNC | CMD | LEN | PAYLOAD | CRC`. Write this before any of the commands that use it — get framing, checksum validation, and buffer-split handling solid first, since a bug here silently corrupts every message type built on top of it.
   - [ ] **Bug fix — sync byte mismatch.** `app_uart.cpp` currently matches `'c'`/`'8'` (0x63/0x38, printable ASCII) instead of the spec'd `0xAA 0x55` (§9, D16). ASCII sync bytes risk false-locking mid-payload during resync (e.g. an SSID or password containing `c8`). Fix both WROOM sender and S3 receiver together — flash as a pair, don't roll one side ahead.

2. [ ] Implement the confirmed command set (§9): home WiFi creds, connection result, sensor event relay, status/heartbeat. Leave the two Phase-0-dependent commands (motion-relay tagging, arm/disarm-to-sensor) until Phase 0 lands.
   - [x] `MOBILE_PAIRING` — cmd_s enum, dispatch switch, frame send/receive with CMD param, async response queue (esp2)
   - [x] `CONNECTION_RESULT` — S3 → WROOM WiFi join ack
     - [ ] **Bug fix — false-success on DHCP failure.** Currently signals on `WIFI_EVENT_STA_CONNECTED` (association only, not addressable). Move to `IP_EVENT_STA_GOT_IP`. Bump `pair.cpp` timeout 5000ms → 9000ms to keep DHCP in budget (§4 step 5, updated).
     - [ ] **Bug fix — stale queue entry.** `xQueueSend` from a timed-out attempt can land after the timeout already fired, and get consumed as a false "success" by the *next* attempt. Add `xQueueReset(wait_for_wifi_to_connect)` at the top of `wifi_start()`.
     - [ ] **Bug fix — uninitialized `received`.** `pair.cpp`'s local `bool received` is read after `xQueueReceive` without being initialized first; on timeout the buffer is untouched and the value is garbage. Initialize to `false`.
     - [ ] Confirm `esp_wifi_connect()`'s return in the `STA_DISCONNECTED` handler is intentionally discarded when `wifi_start()`'s `esp_wifi_stop()` triggers a spurious disconnect event (`ESP_ERR_WIFI_NOT_STARTED`) — not asserted on.
   - [ ] `SENSOR_EVENT` — WROOM → S3 ongoing telemetry
   - [ ] `STATUS_HEARTBEAT` — S3 → WROOM liveness ping

3. [ ] **Currently: hardcoded shared default, not batch- or MAC-derived (§6, confirmed).** All units ship with the same fixed setup AP credentials — this is the MVP-fallback end of the spectrum, not yet even batch-unique. Per-unit derivation (`HMAC(batch_secret, MAC_address)`) is tracked as a planned item, not yet started (§22 #12). Label/QR generation pipeline (Phase 10) is blocked on this — nothing unit-specific to print yet.

4. [ ] Implement the console provisioning flow end-to-end (§4): phone → WROOM setup AP → UART → S3 → home WiFi join → PSK generation → PSK back to phone.
   - [x] Steps 1–6 implemented (WiFi creds relay, S3 join attempt, connection result relay) — see bug fixes under step 2 above; flow works but currently reports false positives on DHCP failure until those land.
   - [x] PSK generation — confirmed 32-char alphanumeric via `esp_random()` (§7, updated from ~20-char).
   - [x] SSID — confirmed static (`"espwifi"`), not MAC-derived (§4 step 7, §2). Not a spec defect; MAC-derivation is a planned item (§22 #6), not a blocking requirement.
   - [ ] **Known gap — step 8 AP transition commented out.** WROOM's setup-AP-close / transition-to-hub-only-mode is currently disabled in firmware for debugging (setup AP stays live post-pairing so traffic can be inspected without reflashing). Must be re-enabled before this leaves dev — track explicitly, don't let it slip into a release build silently.
   - [ ] Step 9 (WROOM → S3 → Pi PSK backup) — blocked on §16 (Phase 4).

5. [ ] Implement failure handling (§8) — **spec simplified since last revision: binary outcome only.** S3 reports `wifiConnection: true`/`false` over UART, no reason code surfaced to WROOM/phone/app. Simpler build than originally scoped:
   - [ ] No reason-code UX needed — drop that from scope.
   - [ ] No retry cap / no physical-button re-entry needed for this flow specifically — S3's `esp_wifi_connect()` retry loop runs indefinitely by design; the phone already has `false` and can re-trigger. (Retry-cap-then-button-reentry pattern still applies elsewhere, e.g. §12 sensor reconnect — don't conflate the two.)
   - [ ] Confirm `last_disconnect_reason` (captured in the `STA_DISCONNECTED` handler) is stored but deliberately not wired to any UART command or app-facing behavior — leave the hook in place for future use, no further work needed now.

6. [ ] Implement credential storage per §7's table exactly: home WiFi creds and disarm PIN both live in S3 NVS only; sensor PSK and `sensor_key`s live in WROOM NVS. Double-check nothing leaks into the wrong device's flash. Note PSK is now 32 chars — confirm NVS value size accommodates this (32-char ASCII well within any reasonable NVS blob/string limit, but verify no fixed-width buffer elsewhere assumes the old ~20-char length).

**Test against:** the pairing/provisioning steps in §4 and the failure table in §8, manually, before writing any automated test harness — you want to feel the actual UX friction first. Re-run this pass after the bug fixes above land, not just once at the end.

---

## Phase 2 — Sensor pairing and network

1. [ ] Implement sensor-side setup AP with the same per-unit credential derivation as Phase 1 step 3. **Note:** Phase 1 step 3 is currently hardcoded/shared, not per-unit — build sensor-side setup AP against whatever Phase 1 step 3 actually ships with at the time, not the eventual per-unit-derived target, to avoid rework churn.

2. [ ] Implement the pairing flow (§5): phone → sensor setup AP → SSID+PSK handoff → sensor joins WROOM AP as station → `sensor_key` handshake → WROOM marks paired.

3. [ ] Implement the 10-sensor SoftAP cap check and the "AP at capacity" UX prompt (§5, §22 #8 — UX detail still open, but the cap check itself isn't).

4. [ ] Implement reboot/reconnect behavior (§12): WROOM NVS-persisted AP credentials on reboot, sensor MAC-based reconnect with exponential backoff, **no AP-mode fallback** — this last one is a deliberate security decision (D12), don't "fix" it later without revisiting that call.

5. [ ] Implement the bounded sensor-event buffer on the WROOM (§12) — cap it, drop-oldest on overflow, and actually test the overflow path, not just the happy path.

**Test against:** pair 10 sensors, reboot the console mid-operation, reboot a sensor mid-operation, and confirm no sensor requires re-pairing after either reboot.

---

## Phase 3 — Pi baseline (SoftAP shipping; hub barebones in tree)

Per D20 / README §13: SoftAP is the boot gate; `pi_hub` is one Flask process after home Wi‑Fi (live + clips + Drive stubs). Old Node `rasberry_pi_app` is **not** the product path.

- [x] SoftAP wizard + static IP + boot handoff → `pi_hub` (`rasberry-pi-setup/`)
- [ ] Confirm the Pi setup flow matches §13's test protocol — run it fresh after deploy.
- [ ] Confirm Pi initializes **before** console provisioning in the app onboarding UI (§4, §13).
- [ ] Implement Tailscale install/pairing instructions and verify MagicDNS/`100.x` (§13 test 13.4).
- [ ] Fill in real ffmpeg HLS (`pi_hub.live`) and Drive upload (`pi_hub.drive`) — stubs exist.
- [ ] Build the "paired device token" API auth (§13 step 6) — dependency for PSK-backup-auth.

---

## Phase 4 — Pi ↔ S3 link (the big one)

This is gated entirely on Phase 0's transport decision. Once that's made:

1. [ ] Implement the chosen discovery/transport mechanism (§16).

2. [ ] Implement auth on this link — reuse the Phase 3 paired-device-token mechanism rather than building a second scheme (§16, §22 #1).

3. [ ] Implement the PIN-set flow (§20): `Phone App → Pi → Console S3`, PIN stored in S3 NVS, acknowledgment back through the same path.

4. [ ] Implement the motion-alert relay: `Sensor → WROOM → S3 (UART) → Pi (§16) → FCM/ntfy` (§19, §20).

5. [ ] Implement the PSK backup push: WROOM generates PSK → UART to S3 → S3 pushes to Pi (§11) — note the direction, S3 is the only thing that can reach the Pi, not the WROOM. PSK is now 32 chars — no transport impact, just noting for anyone sizing payloads against the old ~20-char figure.

6. [ ] **Latency-test the full alert chain end to end against the ≤15s budget (§14, §16)** before considering this phase done. Test each hop's latency individually too — if the budget is blown, you need to know which hop is the problem, not just that the total is over. Factor in the Phase 1 WiFi-join timeout change (5s→9s) if it's ever relevant to a hop here — it isn't directly (that's provisioning-time, not runtime), but worth a sanity check that no runtime path accidentally reuses that constant.

**This phase is also where the Phase 0 sensor-arm-state decision gets implemented** — whichever answer you picked (sensor-side gating vs. centralized gating at the S3/Pi) gets built here.

---

## Phase 5 — Arm / disarm

Can start in parallel with Phase 4 once the PIN-set flow (Phase 4 step 3) exists, since disarm validation depends on the PIN already being in S3 NVS.

1. [ ] Implement console keypad hardware + firmware input handling (§2, §20).

2. [ ] Implement local PIN validation on the S3 (§20) — confirmed to be fast/local, not round-tripped through the Pi.

3. [ ] Implement arm (no PIN) and disarm (PIN required) from both the app and the console (§20).

4. [ ] Implement the app-side arm/disarm UI, wired through the Pi to the S3 via the Phase 4 link.

5. [ ] Confirm no entry/exit delay is implemented anywhere (§20) — i.e., don't accidentally build a grace-period feature nobody asked for.

6. [ ] Confirm disarmed-state sensors produce **no relay and no logging** (§20) — test this explicitly, since "no logging" is an easy thing to get wrong by default (most systems log everything unless told not to).

---

## Phase 6 — Alerts (FCM / ntfy)

Mostly Storyboard-side work; cross-check against §14.

- [ ] Android: Firebase project, `google-services.json`, `expo-notifications` in a dev/prod build (**not** Expo Go — confirmed unreliable, D-level decision).

- [ ] iOS: generate and store the high-entropy ntfy.sh topic; surface it once in app Settings; document the ntfy iOS app subscribe step for v1.

- [ ] Wire both to the Phase 4 motion-relay pipeline.

- [ ] Test against §14's failure modes explicitly (revoked FCM token, notifications disabled in OS, topic never subscribed) — these are easy to skip in a happy-path demo and then discover in the field.

---

## Phase 7 — Live view (Tailscale)

- [ ] Implement Pi-side HLS streaming endpoint (if not already built) and app-side player.

- [ ] Implement Pi base URL resolution: Tailscale host when off-LAN, saved LAN IP otherwise (§15).

- [ ] Implement stream start/stop tied to the Live screen's foreground/background state — confirm no persistent streaming when the app isn't actively open (§15, D5's "no persistent connection" principle applies here too).

- [ ] Test the Tailscale-off failure mode explicitly (§15 test 4.4) — clear error, not an infinite spinner.

---

## Phase 8 — Clips (Drive)

- [ ] Implement Google OAuth in the app (`access_type=offline`, `drive.file` scope) and the token handoff to the Pi (§18) — LAN/Tailscale only. **Phone guide:** `DOCUMENTATION.md`. Pi already stores the token encrypted and uploads.

- [x] Implement Pi-side cache-then-upload pipeline (§17). `pi_hub/drive.py` uploads to a `SentriHome` folder once `/auth/drive` has credentials.

- [ ] Implement app-side clip listing/playback directly from Drive (not via Tailscale — confirmed this path must work on cellular with Tailscale off).

- [ ] Implement revoke/re-auth UX for when uploads start failing loudly (§17, §18).

- [ ] **Decide and implement clip retention policy** (§22 #9 — currently unspecified) before this ships, or the Pi's local storage will fill up silently.

---

## Phase 9 — Integration testing

Run these only after Phases 1–8 are individually working — this phase is about the seams between them, not re-testing each phase in isolation.

- [ ] Full onboarding: unbox → Pi setup → console setup → sensor pairing → arm → trigger a sensor → confirm push notification lands within budget → disarm via app → disarm via console keypad.

- [ ] Full outage scenarios: kill the Pi mid-operation (does the console still locally disarm via keypad? per §20, it should), kill home internet (per §22 #11, this is an **undesigned** gap — expect this test to fail until that item is picked up), kill Tailscale while away (live should fail cleanly, clips should still work).

- [ ] Multi-sensor stress: pair all 10 sensors, trigger several in quick succession, confirm the WROOM's bounded event buffer (§12) doesn't drop or corrupt anything under load.

- [ ] Reboot matrix: reboot each device (Pi, S3, WROOM, individual sensors) independently and in combination, confirm the system recovers per §12's documented behavior in each case.

- [ ] Re-run provisioning against §8's simplified binary-outcome spec — confirm the app handles a bare `true`/`false` cleanly with no leftover reason-code UI expecting data that will never arrive.

---

## Phase 10 — Manufacturing / physical

Can run in parallel with software phases once Phase 1 step 3's credential derivation is finalized — this doesn't block or get blocked by most software work, but needs to be ready before the first physical batch ships.

**Currently blocked:** Phase 1 step 3 is still shipping hardcoded shared credentials (§6, §22 #12), so there's no per-unit value yet to put on a label/QR. This phase can't meaningfully start until that lands.

- [ ] Label/QR printing pipeline for setup AP credentials — confirm it's placed inside packaging or under a peel-back sticker, never on the outer box (§23).

- [ ] Enclosure design sign-off confirming the UART lines aren't exposed via any accessible debug header (§23) — this is a stated trust assumption in the security model (D18), not just a nice-to-have.

- [ ] Confirm keypad hardware spec (§2, §20) — including whether it has any dedicated audio output, since that's still a small open question even though no beep hardware is planned for v1.

---

## Explicitly not in this TODO (post-launch roadmap — §21)

Don't let these creep into v1 scope:

- Bluetooth speaker pairing as a local siren
- ~~Camera-based motion detection~~ — **shipped early**, ahead of this roadmap:
  `pi_hub.detect` runs MobileNet-SSD over OpenCV DNN on the shared MediaMTX RTSP
  feed and raises person-gated events through `pi_hub.events`. It does not replace
  the PIR sensor path (§19) — the two are independent triggers into the same clip
  pipeline. See `rasberry-pi-setup/PI-SOFTAP-README.md`.
- Partial/zone arming ("stay" vs. "away" modes)
- Auto-arm/auto-disarm via schedule or geofencing
- OTA update mechanism (§22 #7 — needed before wide field deployment, but not for a first working unit)

---

## Known gaps this TODO can't resolve for you

These are documented as open in `architecture.md` §22 and don't have an implementation path yet because the design isn't finished:

- Internet-outage alert fallback (item 11) — if home internet is down, there is currently **no alert path at all**. Worth deciding whether this blocks v1 launch or ships as a known limitation.
- Tamper detection, multi-user/multi-phone pairing, general event history/log, full Pi API auth coverage (item 11) — none of these have a phase above because none have a design yet. Route them through Phase 0-style design work before they get their own implementation phase.
- Per-unit setup AP credential derivation (item 12) and per-unit/MAC-derived SSID (item 6) — both confirmed planned, not started; Phase 1 step 3 and Phase 10 are blocked on the former specifically.

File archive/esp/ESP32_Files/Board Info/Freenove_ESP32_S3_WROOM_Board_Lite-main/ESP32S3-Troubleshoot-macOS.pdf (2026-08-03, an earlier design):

## CH34x Driver Installation on macOS

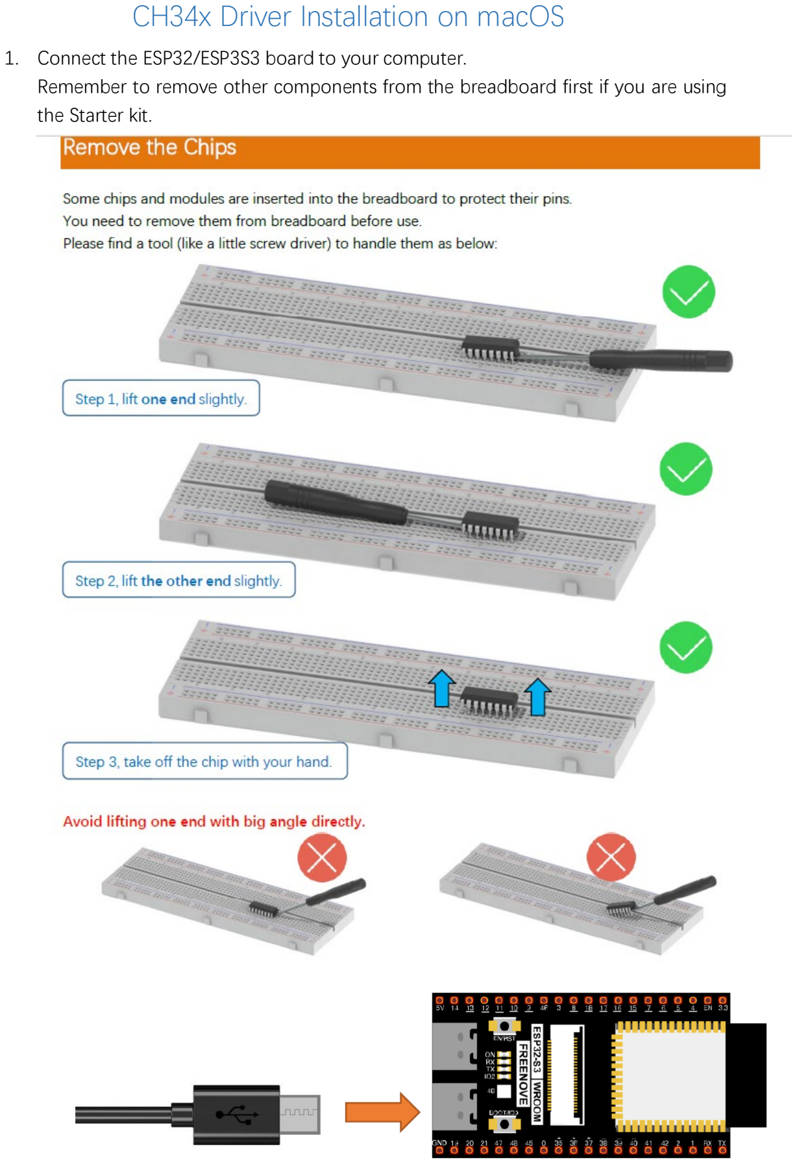
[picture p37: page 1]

1. Connect the ESP32/ESP3S3 board to your computer.
Remember to remove other components from the breadboard first if you are using the Starter kit.

2. Download the ch34x driver from WCH official. https://www.wch-ic.com/downloads/CH34XSER_MAC_ZIP.html
3. Open the CH34xVCPDriver.pkg to install the driver.

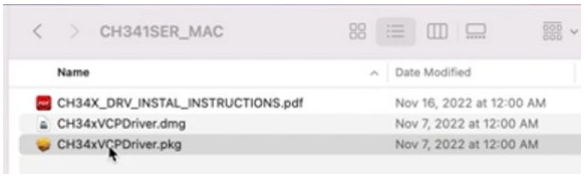
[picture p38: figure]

If it is blocked, please open Security Preferences to allow it.

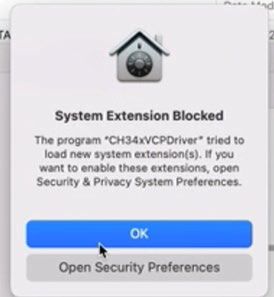
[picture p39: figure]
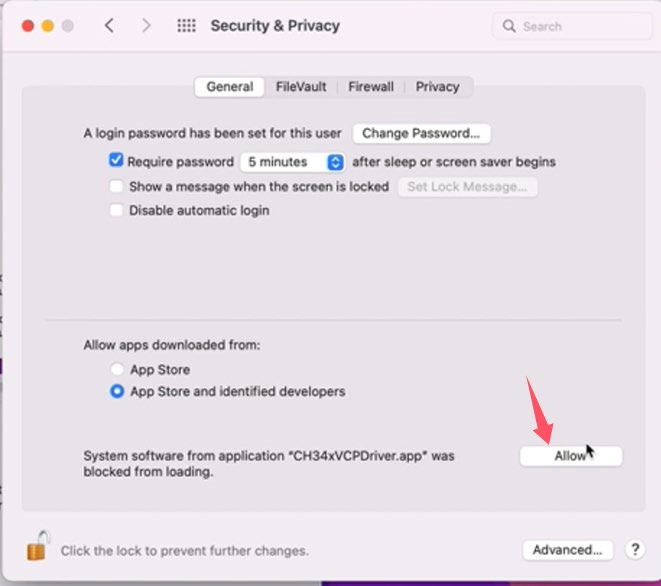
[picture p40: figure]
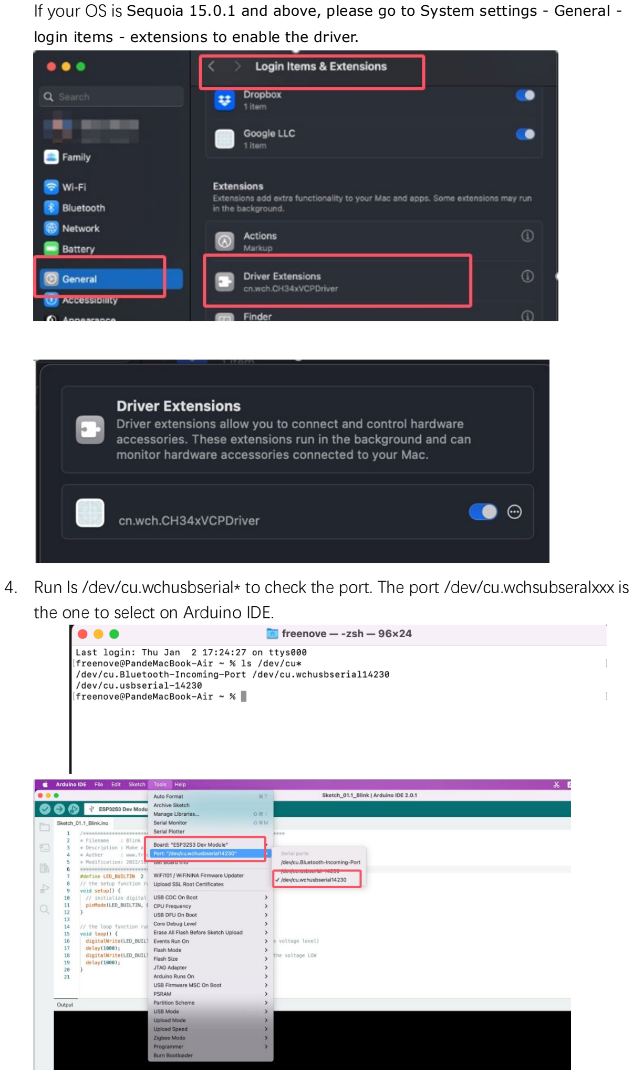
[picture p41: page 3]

If your OS is Sequoia 15.0.1 and above, please go to System settings - General -login items - extensions to enable the driver.

4. Run ls /dev/cu.wchusbserial* to check the port. The port /dev/cu.wchsubseralxxx is the one to select on Arduino IDE.

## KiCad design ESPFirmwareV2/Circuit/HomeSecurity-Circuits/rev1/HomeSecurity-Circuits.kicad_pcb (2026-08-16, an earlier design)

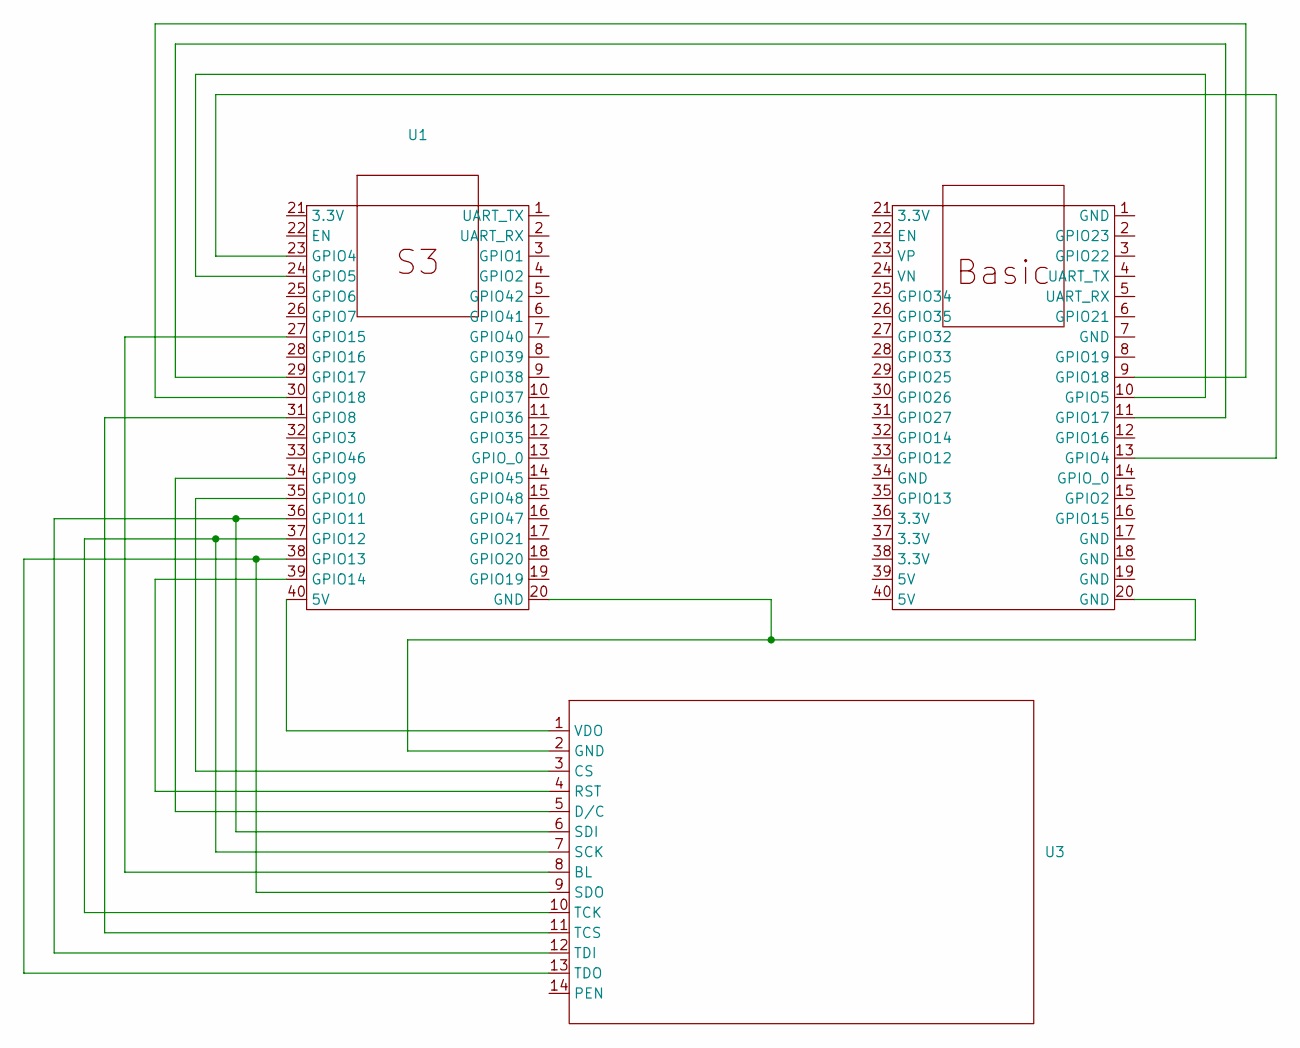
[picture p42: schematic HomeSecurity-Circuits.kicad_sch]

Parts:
U1, U2: esp32wroom
U3: ili9488

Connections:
unnamed: U1.40 (5V), U3.1 (VDO)
unnamed: U1.20 (GND), U2.20 (GND), U3.2 (GND)
unnamed: U1.23 (GPIO4), U2.13 (GPIO4)
unnamed: U1.24 (GPIO5), U2.10 (GPIO5)
unnamed: U1.31 (GPIO8), U3.11 (TCS)
unnamed: U1.34 (GPIO9), U3.5 (D/C)
unnamed: U1.35 (GPIO10), U3.3 (CS)
unnamed: U1.36 (GPIO11), U3.6 (SDI), U3.12 (TDI)
unnamed: U1.37 (GPIO12), U3.7 (SCK), U3.10 (TCK)
unnamed: U1.38 (GPIO13), U3.9 (SDO), U3.13 (TDO)
unnamed: U1.39 (GPIO14), U3.4 (RST)
unnamed: U1.27 (GPIO15), U3.8 (BL)
unnamed: U1.29 (GPIO17), U2.11 (GPIO17)
unnamed: U1.30 (GPIO18), U2.9 (GPIO18)

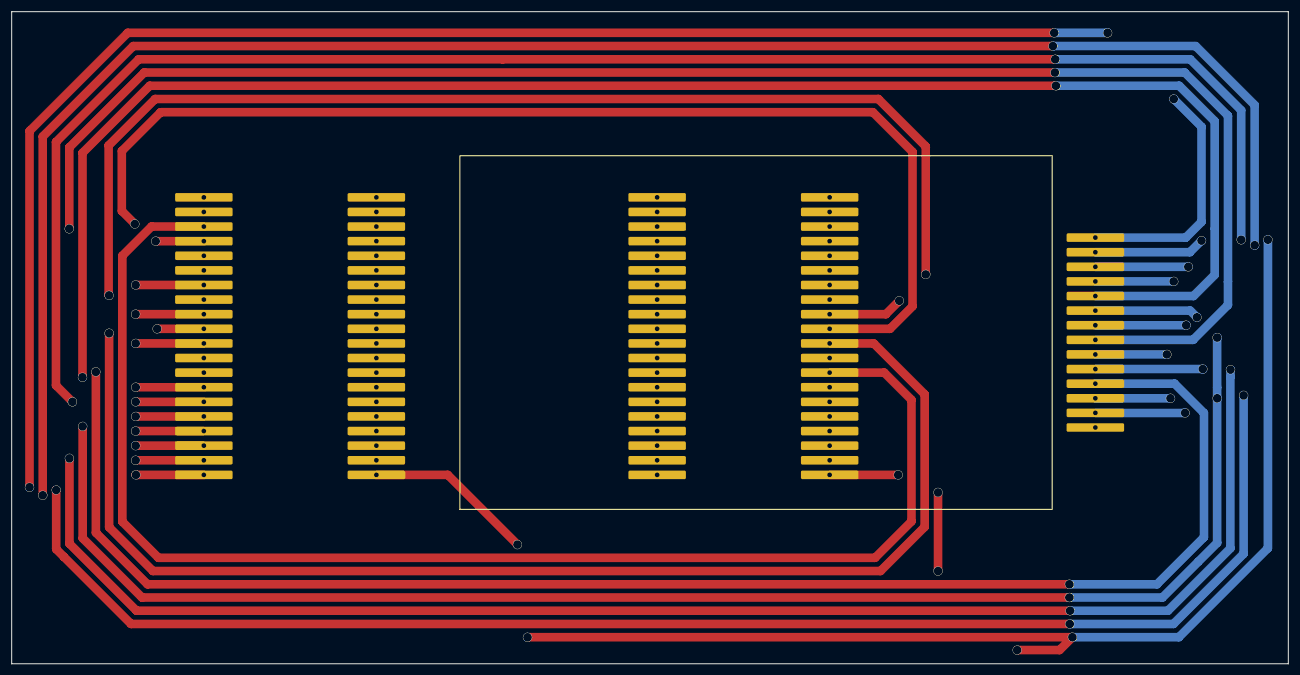
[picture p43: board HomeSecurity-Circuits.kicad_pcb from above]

Board: 4 copper layers, 222.0 x 113.4 mm, 3 parts (0 on the bottom side), 14 nets.

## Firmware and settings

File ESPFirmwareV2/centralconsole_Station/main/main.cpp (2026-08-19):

#include "display.h"
#include "connectivity.h"
#include "app_uart.h"
#include "storage.h"
#include "keypad.h"

// void setup(){
//   Serial.begin(115200);
//   display.init();
//   delay(10);
//   wifi_start();
// }

// void loop(){
//   display.process();
//   delay(200);
// }

void display_task(void *arg)
{
  for (;;)
  {
    display.init();
    display.process();
    vTaskDelay(pdMS_TO_TICKS(20));
  }
}

void uart_task(void *arg)
{
  for (;;)
  {
    uart.receive();
    vTaskDelay(pdMS_TO_TICKS(20));
  }
}

void keypad_task(void *arg)
{
  for (;;)
  {
    keypad.process();
    vTaskDelay(pdMS_TO_TICKS(20));
  }
}

void debounce_task(void *arg)
{
  for (;;)
  {
    keypad.debounce();
    vTaskDelay(pdMS_TO_TICKS(25));
  }
}

extern "C" void app_main(void)
{
  initArduino();
  Serial.begin(115200);
  delay(10);
  wait_for_wifi_to_connect = xQueueCreate(1, sizeof(bool));

  // nvs_flash_erase();

  storage.init();
  wifi_init();
  wifi_start(storage.read("ssid"), storage.read("pass"));
  uart.init();
  keypad.init();

  xTaskCreate(display_task, "display_task", 4096, NULL, 2, NULL);
  xTaskCreate(uart_task, "uart_task", 4096, NULL, 2, NULL);
  xTaskCreate(keypad_task, "keypad_task", 4096, NULL, 2, NULL);
  xTaskCreate(debounce_task, "debounce_task", 4096, NULL, 2, NULL);

}

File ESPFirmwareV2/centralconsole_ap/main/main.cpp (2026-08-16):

#include "Arduino.h"
#include "httpendpoints.h"
#include "connectivity.h"
#include "app_uart.h"
#include "jsonhandler.h"

extern "C" void app_main(void)
{
    initArduino();
    Serial.begin(115200);
    delay(10);
    wifi_init();
    endpoint_init();
    uart.init();
    ap_start("espwifi", "23012003");


    while (true)
    {
        delay(100);
        uart.receive();
    }
}

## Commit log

2026-02-23 Hackathon Completion
    [partitions.csv]
2026-03-25 Reinitialize Central Console firmware development
    [.uncrustify.cfg, anti_rollback_partition.csv, app3M_fat9M_16MB.csv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]
2026-03-25 Screen component
    [Configuring options.txt]
2026-06-05 3d obj files
    [Enclosure.obj, Front Plate.obj]
2026-06-18 Codebase transition to ESPIDF
    [partitions.csv]
2026-06-29 Revise Wifi driver and solve reconnection issue
    [main.cpp]
2026-07-08 Added status updates on startup on display, fixed startup startup comments showing on the ui
    [main.cpp]
2026-07-09 Parsing and data receive corruption fix
    [httpendpoints.cpp]
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2026-07-28 UART and Separation of devices configured
    [Untitled-B_Cu.dxf, Untitled-B_Mask.dxf, Untitled-B_Paste.dxf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]
2026-07-29 Fixed Wireless LAN automation in Pi Device
2026-07-30 refactor: restructure central console firmware and document project
    - Fix UART buffer overflow in uart_receive() by reserving space for null terminator
    - Update README.md with full wiring diagram, module architecture, build instructions, and development timeline
    - Add CLAUDE.md with project overview, coding conventions, and known limitations
    - Restructure httpendpoints into separate module files
    [app_uart.cpp, main.cpp]
2026-07-30 feat(http): add 6 configuration endpoints relay to UART + docs
    Endpoints:
    POST /ssid receive WiFi SSID
    POST /permanentpass receive permanent pass
    POST /encryptedpass receive encrypted password
    POST /otp receive OTP
    POST /schedule set schedule start (via schedulestart param)
    POST /schedule set schedule stop (via schedulestop param)
    All endpoints follow the same pattern: extract query parameter from HTTP
    body, log to printf, forward to UART1 via uart_send(), return JSON ack.
    Minor: rename api_pass_resp response text to permanent pass received.
    Docs:
    Replace stock ESP-IDF template README with esp2-specific docs
    Add CLAUDE.md (project overview, bui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
    [httpendpoints.cpp]
2026-08-01 feat: add ESP firmware flasher web app
    Next.js 16 app for flashing ESP32 devices via Web Serial and downloading firmware.
    Core:
    - App router layout with theme provider and Web Serial support detection
    - API routes for firmware download, download initialization, and latest version checks
    - Firmware manifest and Python helper scripts for firmware management
    UI:
    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
2026-08-01 fix: resolve dev server hang, hydration errors, and theme provider incompatibility
    - Use --webpack flag in dev script to avoid Turbopack hanging on @base-ui/react
    - Replace next-themes with custom context-based theme provider to avoid
    <script> injection blocked by Next.js 16 SSR
    - Set initial theme via className on <html> instead of theme provider props
    - Fix localStorage polyfill check for Next.js 16 dev server (getItem is
    not a function on the polyfilled object)
    - Add suppressHydrationWarning to Card root to prevent hydration mismatch
    errors from conditional Alert/Card rendering
    - Add /downloads/ to .gitignore
    - Update import paths for useTheme across header.tsx
    - Minor import fixes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
2026-08-03 feat(http): consolidate endpoints into single /pair with JSON parsing
    - Replace 7 individual POST endpoints (/pass, /ssid, /permanentpass,
    /encryptedpass, /otp, /schedule) with a single /pair endpoint
    - Add cJSON dependency and jsonhandler module for JSON body parsing
    - Increase request buffer from 50 to 1000 bytes for JSON payloads
    - Increase HTTP server stack size to 8192
    - Reduce main loop delay from 2s to 100ms for faster UART polling
    - Document co-located Next.js web app and update partition table
    [httpendpoints.cpp, main.cpp]
2026-08-03 docs: expand CLAUDE.md with cross-project architecture, update partitions and IDE config
    - Rewrite CLAUDE.md to document both the ESP firmware and Next.js web app
    as co-located projects, with architecture diagrams, module map, wiring
    summary, global state, IDE config, and known limitations
    - Add build configuration section to README.md (flash size, TFT pins,
    touch, partition table overrides)
    - Update partitions.csv: change factory size from 2M to 0x1F0000 to
    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
    [partitions.csv]
2026-08-03 refactor(uart): OOP restructuring, remove HTTP endpoints, add JSON parsing
    centralconsole_reboot:
    - Refactor uart module into uart_s/pair_s structs with OOP methods
    - Add JSON field parsing in pair_s::receive() (SSID, pass, schedule, RPi IP)
    - Fix UART TX/RX pin order (18/17)
    - Remove httpendpoints.cpp/h (health and pass endpoints)
    - Add cjson dependency to idf_component.yml
    - Update USB port to tty.usbmodem101
    - Update component lock hashes (dl_fft, esp-sr, esp_modem, libsodium)
    centralconsole_reboot_esp2:
    - Apply same uart OOP restructuring (uart_s/pair_s structs)
    - Add schedule/start, schedule/stop, raspberrypiip parsing to /pair endpoint
    - Relay pairing data via UART and await S3 confir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
    [app_uart.cpp, httpendpoints.cpp, main.cpp]
2026-08-04 Implement UART frame format (SYNC|CMD|LEN|PAYLOAD|CRC) for both consoles
    - Build complete frames in send() with 2B sync, 1B cmd, 2B big-endian
    length, and 2B CRC (cmd + 2*len)
    - Parse and validate incoming frames in receive(): sync marker search,
    header extraction, CRC check, payload extraction
    - Use std::string for send() to avoid null-termination issues with
    binary payload data
    - Add hex dump debug prints at each parse stage for both TX and RX
    - Fix null terminator placement in receive() (after received bytes,
    not always at buffer end)
    - Reduce receive buffer from 1000 to 200 bytes, vTaskDelay from 1000
    to 100ms
    - Add #pragma once and include guards to app_uart.h
    TODO: buffer-sp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
    [app_uart.cpp]
2026-08-04 Implement UART command dispatch with queue-based S3 response handling
    - Remove pair_s struct, consolidate UART logic into uart_s
    - Add cmd_s enum class for command type identification (MOBILE_PAIRING)
    - Add command dispatch in uart_s::receive() — switch on received CMD
    - Replace polling loop in /pair endpoint with FreeRTOS queue (waitfors3)
    for async S3 confirmation response
    - Fix send() to accept cmd_s parameter and cast correctly to int for CRC
    - Add waitfors3 queue creation in both main and endpoint_init
    - Remove vTaskDelay from send() — no longer needed
    - Call uart.receive() in main loop for command dispatch
    [app_uart.cpp, httpendpoints.cpp, main.cpp]
2026-08-04 Implement UART command dispatch and add cmd_s enum
    - Update pair_s::send() / uart_s::send() to accept cmd_s parameter
    - Use static_cast<int>(cmd) for CRC calculation and CMD byte in frame
    - Add command dispatch switch in receive() — dispatches MOBILE_PAIRING,
    logs unknown CMDs
    - esp2: queue payload to waitfors3 for async HTTP handler response
    - Remove vTaskDelay from send() in centralconsole_reboot
    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
2026-08-04 Update todo.md with UART buffer-split handling note
    Added notes on buffer-split handling for UART frame format implementation.
2026-08-12 backup pcb 2
    [Untitled.kicad_pcb]
2026-08-12 Schematic and PCB layout
    [HomeSecurity-Circuits.kicad_pcb, HomeSecurity-Circuits.kicad_sch, Untitled-B_Cu.dxf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]
2026-08-12 Added 3d model tracking
    [ESPClampScrew.step, ESPsocket.step, ESPsocketMount.step]
2026-08-12 models update, and add lcd adapter
    [ESPClampScrew.step, ESPsocket.step, ESPsocketMount.step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]
2026-08-13 Print V1
    [UART + Display layout_UART + Display layout v8_Body12.stl, UART + Display layout_UART + Display layout v8_Body14.stl, UART + Display layout_UART + Display layo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]
2026-08-13 feat: add WiFi connection result round-trip and NVS storage
    Station firmware:
    - Add storage module (NVS wrapper) for persistent credential storage
    - Add WiFi connection status tracking via FreeRTOS queue
    - S3 reports connection result to WROOM after pairing response
    - Update runtime flow, module map, and wiring docs
    AP firmware:
    - Parse and relay S3 connection result in /pair handler
    - Fix CRC command byte sign-extension (char -> uint8_t)
    - Increase queue receive timeout to 6s
    - Fix else-if chain for connection result handling
    Both firmwares:
    - Fix CRC sign-extension bug (char -> uint8_t for command byte)
    - Update CLAUDE.md with read all files first instruction
    - Update README.md wi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
    [app_uart.cpp, httpendpoints.cpp, main.cpp]
2026-08-14 fix: use pdMS_TO_TICKS for UART timeout, add vTaskDelay to main loop
    - Replace raw integer 100 with pdMS_TO_TICKS(100) in uart_read_bytes
    - Add vTaskDelay(10) to main loop to yield FreeRTOS task
    - Update VSCode COM ports: Station 101→1101, AP 110→10
    - Rename KiCad footprint library customespfootprint → HomeSecurity-Proj
    - Rewrite CLAUDE.md (Station) with structured docs and debugging discipline
    - Delete CLAUDE.md (AP)
    [HomeSecurity-Circuits.kicad_sch]
2026-08-15 initilizing changes till now
    [(Unsaved)_(Unsaved)_Body1.stl, (Unsaved)_(Unsaved)_Body2.stl, HomeSecurity-Circuits-B_Cu.dxf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]
2026-08-15 feat: implement settings page, setup instructions, and back navigation
    - Add settings() and setupInstructions() display methods with new
    SETUP_INSTRUCTIONS state
    - Wire touch handlers for settings button, setup button, and back buttons
    on both settings and setup instructions pages
    - Replace log()/Serial.printf() with printf() for consistency
    - Add extern declarations for uisettingspage_map, uihomepageUNarmed_map,
    and uisetupinstructions_map
    - Draw home page on back from settings using uihomepageUNarmed_map sprite
2026-08-15 refactor: split UART frame I/O from pairing payload processing
    - Move receive() and send() from pair_s to uart_s for frame-level I/O
    - Move JSON parsing, NVS storage, and WiFi trigger into pair_s::process()
    - Guard pairing on display state: only allow when on SETUP_INSTRUCTIONS page
    - Reject pairing attempts from other pages with NO ACCESS response
    - Fix duplicate Display display definition (remove from main.cpp)
    - Add extern Display display to display.h
    - Add pair.cpp to CMakeLists.txt
    - Add NO ACCESS handling in httpendpoints.cpp
    - Disable touch debug output during normal operation
    [app_uart.cpp, httpendpoints.cpp, main.cpp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]
2026-08-16 fix: UART sync bytes, WiFi conn detection, pairing endpoint, and doc updates
    UART sync byte fix (both Station and AP):
    - Change sync bytes from 'c'/'8' (ASCII) to 0xAA/0x55 per spec (§9, D16)
    - Prevents false-locking mid-payload when SSID/password contain 'c8'
    WiFi connection result fix (Station):
    - Signal on IP_EVENT_STA_GOT_IP instead of WIFI_EVENT_STA_CONNECTED
    - Association without a leased IP was reporting false success,
    silently killing the alert path with no error surfaced
    - Add xQueueReset(wait_for_wifi_to_connect) in wifi_start() to prevent
    stale queue entries from being consumed as false success
    JSON error handling (Station):
    - jsonparser returns __JSON_ERROR__ on null/empty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
    [app_uart.cpp, httpendpoints.cpp, main.cpp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]
2026-08-16 Started bug tracking and a couple of fixes
    [app_uart.cpp]
2026-08-17 added second revision to the pcb
    [HomeSecurity-Circuits.kicad_pcb, HomeSecurity-Circuits.kicad_sch, HomeSecurity-CircuitsPCB, rev2.kicad_pcb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]
2026-08-17 added keypad wiring
    [HomeSecurity-CircuitsPCB, rev2.kicad_sch]
2026-08-17 feat: add 4x4 keypad scaffolding and implementation plan
    Add keypad module stub (keypad.h/.cpp), wire into CMakeLists and main,
    document GPIO pinout in README (GPIO35–42), and add implementation
    plan (keypadplan.md) covering core scanner, PIN entry overlay, validation,
    and settings integration.
2026-08-19 feat: implement 4x4 keypad driver and split main loop into FreeRTOS tasks
    Add a complete 4x4 matrix keypad driver using GPIO row/column muxing.
    Rows (GPIO39–42) are driven LOW one at a time while columns (GPIO35–38)
    are polled. Each row block holds an active-key while-loop that polls
    until all keys in that row are released, preventing repeated prints
    on held keys.
    A FreeRTOS debounce task receives queue notifications and re-checks
    column state after a 20ms delay.
    Split the main loop into three independent FreeRTOS tasks:
    display_task — display.init() + display.process()
    uart_task — uart.receive()
    keypad_task — keypad.process()
    All tasks run at priority 2 with 4KB st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
    [keypad.cpp, main.cpp]
2026-08-19 refactor: move debounce_task from keypad.cpp to main.cpp
    Move debounce_task and its xTaskCreate out of keypad.cpp into main.cpp.
    The queue handles (what_gpio_to_debounce, keydebounce) and the debounce()
    method remain in keypad.cpp. debounce_task now runs as a standalone
    FreeRTOS task at priority 2 with 4KB stack, matching the pattern used
    by display_task, uart_task, and keypad_task.
2026-08-19 Add Pi branch picker and leftover-state preflight for install/deploy.
    Stop previous Flask/systemd listeners from colliding with a later install, and let the Pi switch git branches from a local menu without a laptop deploy.
2026-08-19 Add motion detection HTTP endpoint and UART relay across AP, Station, and centralconsole firmware
    Adds a new POST /motion endpoint on the central console AP that receives motion event payloads and relays them to the S3 companion firmware via UART. The Station firmware now handles the SENSOR comma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
    Changes span three firmware targets:
    - centralconsole_ap: New api_motion_resp handler registered at /motion, plus SENSOR enum entry in cmd_s
    - centralconsole_Station: SENSOR case added to UART receive dispatch, TFT driver switched to ILI9488, httpendpoints.cpp added to build, factory partition expanded by 512 KB
    - app_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
    [partitions.csv]
2026-08-19 feat: add SentriHome project landing page
    Add the SentriHome project landing page — a scroll-driven showcase site
    for the self-hosted home security system.
    Built with vanilla TypeScript, Vite, and Three.js (no framework):
    - Hero section with project stats (209 commits, 4 contributors, $0 monthly)
    - Scroll-choreographed 3D point cloud morphing between 8 shape targets
    (wordmark, house, network, chip, detection box, shield, cloud, ecosystem)
    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
